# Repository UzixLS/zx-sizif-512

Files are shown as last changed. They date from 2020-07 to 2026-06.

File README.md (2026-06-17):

## Sizif-512
Another CPLD-based ZX Spectrum clone for 48K rubber case with some sweet features.

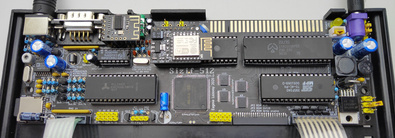
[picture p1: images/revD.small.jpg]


### Tech specs
* Half-sized PCB for 48K rubber case
* Pentagon, Spectrum 128, Spectrum 48 and Spectrum +3e modes
* Altera EPM1270 CPLD
* Real Z80 in 3.5MHz, 4.4MHz, 5.2MHz, 7MHz (no-wait turbo) and 14MHz (turbo with wait-states) modes
* 512K RAM
* Real AY-3-8910 with switchable stereo ABC/ACB/mono output
* Sega 6-button joystick input; Kempston/Sinclair modes
* Integrated DivMMC and Z-Controller, 1x microSD socket
* PAL and RGB video output (Sega Mini-DIN/9 connector)
* Digital video output header for EGA monitors, VGA scandoublers, etc.
* ULAplus
* Mono covox (Pentagon ans SpecDrum standards)
* SounDrive (4-channel stereo covox)
* WiFi addon ([link](https://github.com/UzixLS/zx-sizif-512-wifi))
* Tape input via 3.5" jack and Bluetooth
* 9-12V power supply with any polarity
* Reset and Magic buttons; header for power button

With extension board ([link](https://github.com/UzixLS/zx-sizif-512-ext)) more features may be added:
* Turbo Sound FM
* General Sound (12MHz / 512Kb RAM)
* SAA1099
* MIDI sound

### Demonstration
Running Pentagon and Spectrum 128 demos: [link](https://www.youtube.com/watch?v=_RoLKcfJSTY) \
Playing music from SD: [link](https://www.youtube.com/watch?v=TmikKD3yqOU) \
Some random photos: [link](https://cloud.err200.net/index.php/s/73TR85tYZkMm8Ax?path=%2Fsizif-512) \
Review by Martin's 8-bit blog (in czech): [link](https://www.8bity.cz/2020/zx-spectrum-clone-with-cpld-ulaplus-sizif-512/#) \
Review by The Retro Shack youtube channel: [link](https://www.youtube.com/watch?v=l5IgQTgq_bg) \
Building from scratch experience in Terence Ang's blog: [part1](https://www.terenceang.com/2021/08/28/building-a-zx-spectrum-clone-in-2021-begining/) [part2](https://www.terenceang.com/2021/08/29/building-a-zx-spectrum-clone-in-2021-sourcing-for-parts/) [part3](https://www.terenceang.com/2021/08/31/building-a-zx-spectrum-clone-in-2021-populating-the-board/)

### Magic button
Sizif has a number of configurable parameters that you can change on the fly. To do this just hold Magic button for a second.

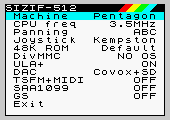
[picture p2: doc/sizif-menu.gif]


To navigate menu you can use up-down keys, to change value use enter or left-right keys. Kempston, Sinclair, Cursor and QAOP supported.

If you press Magic button for a short time, the standard NMI handler 'll be called.

### Sega gamepad buttons
Sega gamepad support will be available starting from PCB rev.D (or Rev.C with slight modifications).
| Button | Function in Kempston mode | Function in Sinclair mode |
| - | - | - |
| Right | Right (bit 0) | 7 |
| Left | Left (bit 1) | 6 |
| Down | Down (bit 2) | 8 |
| Up | Up (bit 3) | 9 |
| A | Button 3 (bit 6) | N |
| B | Button 1 (bit 4) | 0 |
| C | Button 2 (bit 5) | M |
| X | Turbo Button 3 (bit 6) | Turbo N |
| Y | Turbo Button 1 (bit 4) | Turbo 0 |
| Z | Turbo Button 2 (bit 5) | Turbo M |
| Start | Pause | Pause |
| Mode | Magic button | Magic button |

### PS/2 keyboard buttons
| Button | Function |
| - | - |
| F1 | Pause |
| F2 | Fast forward |
| F5 | Magic button |
| F10 | Reboot |
| F12 | Reboot |
| Ctrl+Alt+Del | Reboot |
| Ctrl+Alt+Backspace | Reboot |
| Numpad 8, 2/5, 4, 6 | Joystick's up-down-left-right |
| Numpad 0/Enter | Joystick's fire |
| Alt | Joystick's fire |

### RAM
Sizif contains 512K RAM. There are two cases how to access it:
1. DivMMC enabled (SD card insert) - 128K available via 7FFDh port, 128K via DFFDh (Profi standart, most compatible with old 128K software) and 128K reserved for DivMMC.
2. No SD card present - 128K available via 7FFDh and 384K via DFFDh. Please note: ULAplus and Magic button shares one page of memory with DFFD port. If you run 512K-software, it's good idea not to use ULAplus and Magic.

Note that DFFDh port available only in Pentagon mode.

### SD card
Sizif have preinstalled esxDOS firmware, which provides ability to load TAP, TRD, SCL, Z80 files and save snapshots. To use this you should format SD cart to FAT32 or FAT16 and unpack latest esxDOS release ([link](http://www.esxdos.org/index.html)) to card. Also it's recommended to install Long Filename Browser ([link](https://spectrumcomputing.co.uk/forums/viewtopic.php?t=2553)) to card.

### Tested addons
* [AYX-32](https://github.com/tslabs/arm/tree/master/AYX-32) - OK
* BDI-ZX ver 2.0 MVcomp FDD interface - OK
* [ZX Dandanator! Mini 2.1](http://www.dandare.es/Proyectos_Dandare/ZX_Dandanator%21_Mini_EN.html) - OK
* [ZX TSid](https://github.com/UzixLS/zx-tsid) - OK
* [Multiface 128 1.00 by Steve Smith](http://projectspeccy.com/projects/) - OK (if SD card isn't insert)
* Noname +3DOS floppy controller - OK (since rev.D)
* [PLUS 2A FDD Interface](https://github.com/konkotgit/PLUS-2A-FDD) - OK (since rev.D)
* DivIDE 5.7d - OK (if SD card isn't insert)
* DMA 2.02 by ShamaZX - OK
* [Kempston + TurboSound interface](https://github.com/konkotgit/KTS) - OK
* [ZX-HD](https://www.bytedelight.com/?page_id=1800) - OK
* [ZX-VGA-JOY](http://zx-vga-joy.com/) - OK
* [Spectranet by ByteDelight](https://www.bytedelight.com/?page_id=3515) - OK
* Spectranet by ShamaZX (aka ZX Net 512) - OK
* ZXKit1 VGA converter (with [alternative firmware](https://github.com/UzixLS/zxkit1-vga-scandoubler-firmware)) - OK

### Changelog & current status
* Rev.A - first release. Please note the [errata](pcb/rev.A/ERRATA.ru.txt) (in russian).
* Rev.B - abandoned. Files kept for historical reason.
* Rev.C - BDI has been removed; improved video circuit; more capable CPLD; better power circuit; add mono AY mode. [Errata](pcb/rev.C/ERRATA.txt).
* Rev.C1 - fixed incorrect JTAG pinout; fixed incorrect silkscreen for power connector J3, tuned some circuit values. Everything seems to work. [Errata](pcb/rev.C1/ERRATA.txt).
* Rev.D:
    * added zxbus connector for in-case addons
    * added support for +3DOS floppy controller
    * added support for Sega 3/6-button gamepad
    * added PS/2
    * added Bluetooth tape input (via M18 module)
    * added alternative microSD card socket footprint
    * fixed compatibility with some keyboards
    * modified tape input circuit
* Rev.D1: minor changes in pcb layout
* Rev.E:
    * added fuse on power input
    * added protection diode on 5V power rail
    * rotated left keyboard connector by 180 degrees
    * replaced TRS audio connectors by TRRS with video output
    * changed C37,C38,C39 footprint to able to install film capacitors
    * improved compatibility with wireless sega gamepads - 3.3V power replaced by 5V
    * added ability to simultaneously install the power/reset keys together with the connectors
    * added jumper for wiring minidin-9 pin 4 with composite or sync output for compatibility with dirty scart cables
    * added ability to install full-height 4.43MHz crystal
    * all 0.5/0.3 vias replaced by 0.6/0.3
    * experimental: 74HCU04-based speaker amplifier replaced by LM386-based
    * experimental: 74HCU04-based tape input circuit replaced by LM311-based
    * experimental: 74HCU04-based crystal clock generator replaced by ICS501-based
* Rev.E1:
    * reverted experimental rev.E changes

### Acknowledgments
This work is inspired and based on a lot of other projects and would hardly have been successful without them:
* Harlequin ([link](https://www.facebook.com/groups/349470902442395/))
* Karabas-128 ([link](https://github.com/andykarpov/karabas-128))
* ZX Evolution ([link](http://nedopc.com/zxevo/zxevo.php))
* zx_ula verilog implementation ([link](https://opencores.org/projects/zx_ula))

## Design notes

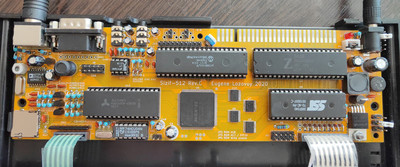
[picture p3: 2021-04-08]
images/revC.small.jpg

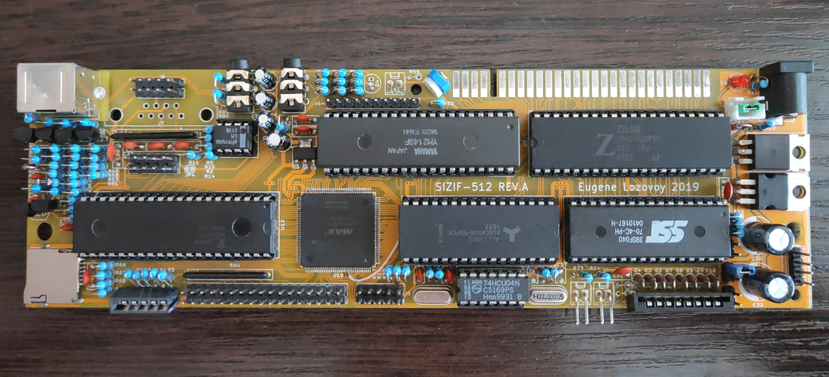
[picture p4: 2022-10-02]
images/revA.webp

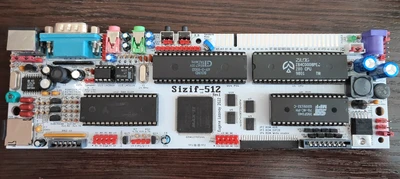
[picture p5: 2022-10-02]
images/revE.small.webp

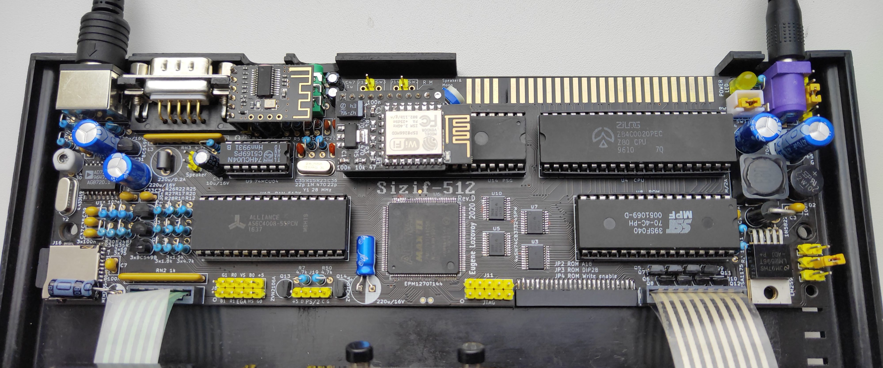
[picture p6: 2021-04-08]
images/revD.jpg

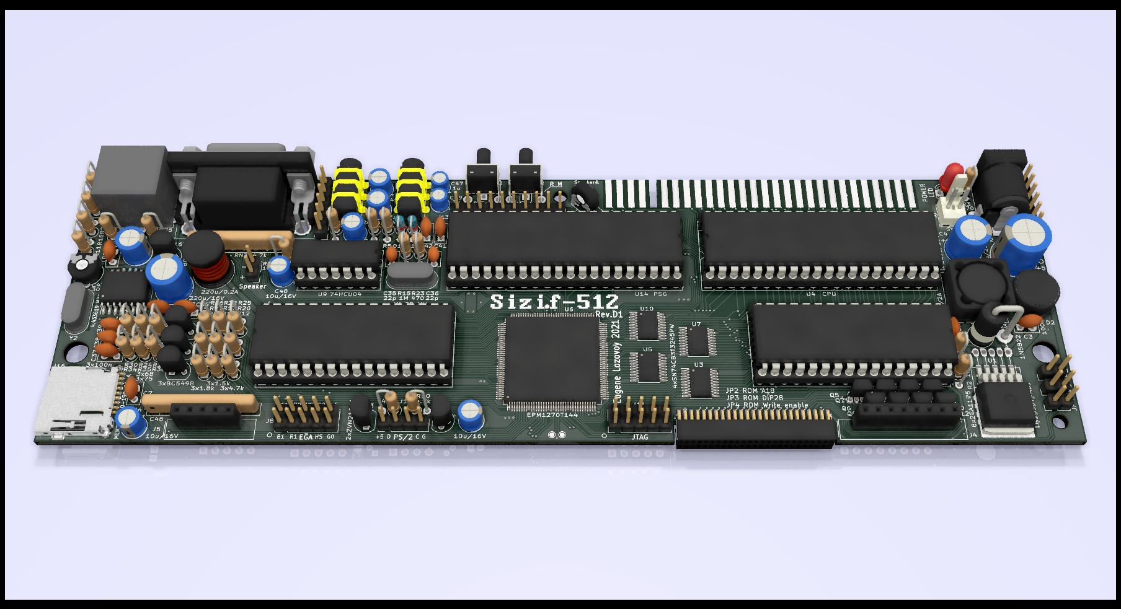
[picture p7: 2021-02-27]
out/pcb3d.rev.D1.png

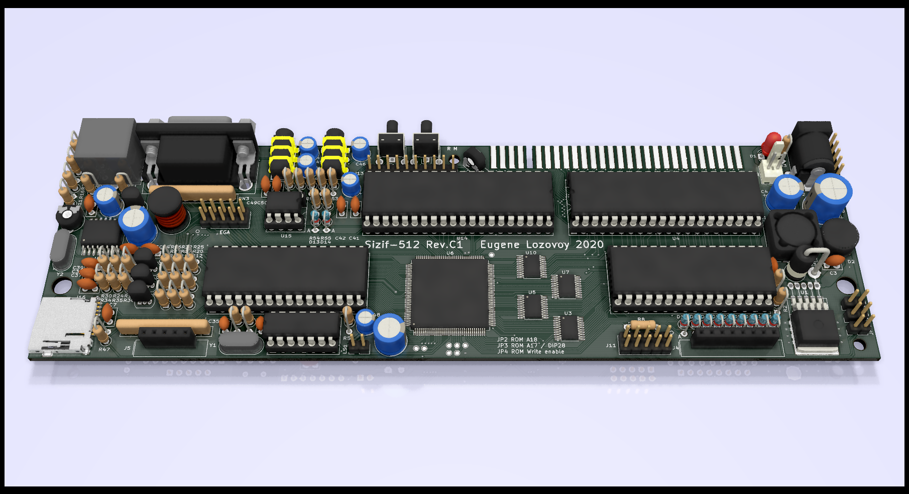
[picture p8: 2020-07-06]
out/pcb3d.rev.C1.png

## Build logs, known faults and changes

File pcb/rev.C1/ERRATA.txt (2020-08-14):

- R5 should not be installed (this improves compatibility with some addons like Dandanator mini)

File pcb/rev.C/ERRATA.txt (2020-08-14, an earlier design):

- JTAG pinout differs from Altera standard
- Incorrect silkscreen for J3 header
- R5 should not be installed (this improves compatibility with some addons like Dandanator mini)

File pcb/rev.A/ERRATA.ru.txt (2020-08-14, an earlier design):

- К ножке 22 микросхемы SRAM (U11) подключен VCC, должен быть GND
- К ножке 6 микросхемы ВГ93 (U12) подключен A8, должен быть A6
- CPUCLK нужно подтянуть к VCC через резистор 2.2k
- RSTCPU нужно подтянуть к VCC через резистор 10k
- Параллельно R71/C41, R72/C42 добавить резисторы 1k на землю, R80, R89 можно не впаивать
- Нерабочая схема подключения динамика, не впаивать Q4, R65, R55, RV1, LS1
- К ножке 132 CPLD (U11) нужно припаять сигнал A13, R41 не впаивать
- Вход магнитофона ловит шумы из космоса, ножку 3 LM311 (U5) нужно притянуть к GND через резистор 3M
- Неверная цоколёвка посадочного места у всех транзисторов - БЭК, должно быть КБЭ
- Разъём клавиатуры J1 не влезает если подключен шлейф флоппи
- Разъём джойстика J7 не влезает в корпус резинки без модификации корпуса
- Резистор R20 мешает установке разъёма клавиатуры J3, нужно припаивать резистор снизу
- Неверная распиновка разъёма J6 (Kempston)
- Неверная распиновка разъёма J8 (EGA)
- Схема сброса: R21 заменить на перемычку, R22 не впаивать
- Разъёмы SW2, SW3 не влезают по высоте, нужно впаивать угловые
- Перепутаны каналы A и B в цоколёвке AY (U13)
- В U4 нет необходимости, можно не запаивать. Ножки 7-6, 11-12, 5-4, 3-2, 9-10, 14-15 соединить перемычками
- C30, C32 не влезают по высоте, нужно устанавливать лёжа

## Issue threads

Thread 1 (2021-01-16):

футпринты транзисторов

andykarpov, 2021-01-16:
поменять бы, если можно, где ноги не так близко друг к другу :)

UzixLS, 2021-01-17:
На алиэкспрессе все BC547/BC549 с обычным, не широким футпринтом. Если поменять футпринт на плате, то придётся заниматься выгибанием ног. Зачем?)

UzixLS, 2021-01-17:
К тому же широкие 2SA1175 (которые в ревизии D на клавиатуре) в принципе не влезут на плату.

andykarpov, 2021-01-17:
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

Я про такой футпринт

andykarpov, 2021-01-17:
> К тому же широкие 2SA1175 (которые в ревизии D на клавиатуре) в принципе не влезут на плату.

А у 1175 ноги и так выгнуты с завода так, что совпадают с КТ361 практически :)

andykarpov, 2021-01-17:
> На алиэкспрессе все BC547/BC549 с обычным, не широким футпринтом. Если поменять футпринт на плате, то придётся заниматься выгибанием ног. Зачем?)

меньше шансов соплю повесить между ногами при монтаже :)

UzixLS, 2021-01-17:
> Я про такой футпринт
> меньше шансов соплю повесить между ногами при монтаже :)

Ок, принято. Будет в ревизии D1.

> А у 1175 ноги и так выгнуты с завода так, что совпадают с КТ361 практически :)

Не у всех. У меня такие https://aliexpress.ru/item/32510168613.html
КМК, вряд ли на их место просто так влезет какой-то больший футпринт:
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

UzixLS, 2021-03-01:
Закрыто коммитом 62a8de51fe858cffeb6807d12b4b5533df3119da

Closed 2021-03-01.

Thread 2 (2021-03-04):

Link for Harlequin

TheStruggleForAntiSpaghetti, 2021-03-04:
It would be nice to link to Don Superfo's Harlequin listing @ Sell My Retro here: (https://www.sellmyretro.com/offer/details/superfo-harlequin-128-zx-spectrum-128k-clone-new-version-4a-pcb-48417)

It also has a link to the schematics, etc.

 This way he will both be credited and possibly earn a buck for all of his work.

UzixLS, 2021-10-02:
Added link to facebook group.
a785ff44d2d07241bd08f201daa745f8490761d9

Closed 2021-10-02.

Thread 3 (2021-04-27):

Не работает клавиатура PS/2.

Alex-TV, 2021-04-27:
Собрал плату, подключил клавиатуру PS/2. При нажатии на клавиши нет реакции. Осциллографом проверил, сигналы от клавиатуры идут, после транзисторов тоже есть сигналы. Реакции на клавиатуру нет.

UzixLS, 2021-04-27:
В прошивке ПЛИС ещё не реализовано.

Alex-TV, 2021-04-27:
Понял, спасибо, буду ждать.

UzixLS, 2021-06-06:
Finally released in ee1f05f1f38bb661430069a9865b5a2dc1e8d80a

Closed 2021-06-06.

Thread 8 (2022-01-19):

RGBS Jitters every few seconds.

terenceang, 2022-01-19:
Hi,

Once again thanks for this great project/

RGBS video jitters every few secs, it happens on both Sizif that I built.
The is sent from the Sizif video out to a GBS=Control upscaler, image is nice, sharp and clean except for the jitters.
Video is in PAL mode and GBS-Control detects it correctly as PAL.
Jitter also doesn't happen with my other game consoles.
Here is a clip of the jitter - https://youtu.be/2h-cfVabX18

Thanks in advance.
Terence

UzixLS, 2022-01-20:
Hello
I've never dealt with GBS. I suppose there is some incompatibility with Pentagon video signal timings, which is going beyond PAL specifications. Can you check in 48K and 128K modes?

terenceang, 2022-01-20:
Actually, The Pentagon timing is the only 1 that works, the others won't even lock.

UzixLS, 2022-01-20:
Ouch, that's unexpected. 48K timings are best in terms of compatibility with TVs.
Are you using latest firmware? How GBS is connected to Sizif? Is your TV/Monitor supports 50Hz? Can you check frequency on 74HCU clock output? There is should be 28 MHz exactly.

terenceang, 2022-01-20:
sadly, the clock is not 28Mhz exactly. it jitters at 27.78, 28.04, 28.09.

terenceang, 2022-01-21:
It think I my 74HCU04 might be the problem, the China seller might have give me 74HC04. Let me double check. Thanks.

terenceang, 2022-01-21:
is the clock out from 74HCU04N supposed to be a Square wave? mine is a sine wave. Ordering some 74HCU04 to try.

UzixLS, 2022-01-21:
This may be caused by oscilloscope bandwidth limitation.

terenceang, 2022-01-21:
I have a RIGOL DS1052E. will it measure 28Mhz properly?

UzixLS, 2022-01-21:
No

Closed 2023-04-04.

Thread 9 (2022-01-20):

8bitdo Retro Receiver locks up the system.

terenceang, 2022-01-20:
https://www.8bitdo.com/retro-receiver-genesis-mega-drive/

Test the Sizif 512K with a Retro Reciever for SEGA MegaDrive crashes and locks up the system. I need to turn the machine on and off to get it back.

UzixLS, 2022-01-20:
Is 3.3V power line stable?

UzixLS, 2022-01-20:
I think this RF dongle maybe drawing too much power. I would buy one for tests probably.

terenceang, 2022-01-20:
where in the world are you located? I can order 1 and have it shipped to you.
It can literally work with any BT controller.
https://download.8bitdo.com/Manual/Receiver/md/MD_RR_ENG_Manual.pdf

UzixLS, 2022-01-20:
This isn't required.

After googling a bit, I found complaints about the compatibility of 8bitdo controllers with zx-uno:
https://www.zxuno.com/forum/viewtopic.php?t=3972

This may be caused by the same reason - zx uno like sizif provides only 3.3V power for gamepad.

terenceang, 2022-01-21:
I tried powering it through USB, it didn’t crash the system when you plug it in and crashes intermittently.
It will be nice if it works, i will order the 2.4Ghz ver to try out. Thanks

terenceang, 2022-01-21:
Anyway, I would love to send 1 to you if you want to work on it, at least to thank you for the hard work and wonderful design.

UzixLS, 2022-03-20:
I bought 8BitDo M30 gamepad with Megadrive Bluetooth receiver and it's works just flawlessly with Sizif-512 (rev.D). So I assume there is some issue with your hardware.

UzixLS, 2022-10-05:
PCB rev.E released with +5 power for gamepad. This should eliminate any theoretical incompatibilities.

Closed 2022-10-05.

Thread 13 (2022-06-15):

Looks like one connection is missing in the PCB Editor?

AmiManga, 2022-06-15:
Looks like there is one connection missing +3V3. PCB Editor is showing white line.
Maybe I am missing something?

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

R.

UzixLS, 2022-06-16:
These 2 pins are connected internally in 1117 ldo. Unfortunately there is no way to tell Kicad "dont worry, its okay".

AmiManga, 2022-06-17:
Got it. I was just checking. :)
Awesome project btw. Great schematics!

Closed 2022-06-17.

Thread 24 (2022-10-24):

Potential Component damage if using long TRRS plugs.

Mr-JimmyDeath, 2022-10-24:
Hello.

Awesome project, I keep getting asked to build these for people so have made a few now.

Whilst building/testing the E1 version I have spotted a potential issue regarding the TRRS connectors. I have found some TRRS plugs that are long enough that when fully inserted will project beyond the end of the PJ-322 socket (J12) and break diodes D11, D15. I have mitigated this issue by fitting SMD diodes under the PCB.

Suggest moving D11, D15 away from back of socket (or using SMD parts).

To a lesser extent this could affect J15 if accidentally plugged in there, so you could also consider moving  R47 & C51.

Thanks, Regards

James

UzixLS, 2022-10-25:
Hello.
Thanks for report.
Could you take a photo with inserted long TRRS plug?

Mr-JimmyDeath, 2022-10-25:
Hello.

Pictures attached are:

1. Comparison with standard 3.5mm Stereo plug
2. Plug fully inserted into socket and projecting beyond. Clearly it won't work like this.
3. My temp solution of SMD Diodes underneath

Regards
James
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

UzixLS, 2022-10-27:
Thanks for detailed photos. I've never seen so long plugs in wild.
Isn't mounted THT diodes would be strong enough to prevent long plug insertion?

Mr-JimmyDeath, 2022-10-29:
Hi.

I was using glass 1N4148 diodes, one broke as soon as I inserted the plug. I did consider mounting them with the lead closest to the socket but then then you would need to insulate the leads to prevent them shorting to the plug which seemed a lot more effort than mounting some underneath.

Regards

James

UzixLS, 2022-11-01:
Accepted, will be fixed in next revision.

andykarpov, 2022-11-03:
BTW, what's the profit to insert a TRRS plug into the normal TRS socket?

Mr-JimmyDeath, 2022-11-03:
There isn't if you are using D1 and earlier boards however, the E1 boards uses TRRS sockets, socket J12 will give you audio L & R plus composite video.

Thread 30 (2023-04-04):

cpld.rev.D.pof PCB ref D

Tomek474, 2023-04-04:
Hello,
I have a problem with cpld.rev.D.pof batch dated 03.04.2023, AY is not working. AY in tests is not detected and the thanks is a terrible noise.

Batch cpld.rev.D.pof dated 30.08.2022 works correctly AY

What is the problem ? has something changed in the wiring diagram ?

Greetings very much

UzixLS, 2023-04-04:
Where did you get all these files from?
Official pof files located at https://github.com/UzixLS/zx-sizif-512/releases , and there is no 03.04.2023 and 30.08.2022 releases.

Tomek474, 2023-04-04:
[AY_cpld.rev.D.zip](https://github.com/UzixLS/zx-sizif-512/files/11152849/AY_cpld.rev.D.zip)

I downloaded the file from GITHUB once when there was no E version yet
and now I noticed that there is a newer pof when there is an E version

I have attached both files, maybe you will be able to recognize what version they are.

Tomek474, 2023-04-04:
it seems to me that v20211204 is AY O.K
and v20221002 is AY BAD
something has changed in Altera software for D version

Tomek474, 2023-04-04:
> Where did you get all these files from? Official pof and rom files located at https://github.com/UzixLS/zx-sizif-512/releases , and there is no 03.04.2023 and 30.08.2022 releases.

it's probably the dates of downloading files by me

UzixLS, 2023-04-05:
I'm not sure why this is happening with your PCB as I haven't had any problems.
There is only one change around AY between v20211204 and v20221002. I reverted it, try this version: [rev_D.zip](https://github.com/UzixLS/zx-sizif-512/files/11155642/rev_D.zip)

Tomek474, 2023-04-05:
I checked, AY works correctly behind the proposed insertion.
Thank you, is this file compatible with Firmware v20221002 ?

UzixLS, 2023-04-06:
Yes, it's based on v20221002, but with reverted commit c26baf8e2c0e4bc6483cb4d750b199ec976fb1f5.
It fixes AY operations when turbo mode enabled, so I don't want to revert this commit in master branch.
I have no idea why it's breaking in your case, probably I should find more various AY chips to reproduce this problem.
Can I ask you to take photo of your AY and Z80?

Closed 2024-10-02.

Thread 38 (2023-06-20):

SVF files

acid-maker, 2023-06-20:
Can you provide SVF files in release page. I have Mac and can program CPLD using OpenOCD, but I need SVF file, not POF file.

acid-maker, 2023-06-20:
Can you provide SVF files in release page. I have Mac and can program CPLD using OpenOCD, but I need SVF file, not POF file.

UzixLS, 2023-06-21:
For which pcb revision you need svf file?

acid-maker, 2023-06-27:
I need SVF file for rev C1. I was able to create one myself using Quartus on Linux machine (it was very old version - 13.0). I've used OpenOCD on Mac and connected Sizif using USBBlaster (cheap version from Ali). Chip has been programmed correctly or at least it seemed so. I've also reprogrammed ROM chip. Everything seemed to be ok at the beginning, but my Sizif became very unstable. Previously it worked fine (I had very old firmware/ROM - the one without OSD), but now I'm unable to set 14Mhz - it freezes totally. 7MHz is max - then when I press right arrow it freezes. Also on standard 3.5MHz it works fine but only for couple of minutes and then it starts to work very unstable. I don't think that my SVF file causes that. I think that a wrong SVF file would rather brick the device. Any ideas? What to check?

Also it would be nice to have SVF files together with POF on your release page for all versions, also in the future. SVF file is "stupid" file with all JTAG "instructions" and therefore can be used with any JTAG programmer and any computer.

UzixLS, 2023-06-29:
May be something wrong with your quartus setup? Try this files:
[cpld firmware](https://github.com/UzixLS/zx-sizif-512/files/11902487/cpld.rev.C.fw-20221002.svf.zip)
[rom image](https://github.com/UzixLS/zx-sizif-512/releases/download/fw-20221002/rom.rev.C.rom)

I think it's good idea to officially provide svf file. I will do this for upcoming releases if I would confirm that SVF file works at least for you.

UzixLS, 2023-09-22:
Closed due to inactivity

Closed 2023-09-22.

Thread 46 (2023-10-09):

BOM in xlsx format (Sizif-512 E1)

Magnetrix, 2023-10-09:
Hello,
PCBWay requires the bom file in xlsx format...
Do you have such file ????

Thank you

UzixLS, 2023-10-09:
There currently is no BOM file suitable for PCBWay assembly service. As far as I know, they need not just an xlsx file, but a specification with part numbers from their own catalog. It would take a lot of time to create it, and I have not interest to do this job.
But you are free to make it yourself using existing pdf or html BOM.

Magnetrix, 2023-11-17:
Thanks anyway

Closed 2023-11-17.

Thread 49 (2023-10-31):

Possible wrong connection in MIC jack (rev E1)

ZbeeGin, 2023-10-31:
I think the MIC jack has wrong _VID_MIC_ connection. The signal goes to the sleeve.
I didn't see any TRRS Jack to 3xRCA AV cable, which have connection like this.

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

IMHO the _VID_MIC_ signal should be connected to the second ring, and GND to the sleeve. Like this:

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

UzixLS, 2023-10-31:
Sizif (like all other my pcbs) uses same pinout as Raspberry Pi for AV cable.
I bought two cables in local store and had no any issues.

ZbeeGin, 2023-11-08:
It seems there are two leading standards for AV Jack connection.
First: **OMTP** where tip is left audio, first ring is right audio, second ring is video(mic) and finally sleeve is the ground.
Second: **CTIA** where audio is the same as above, then second ring is ground and sleeve is the video(mic).

Unofrtunatelly I have only OMTP cable, because there are more of them on the market. At least in my country and nearest stores...

Closed 2024-01-09.

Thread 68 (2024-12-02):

8bit-Do M30 Controller Not Fully Functional

Big-the-Fat, 2024-12-02:
I bought a Sizif-512 (revision E1) with the latest FW on it from eBay.  I tried to use an M30 2.4GHz controller but the MODE button isn't recognised.  Is there a way to remedy this?

UzixLS, 2024-12-02:
I have M30 Bluetooth version and it's forking fine. Not sure what may go wrong with M30 2.4GHz. I would suggest to switch gamepad into different modes (Xinput, Dinput, etc) and, if this does not help, update dongle firmware.

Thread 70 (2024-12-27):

28mhz oscillator

repetto74, 2024-12-27:
Hello,

Is it fine to use a 28.636Mhz oscillator instead of the 28Mhz liste in the BOM for the Sizif512 revision E1?

Thanks
Rick

UzixLS, 2024-12-30:
It's may or may not work depending of your TV-set tolerance.

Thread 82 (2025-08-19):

CPLD-CPU  / data lines

lotharek1977, 2025-08-19:
confirm please : external #FE devices / ps2 keyboard, sinclair joys, Protek/  will not work... as cpld gives  hard 1 on zx bus..  470ohm resistors between cpu/edge and ULA suggested :-) .  or Z output when kd[4:0] no change at FE read

lotharek1977, 2025-08-19:
Please, test external ps2 keyborad adapter... or any device with keybord joy mapped (report from my customer of woodpecker..) works fine in 128/48.  i try to help :-)

https://lotharek.pl/productdetail.php?id=384

andykarpov, 2025-08-21:
Why not to emulate an open collector output by driving **0** by **0** and **1** by **Z** state for the #FE port?
So all external devices will work even without the IORQGE signal handling.
@lotharek1977 , the firmware sources are open, so you can try to implement this and send a pull request here after success :)

UzixLS, 2025-08-21:
> Why not to emulate an open collector output by driving 0 by 0 and 1 by Z state for the #FE port?

Internal CPLD's pullups isn't enough for proper operation in 14MHz mode.

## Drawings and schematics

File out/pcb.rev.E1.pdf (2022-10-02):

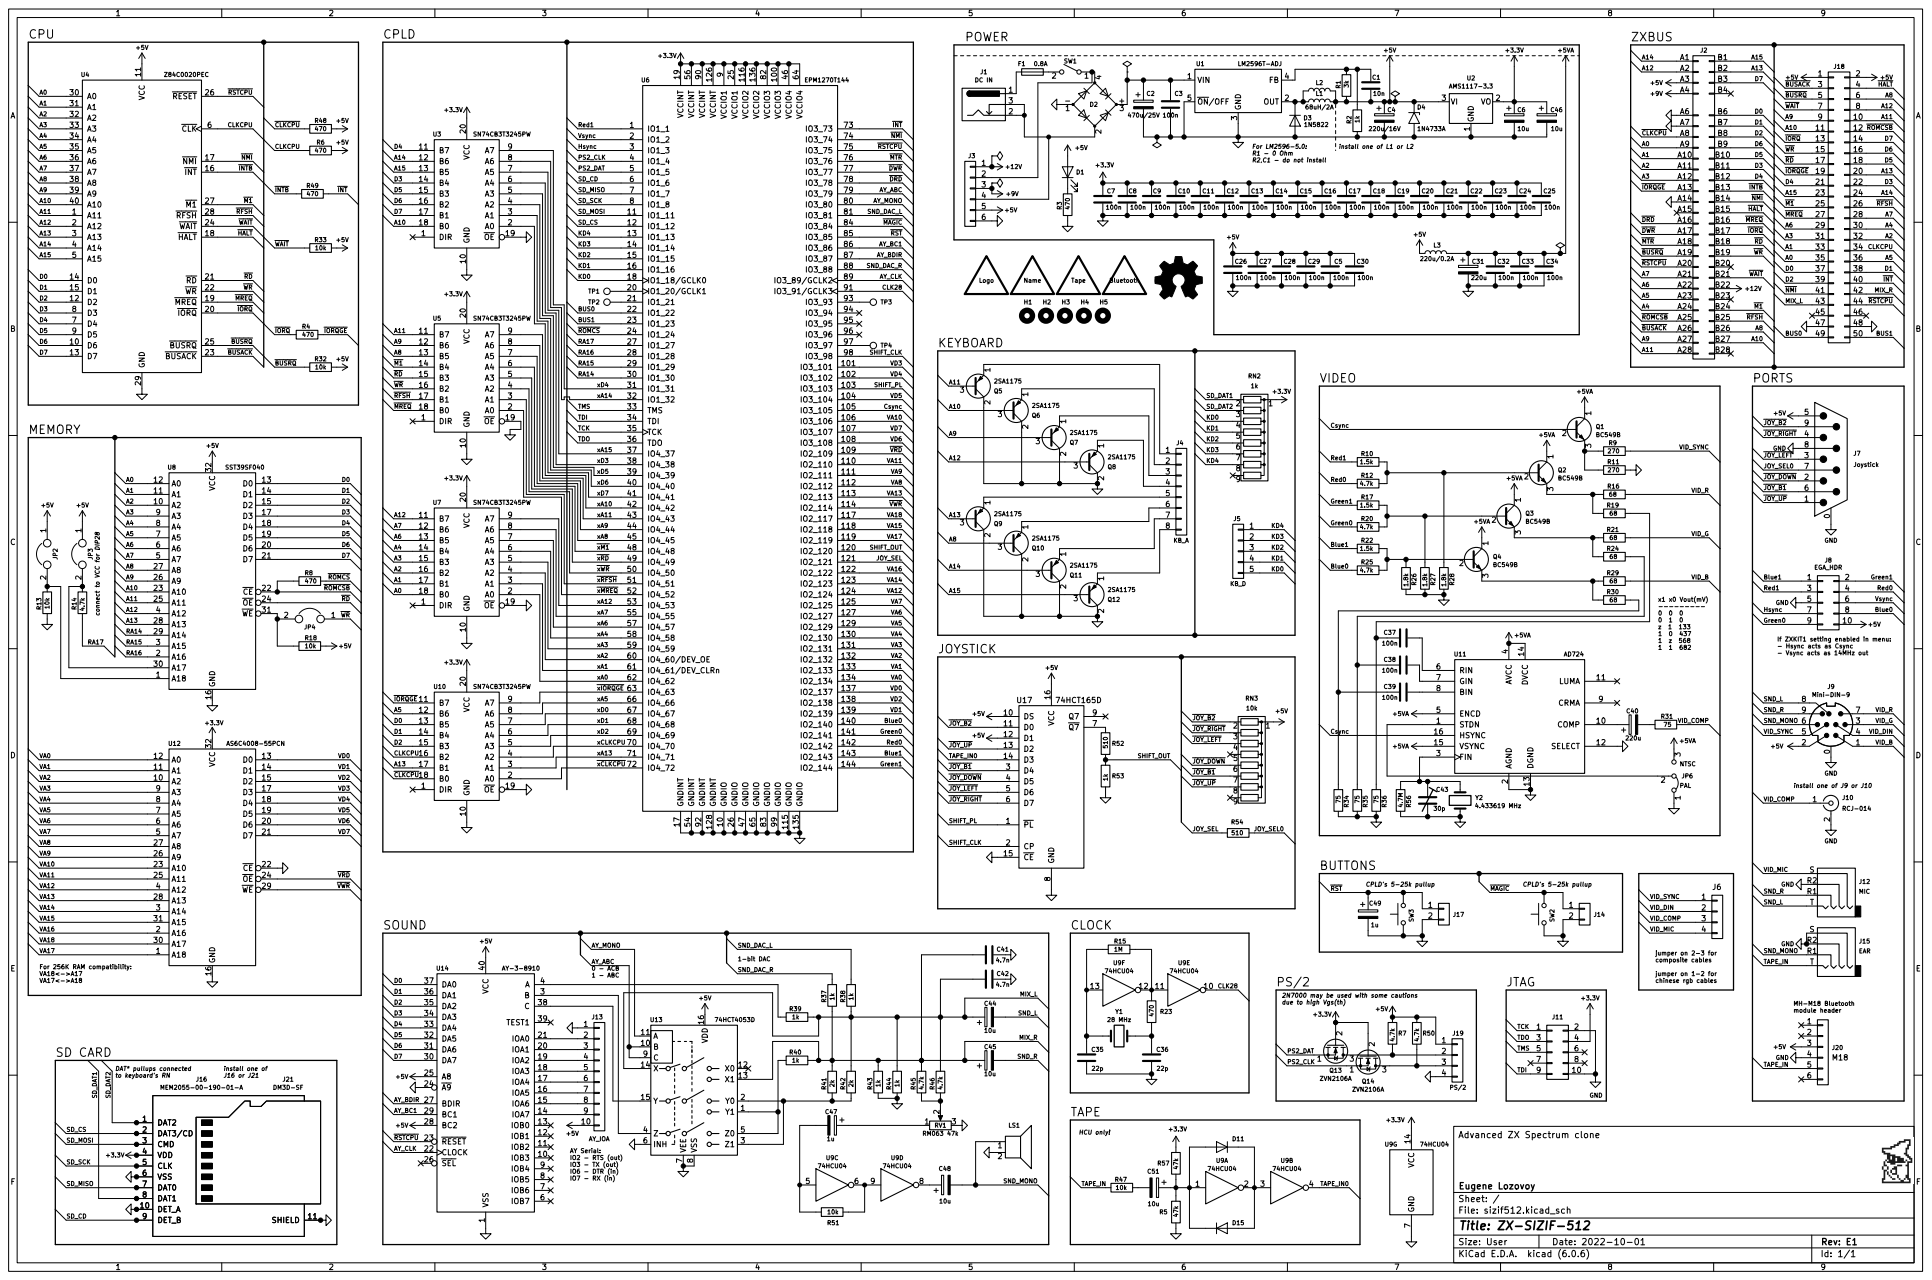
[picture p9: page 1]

install one of L1 or L2

If ZXKIT1 setting enabled in menu:
- Hsync acts as Csync
- Vsync acts as 14MHz out

install one of J9 or J10

2N7000 may be used with some cautions
due to high Vgs(th)

Advanced ZX Spectrum clone

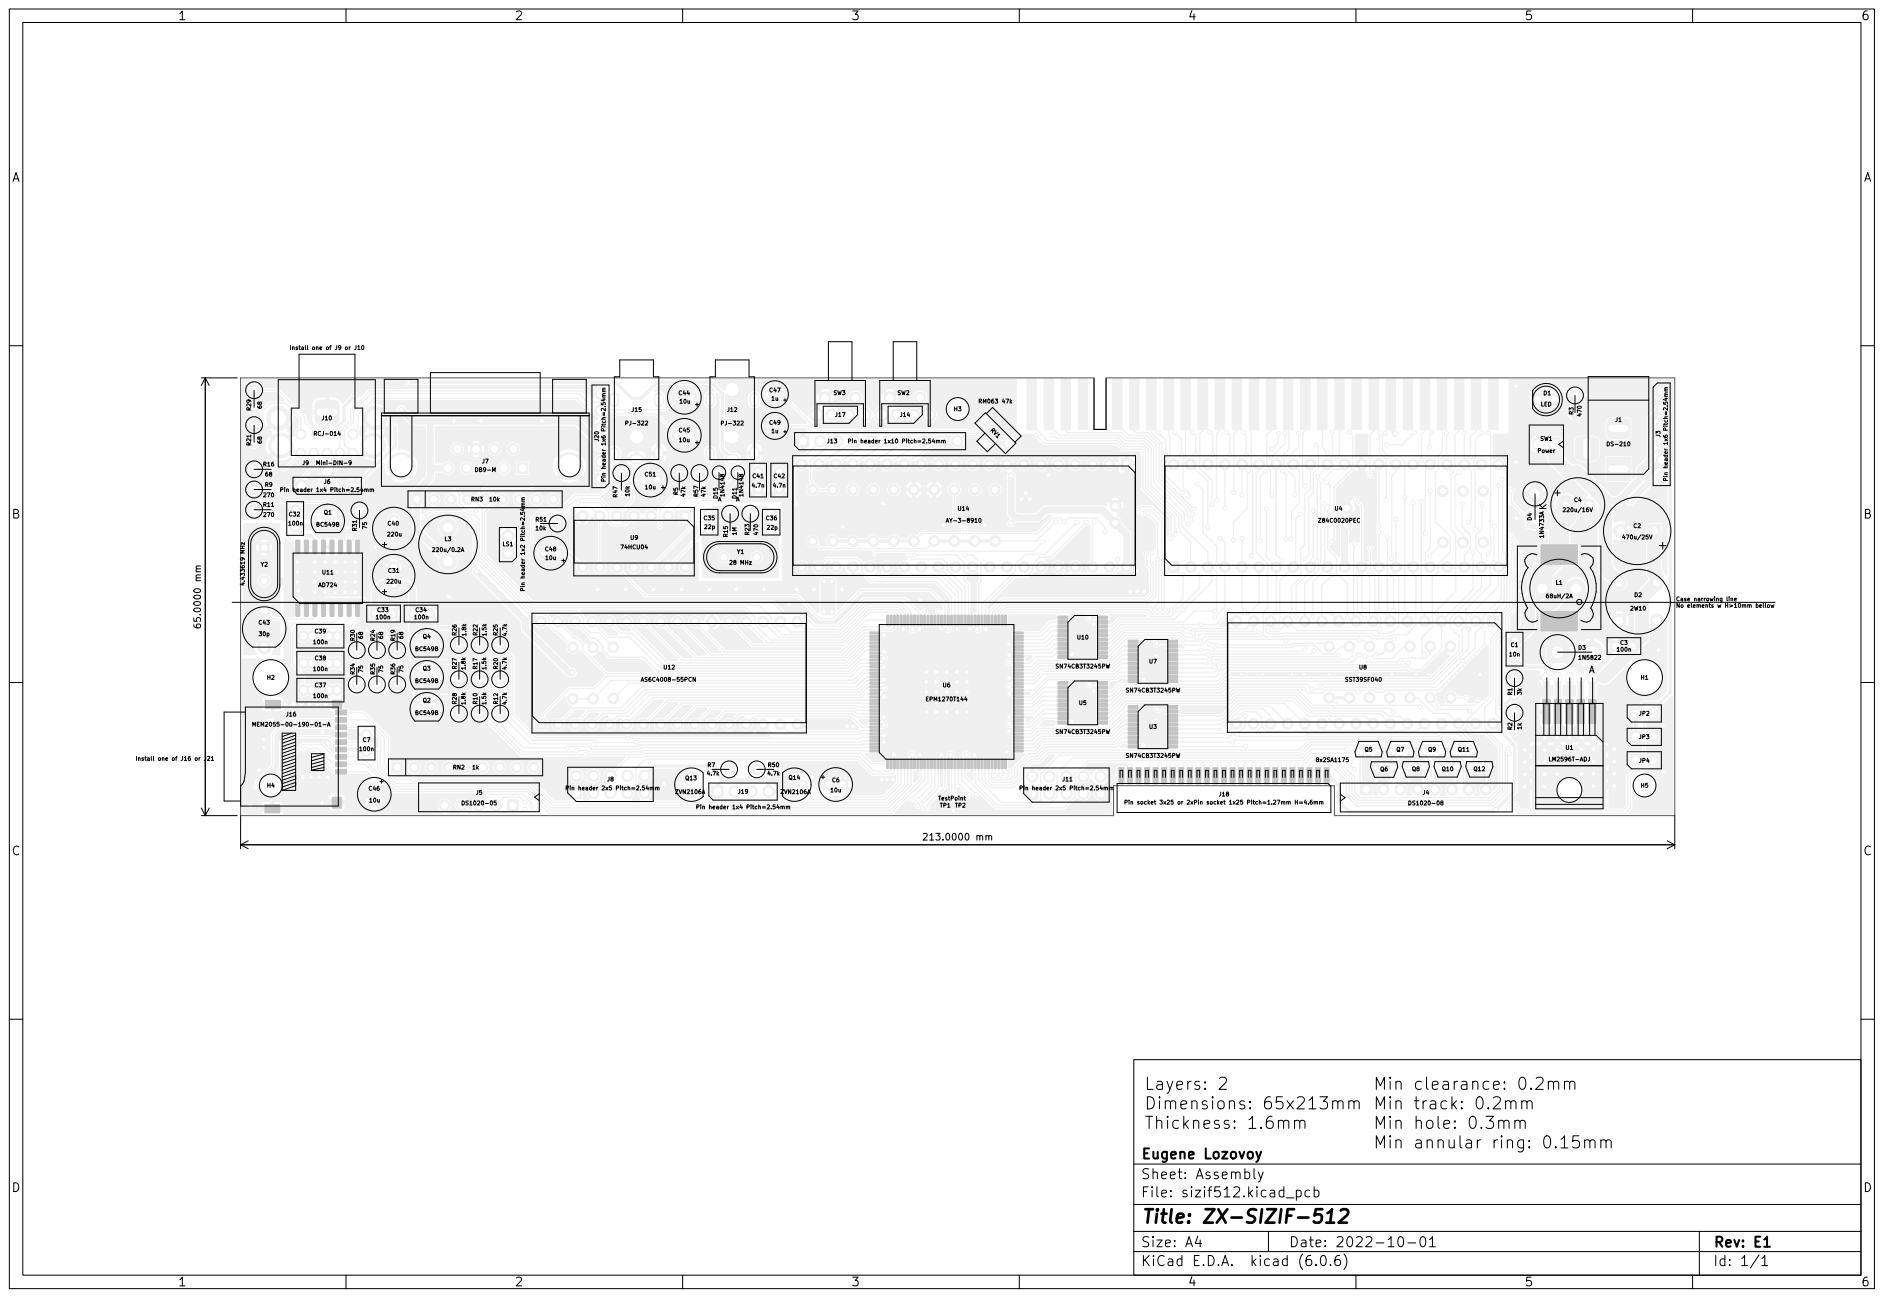
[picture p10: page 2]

Install one of J9 or J10

Install one of J16 or J21

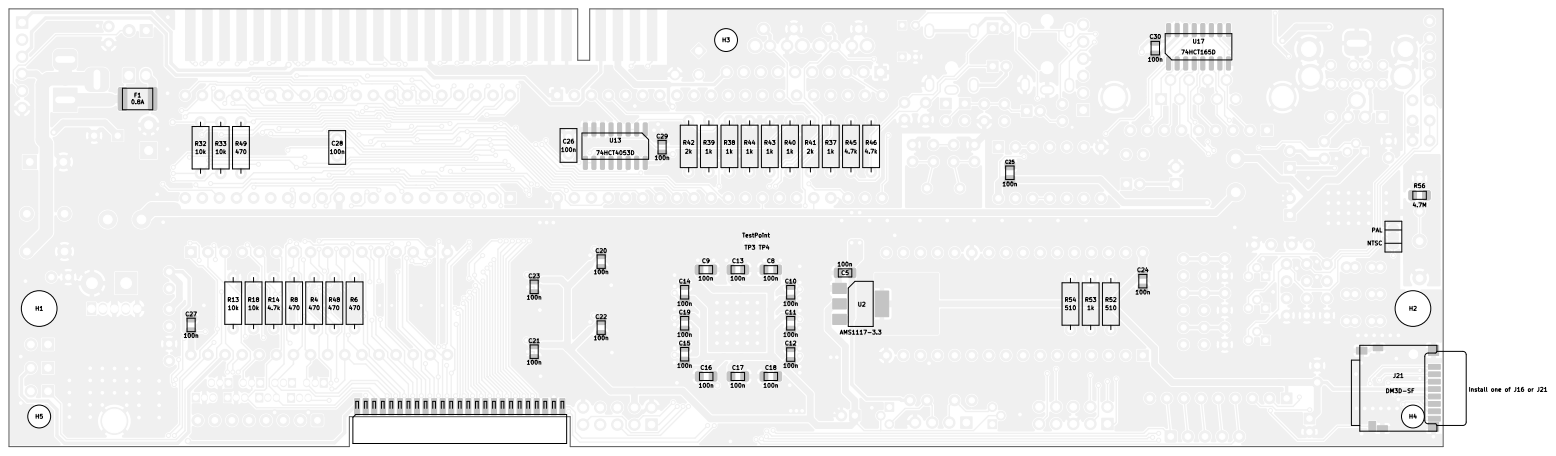
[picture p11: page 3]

R32 10k | R33 10k | R49 470 | C28 100n | U13 74HCT4053D | R42 2k | R39 1k | R38 1k | 1k

Install one of J16 or J21

Designator | Package | Value | Quantity
C1 | C_Disc_D5.0mm_W2.5mm_P2.50mm | 10n | 1
C2 | CP_Radial_D10.0mm_P5.00mm | 470u/25V | 1
C3, C7, C26, C28, C32, C33, C34 | C_Disc_D5.0mm_W2.5mm_P2.50mm | 100n | 7
C4 | CP_Radial_D8.0mm_P3.50mm | 220u/16V | 1
C5, C8, C9, C10, C11, C12, C13, C14, C15, C16, C17, C18, C19, C20, C21, C22, C23, C24, C27, C29 | C_0805_2012Metric_Pad1.15x1.40mm_HandSolder | 100n | 20
C6, C44, C45, C46, C48, C51 | CP_Radial_D5.0mm_P2.00mm | 10u | 6
C25, C30 | C_0805_2012Metric_Pad1.18x1.45mm_HandSolder | 100n | 2
C31, C40 | CP_Radial_D6.3mm_P2.50mm | 220u | 2
C35, C36 | C_Disc_D3.8mm_W2.6mm_P2.50mm | 22p | 2
C37, C38, C39 | C_Rect_L7.0mm_W3.5mm_P2.50mm_P5.00mm | 100n | 3
C41, C42 | C_Disc_D5.0mm_W2.5mm_P2.50mm | 4.7n | 2
C43 | C_Trim_D6.3mm_P5.50mm | 30p | 1
C47, C49 | CP_Radial_D4.0mm_P2.00mm | 1u | 2
D1 | LED_D4.0mm | LED | 1
D2 | Diode_Bridge_Round_D10.0mm | 2W10 | 1
D3 | D_DO-201AD_P5.08mm_Vertical_AnodeUp | 1N5822 | 1
D4 | D_DO-15_P3.81mm_Vertical_KathodeUp | 1N4733A | 1
D11, D15 | D_DO-35_SOD27_P2.54mm_Vertical_AnodeUp | 1N4148 | 2
F1 | Fuse_1812_4532Metric_Pad1.30x3.40mm_HandSolder | 0.8A | 1
J1 | BarrelJack_Horizontal | DS-210 | 1
J3, J20 | PinHeader_1x06_P2.54mm_Vertical | Pin header 1x6 Pitch=2.54mm | 2
J4 | FFC_FPC_1x08 | DS1020-08 | 1
J5 | FFC_FPC_1x05 | DS1020-05 | 1
J6, J19 | PinHeader_1x04_P2.54mm_Vertical | Pin header 1x4 Pitch=2.54mm | 2
J7 | DSUB-9_Male_Horizontal_P2.77x2.84mm_EdgePinOffset4.94mm_H oused_MountingHolesOffset7.48mm | DB9-M | 1
J8, J11 | PinHeader_2x05_P2.54mm_Vertical | Pin header 2x5 Pitch=2.54mm | 2
J9 | minidin-9 | Mini-DIN-9 | 1
J10 | CUI_RCJ-01X-WIDE | RCJ-014 | 1
J12, J15 | PJ-322 | PJ-322 | 2
J13 | PinHeader_1x10_P2.54mm_Vertical | Pin header 1x10 Pitch=2.54mm | 1
J14, J17 | PinHeader_2x01_P2.54mm_Vertical | Pin header 1x2 Pitch=2.54mm | 2
J16 | GCT-MEM2055-00-190-01-A | MEM2055-00-190-01-A | 1
J18 | PinHeader_2x25_P1.27mm_Edge_SMD | Pin socket 3x25 or 2xPin socket 1x25 Pitch=1.27mm H=4.6mm | 1
J21 | microSD_HC_Hirose_DM3D-SF | DM3D-SF | 1
JP2, JP3, JP4 | PinHeader_1x02_P2.54mm_Vertical | Jumper / Pin header 1x2 Pitch=2.54mm | 3
L1 | L_Radial_D8.7mm_P5.00mm_Fastron_07HCP | 68uH/2A | 1
L2 | L_12x12mm_H8mm | 68uH/2A | 1
L3 | L_Radial_D8.7mm_P5.00mm_Fastron_07HCP | 220u/0.2A | 1
LS1 | PinHeader_1x02_P2.54mm_Vertical | Pin header 1x2 Pitch=2.54mm | 1
Q1, Q2, Q3, Q4 | TO-92 | BC549B | 4
Q5, Q6, Q7, Q8, Q9, Q10, Q11, Q12 | TO-92S | 2SA1175 | 8
Q13, Q14 | TO-92 | ZVN2106A | 2
R1 | R_Axial_DIN0207_L6.3mm_D2.5mm_P2.54mm_Vertical | 3k | 1
R2 | R_Axial_DIN0207_L6.3mm_D2.5mm_P2.54mm_Vertical | 1k | 1
R3, R23 | R_Axial_DIN0207_L6.3mm_D2.5mm_P2.54mm_Vertical | 470 | 2
R4, R6, R8, R48, R49 | R_Axial_DIN0207_L6.3mm_D2.5mm_P7.62mm_Horizontal | 470 | 5
R5, R57 | R_Axial_DIN0207_L6.3mm_D2.5mm_P2.54mm_Vertical | 47k | 2
R7, R12, R20, R25, R50 | R_Axial_DIN0207_L6.3mm_D2.5mm_P2.54mm_Vertical | 4.7k | 5
R9, R11 | R_Axial_DIN0207_L6.3mm_D2.5mm_P2.54mm_Vertical | 270 | 2
R10, R17, R22 | R_Axial_DIN0207_L6.3mm_D2.5mm_P2.54mm_Vertical | 1.5k | 3
R13, R18, R32, R33 | R_Axial_DIN0207_L6.3mm_D2.5mm_P7.62mm_Horizontal | 10k | 4
R14, R45, R46 | R_Axial_DIN0207_L6.3mm_D2.5mm_P7.62mm_Horizontal | 4.7k | 3
R15 | R_Axial_DIN0207_L6.3mm_D2.5mm_P2.54mm_Vertical | 1M | 1
R16, R19, R21, R24, R29, R30 | R_Axial_DIN0207_L6.3mm_D2.5mm_P2.54mm_Vertical | 68 | 6
R26, R27, R28 | R_Axial_DIN0207_L6.3mm_D2.5mm_P2.54mm_Vertical | 1.8k | 3
R31, R34, R35, R36 | R_Axial_DIN0207_L6.3mm_D2.5mm_P2.54mm_Vertical | 75 | 4
R37, R38, R39, R40, R43, R44, R53 | R_Axial_DIN0207_L6.3mm_D2.5mm_P7.62mm_Horizontal | 1k | 7
R41, R42 | R_Axial_DIN0207_L6.3mm_D2.5mm_P7.62mm_Horizontal | 2k | 2
R47, R51 | R_Axial_DIN0207_L6.3mm_D2.5mm_P2.54mm_Vertical | 10k | 2
R52, R54 | R_Axial_DIN0207_L6.3mm_D2.5mm_P7.62mm_Horizontal | 510 | 2
R56 | R_0805_2012Metric_Pad1.15x1.40mm_HandSolder | 4.7M | 1
RN2 | R_Array_SIP9 | 1k | 1
RN3 | R_Array_SIP9 | 10k | 1
RV1 | Potentiometer_Runtron_RM-063_Horizontal | RM063 47k | 1
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

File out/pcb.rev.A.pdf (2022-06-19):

CLOCK | KEYBOARD & JOYSTICK
CPU | TAPE INTERFACE

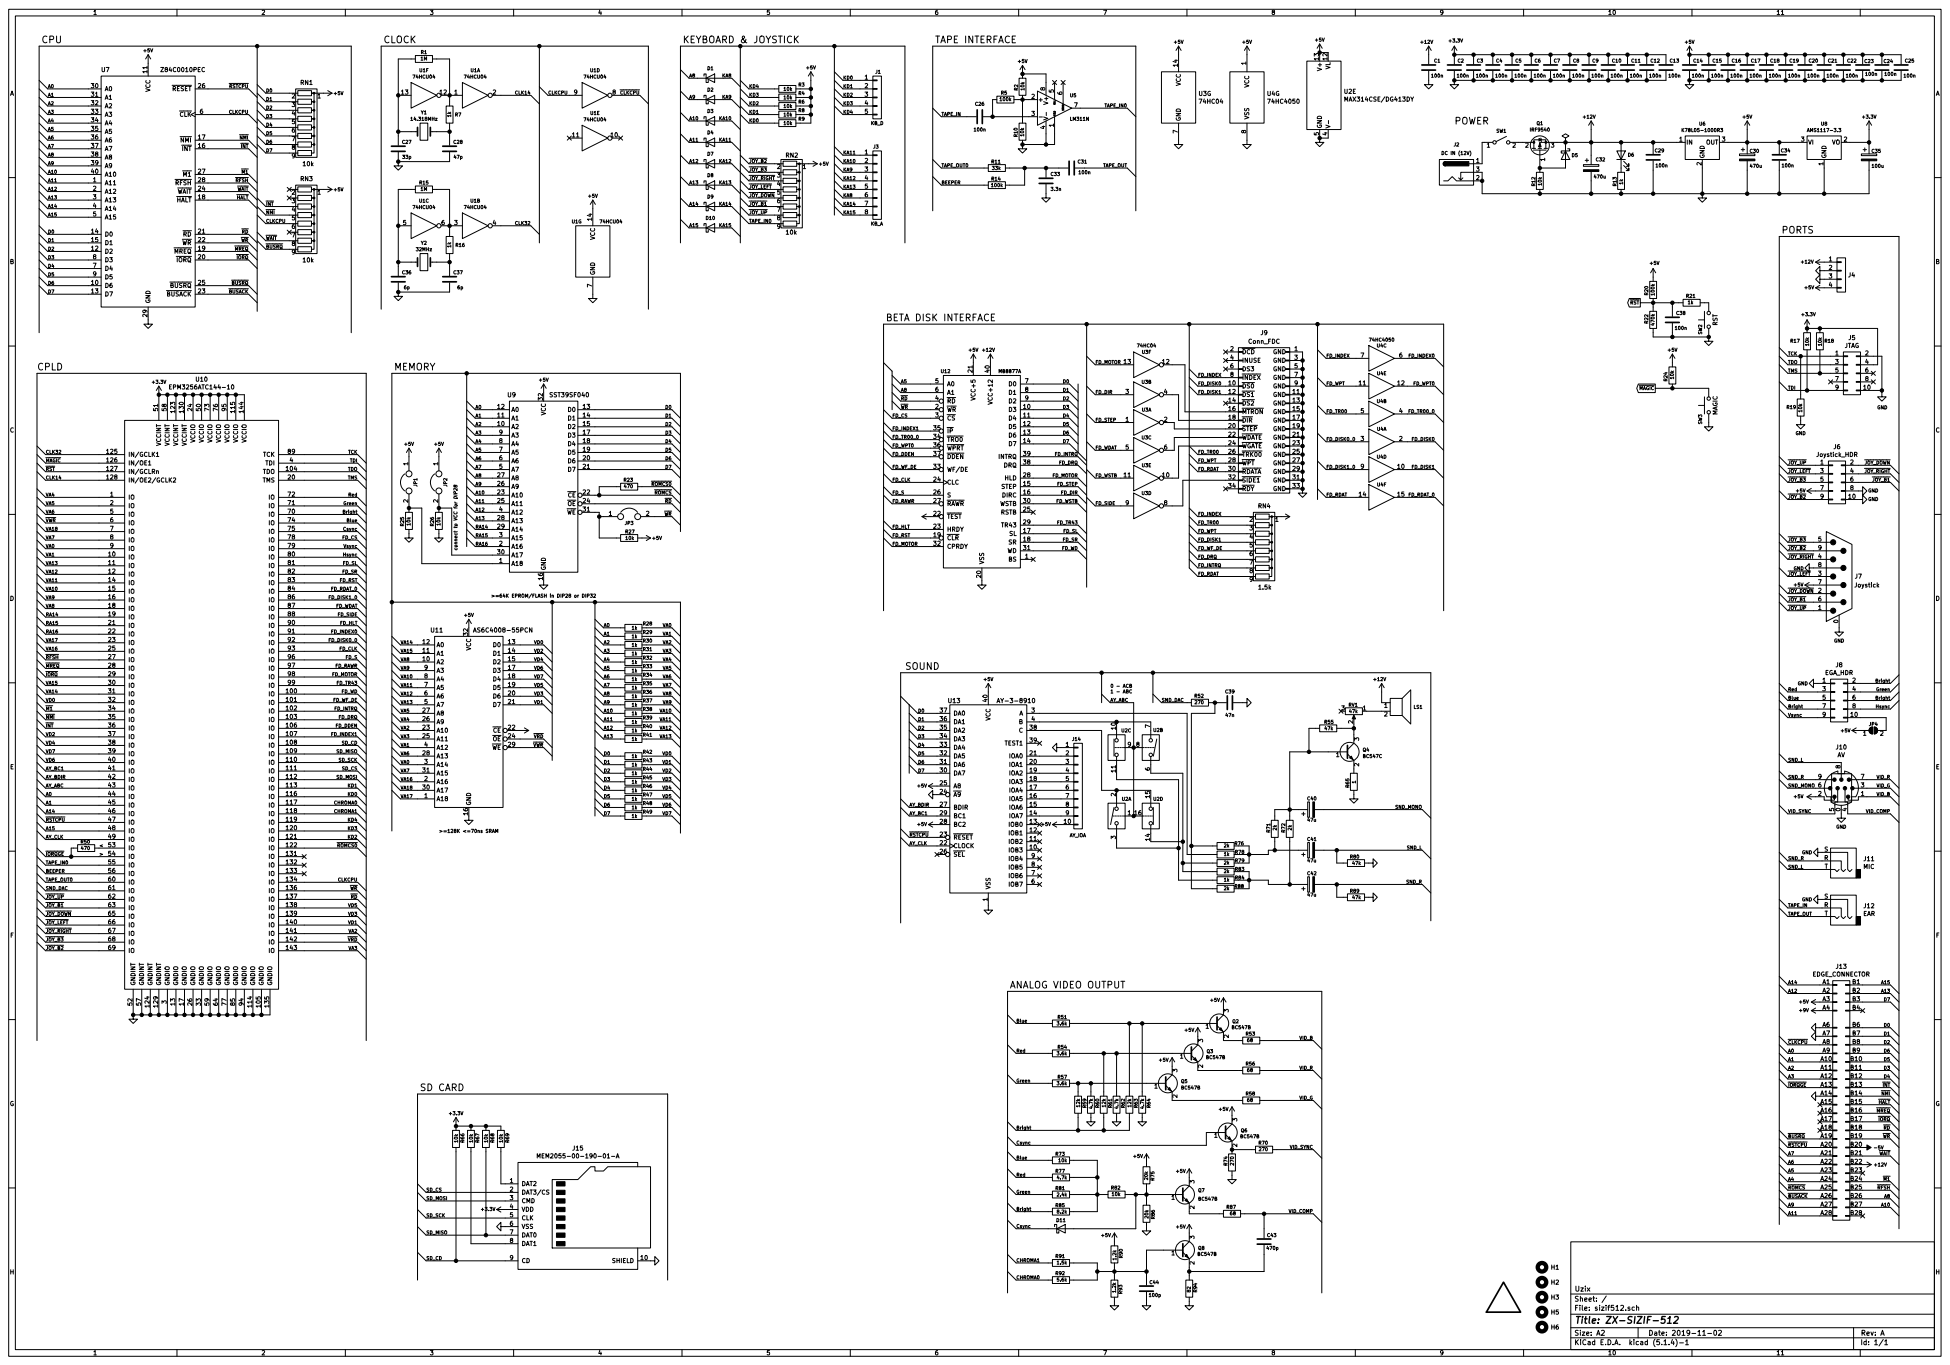
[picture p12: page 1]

connect to VCC for DIP28

>=64K EPROM/FLASH in DIP28 or DIP32

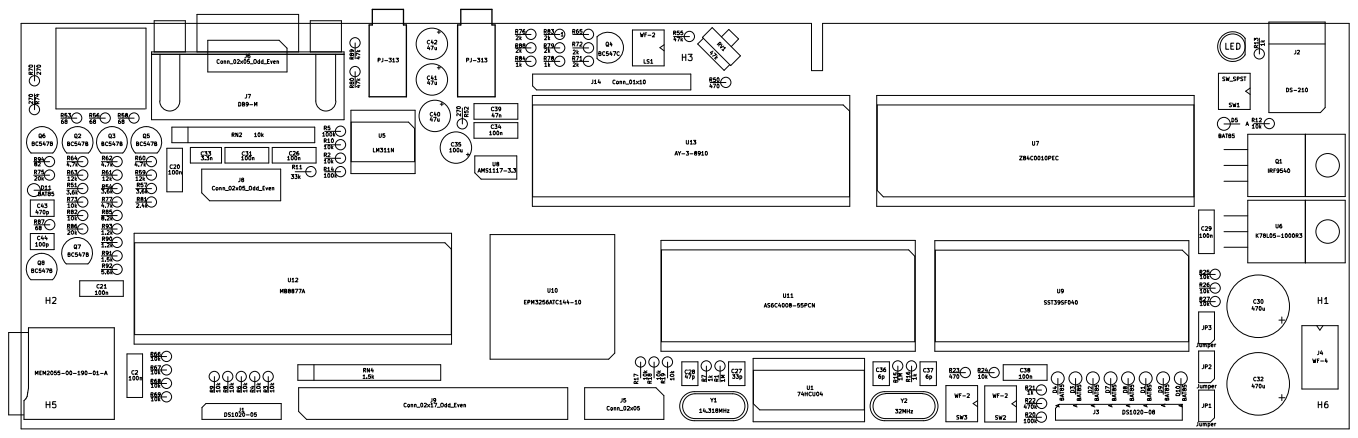
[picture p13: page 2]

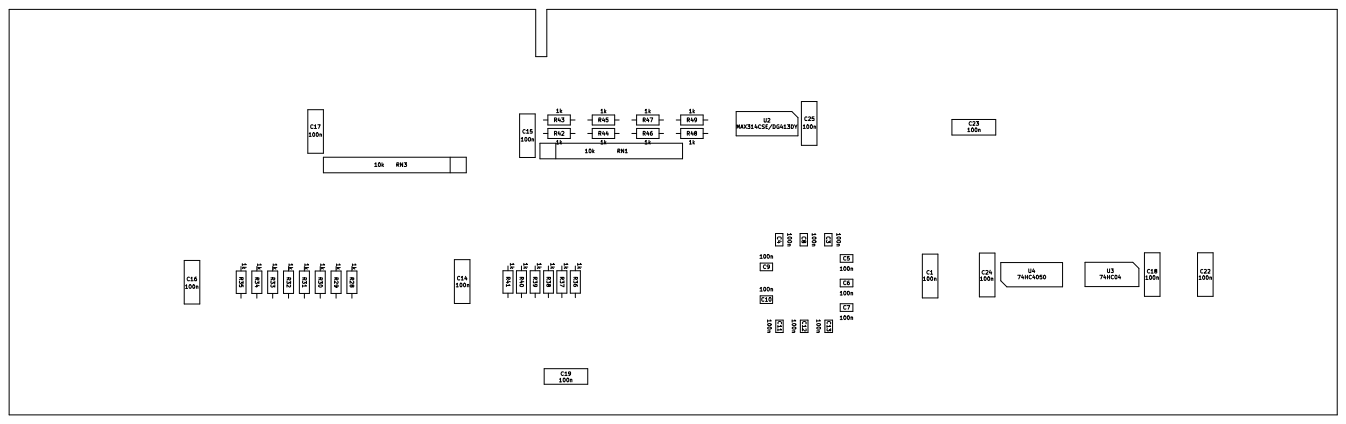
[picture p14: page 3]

Designator | Package | Designation | Quantity
C13,C12,C11,C10,C9,C8,C7,C6,C5,C4,C3 | C_0805_2012Metric_Pad1.15x1.40mm_HandSolder | 100n | 11
C2,C20,C25,C31,C24,C14,C38,C1,C34,C21,C18,C17,C16,C 23,C22,C19,C29,C26,C15 | C_Disc_D7.0mm_W2.5mm_P5.00mm | 100n | 19
C27 | C_Disc_D3.8mm_W2.6mm_P2.50mm | 33p | 1
C28 | C_Disc_D3.8mm_W2.6mm_P2.50mm | 47p | 1
C30,C32 | CP_Radial_D10.0mm_P3.80mm | 470u | 2
C33 | C_Disc_D5.0mm_W2.5mm_P2.50mm | 3.3n | 1
C35 | CP_Radial_D5.0mm_P2.50mm | 100u | 1
C37,C36 | C_Disc_D3.8mm_W2.6mm_P2.50mm | 6p | 2
C39 | C_Disc_D7.0mm_W2.5mm_P5.00mm | 47n | 1
C40,C42,C41 | CP_Radial_D5.0mm_P2.50mm | 47u | 3
C43 | C_Disc_D3.8mm_W2.6mm_P2.50mm | 470p | 1
C44 | C_Disc_D3.8mm_W2.6mm_P2.50mm | 100p | 1
D10,D9,D8,D7,D4,D3,D2,D1,D5,D11 | D_DO-35_SOD27_P2.54mm_Vertical_AnodeUp | BAT85 | 10
D6 | LED_D4.0mm | LED | 1
J1 | PinSocket_1x05_P2.54mm_Vertical | DS1020-05 | 1
J10 | minidin-9 | Mini-DIN-9 | 1
J11,J12 | PJ-313 | PJ-313 | 2
J14 | PinHeader_1x10_P2.54mm_Vertical | Conn_01x10 | 1
J15 | GCT-MEM2055-00-190-01-A | MEM2055-00-190-01-A | 1
J2 | BarrelJack_Horizontal | DS-210 | 1
J3 | PinSocket_1x08_P2.54mm_Vertical | DS1020-08 | 1
J4 | Molex_KK-254_AE-6410-04A_1x04_P2.54mm_Vertical | WF-4 | 1
J5 | PinHeader_2x05_P2.54mm_Vertical | Conn_02x05 | 1
J6,J8 | PinHeader_2x05_P2.54mm_Vertical | Conn_02x05_Odd_Even | 2
J7 | DSUB-9_Male_Horizontal_P2.77x2.84mm_EdgePinOffset4.94mm_Ho used_MountingHolesOffset7.48mm | DB9-M | 1
J9 | PinHeader_2x17_P2.54mm_Vertical | Conn_02x17_Odd_Even | 1
JP2,JP1,JP3 | PinHeader_1x02_P2.54mm_Vertical | Jumper | 3
LS1,SW3,SW2 | Molex_KK-254_AE-6410-02A_1x02_P2.54mm_Vertical | WF-2 | 3
Q1 | TO-220-3_Horizontal_TabDown | IRF9540 | 1
Q4 | TO-92_Inline | BC547C | 1
Q6,Q8,Q7,Q5,Q3,Q2 | TO-92_Inline | BC547B | 6
R11 | R_Axial_DIN0204_L3.6mm_D1.6mm_P2.54mm_Vertical | 33k | 1
R14,R20,R5 | R_Axial_DIN0204_L3.6mm_D1.6mm_P2.54mm_Vertical | 100k | 3
R15,R1 | R_Axial_DIN0204_L3.6mm_D1.6mm_P2.54mm_Vertical | 1M | 2
R22 | R_Axial_DIN0204_L3.6mm_D1.6mm_P2.54mm_Vertical | 470k | 1
R46,R49,R48,R29,R28,R47,R45,R44,R43,R42,R41,R40,R3 9,R38,R37,R36,R35,R34,R33,R32,R31,R30 | R_Axial_DIN0204_L3.6mm_D1.6mm_P5.08mm_Horizontal | 1k | 22
R50,R23 | R_Axial_DIN0204_L3.6mm_D1.6mm_P2.54mm_Vertical | 470 | 2
R52,R70,R74 | R_Axial_DIN0204_L3.6mm_D1.6mm_P2.54mm_Vertical | 270 | 3
R57,R54,R51 | R_Axial_DIN0204_L3.6mm_D1.6mm_P2.54mm_Vertical | 3.6k | 3
R60,R64,R62,R77 | R_Axial_DIN0204_L3.6mm_D1.6mm_P2.54mm_Vertical | 4.7k | 4
R63,R61,R59 | R_Axial_DIN0204_L3.6mm_D1.6mm_P2.54mm_Vertical | 12k | 3
R65 | R_Axial_DIN0204_L3.6mm_D1.6mm_P2.54mm_Vertical | 1 | 1
R66,R69,R68,R67,R24,R9,R8,R6,R4,R3,R27,R26,R25,R12, R10,R2,R18,R17,R19,R82,R73 | R_Axial_DIN0204_L3.6mm_D1.6mm_P2.54mm_Vertical | 10k | 21
R75,R86 | R_Axial_DIN0204_L3.6mm_D1.6mm_P2.54mm_Vertical | 20k | 2
R81 | R_Axial_DIN0204_L3.6mm_D1.6mm_P2.54mm_Vertical | 2.4k | 1
R84,R78,R21,R13,R16,R7 | R_Axial_DIN0204_L3.6mm_D1.6mm_P2.54mm_Vertical | 1k | 6
R85 | R_Axial_DIN0204_L3.6mm_D1.6mm_P2.54mm_Vertical | 8.2k | 1
R87,R53,R56,R58 | R_Axial_DIN0204_L3.6mm_D1.6mm_P2.54mm_Vertical | 68 | 4
R88,R83,R79,R76,R72,R71 | R_Axial_DIN0204_L3.6mm_D1.6mm_P2.54mm_Vertical | 2k | 6
R89,R80,R55 | R_Axial_DIN0204_L3.6mm_D1.6mm_P2.54mm_Vertical | 47k | 3
R91 | R_Axial_DIN0204_L3.6mm_D1.6mm_P2.54mm_Vertical | 1.5k | 1
R92 | R_Axial_DIN0204_L3.6mm_D1.6mm_P2.54mm_Vertical | 5.6k | 1
R93,R90 | R_Axial_DIN0204_L3.6mm_D1.6mm_P2.54mm_Vertical | 1.2k | 2
R94 | R_Axial_DIN0204_L3.6mm_D1.6mm_P2.54mm_Vertical | 82 | 1
RN1,RN2,RN3 | R_Array_SIP9 | 10k | 3
RN4 | R_Array_SIP9 | 1.5k | 1
RV1 | Potentiometer_Runtron_RM-063_Horizontal | 47k | 1
SW1 | Molex_KK-254_AE-6410-02A_1x02_P2.54mm_Vertical | SW_SPST | 1
U1 | DIP-14_W7.62mm_Socket | 74HCU04 | 1
U10 | TQFP-144_20x20mm_P0.5mm | EPM3256ATC144-10 | 1
U11 | DIP-32_W15.24mm_Socket | AS6C4008-55PCN | 1
U12 | DIP-40_W15.24mm_Socket | MB8877A | 1
U13 | DIP-40_W15.24mm_Socket | AY-3-8910 | 1
U2 | SOIC-16_3.9x9.9mm_P1.27mm | MAX314CSE/DG413DY | 1
U3 | SOIC-14_3.9x8.7mm_P1.27mm | 74HC04 | 1
U4 | SOIC-16_3.9x9.9mm_P1.27mm | 74HC4050 | 1
U5 | DIP-8_W7.62mm_Socket | LM311N | 1
U6 | TO-220-3_Horizontal_TabDown | K78L05-1000R3 | 1
U7 | DIP-40_W15.24mm_Socket | Z84C0010PEC | 1
U8 | SOT-223-3_TabPin2 | AMS1117-3.3 | 1
U9 | DIP-32_W15.24mm_Socket | SST39SF040 | 1
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

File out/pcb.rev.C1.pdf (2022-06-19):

# IO1_18/GCLK0 18 VCCINT 19

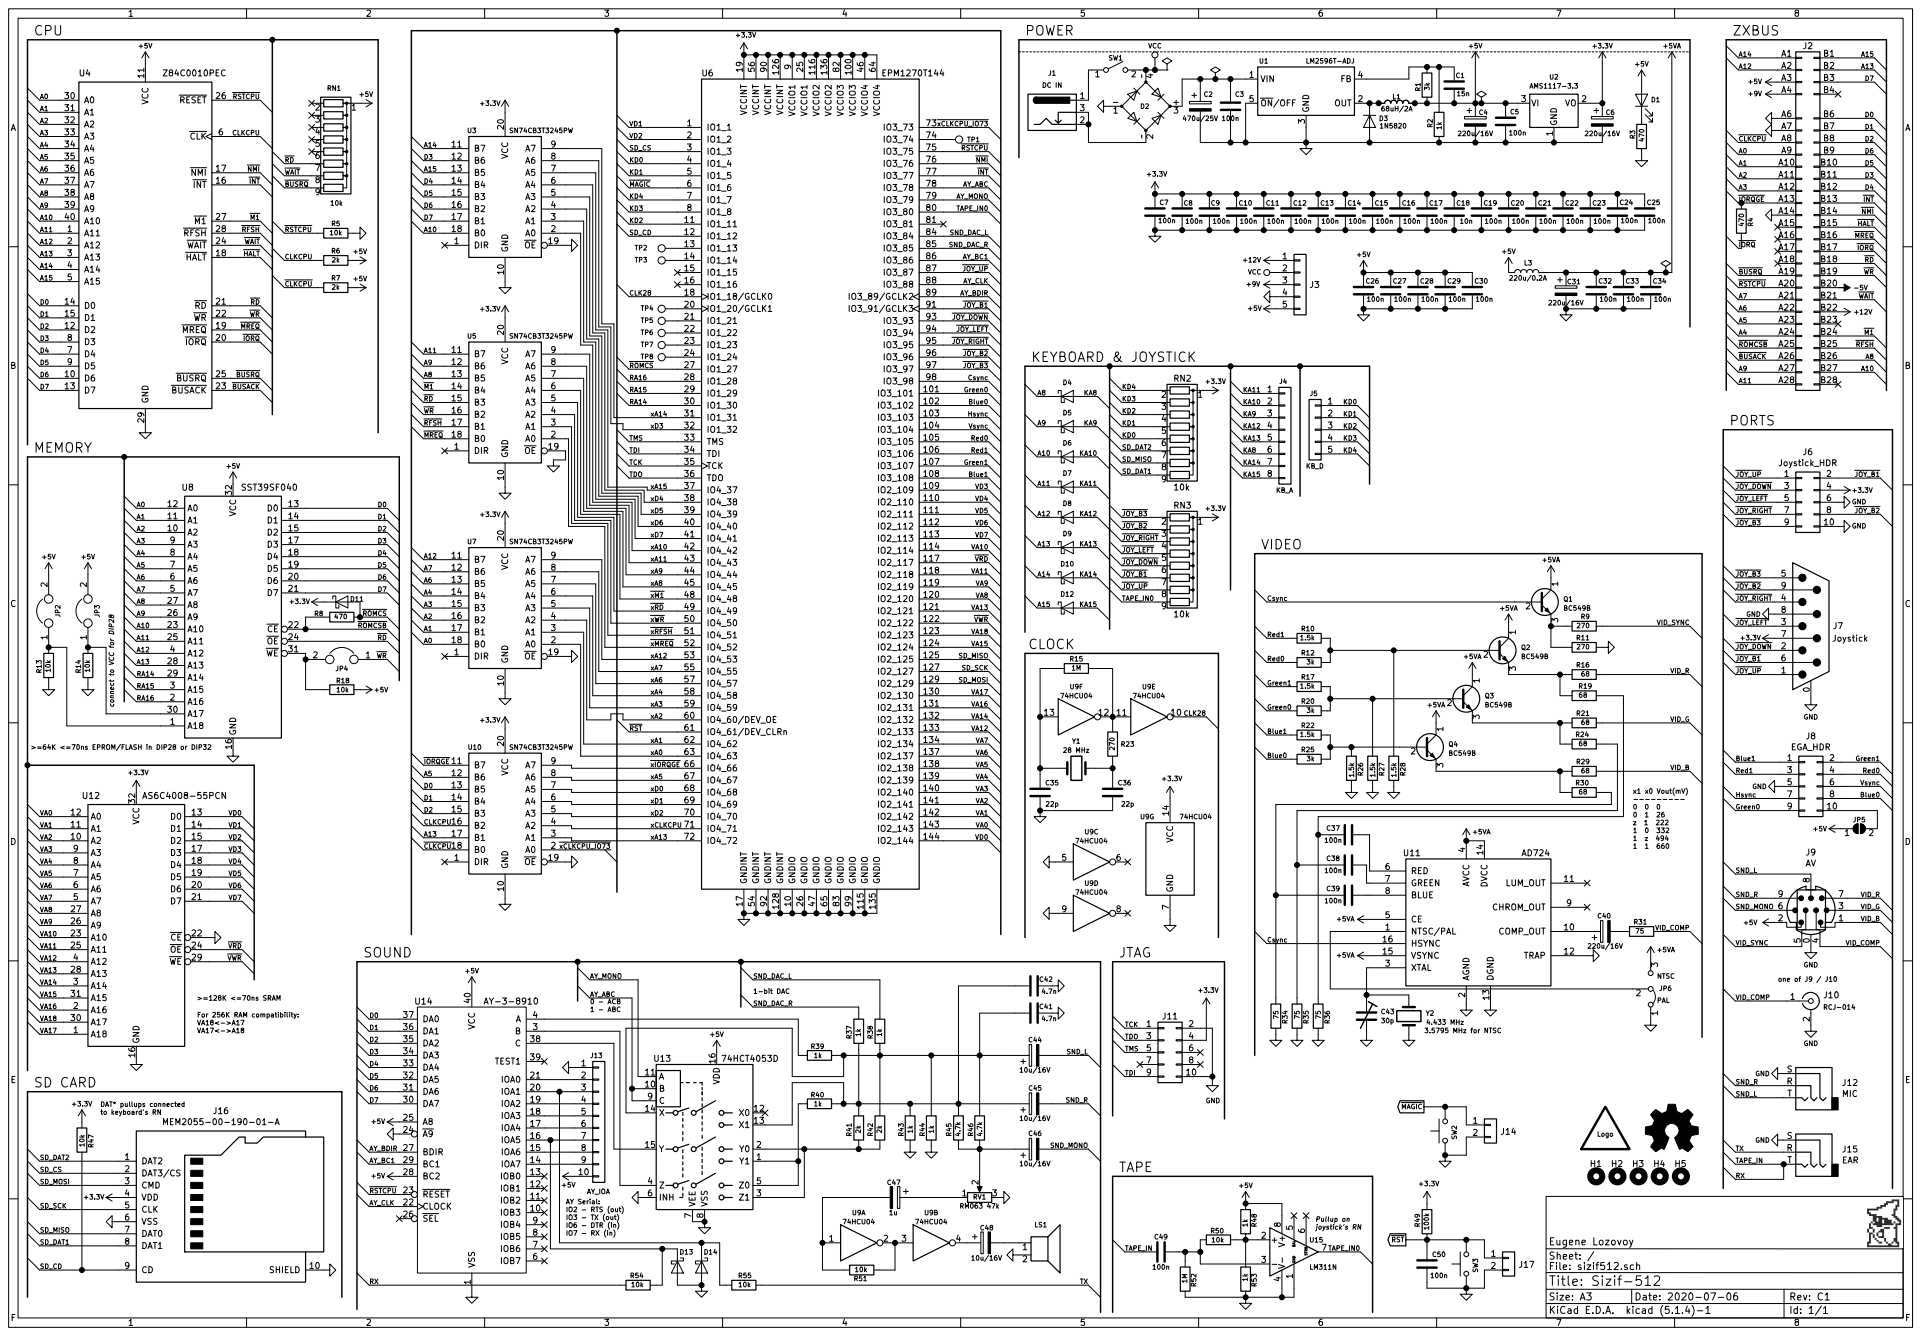
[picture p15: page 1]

connect to VCC for DIP28

>=64K <=70ns EPROM/FLASH in DIP28 or DIP32

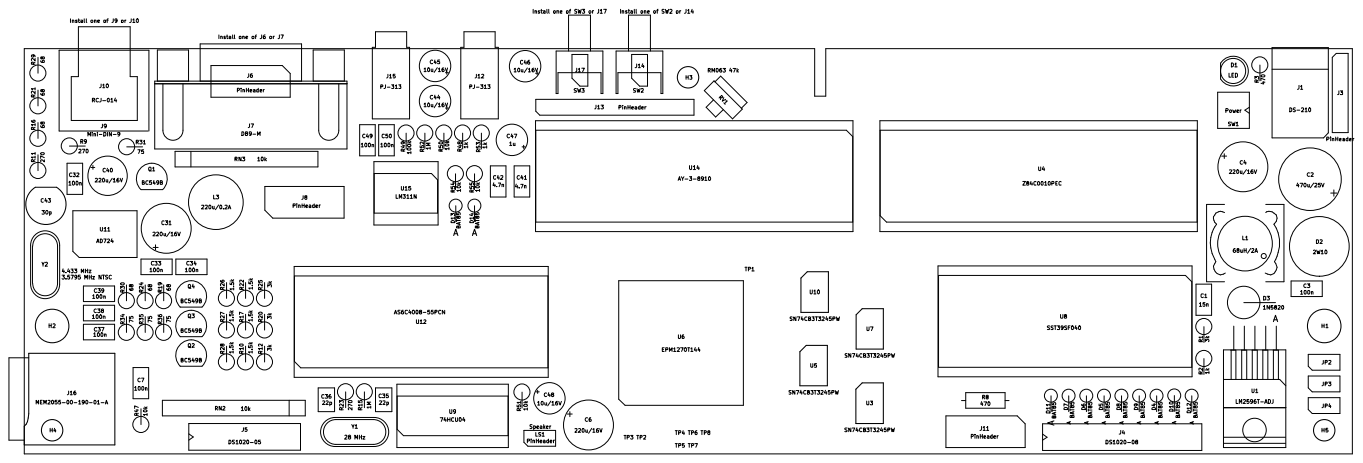
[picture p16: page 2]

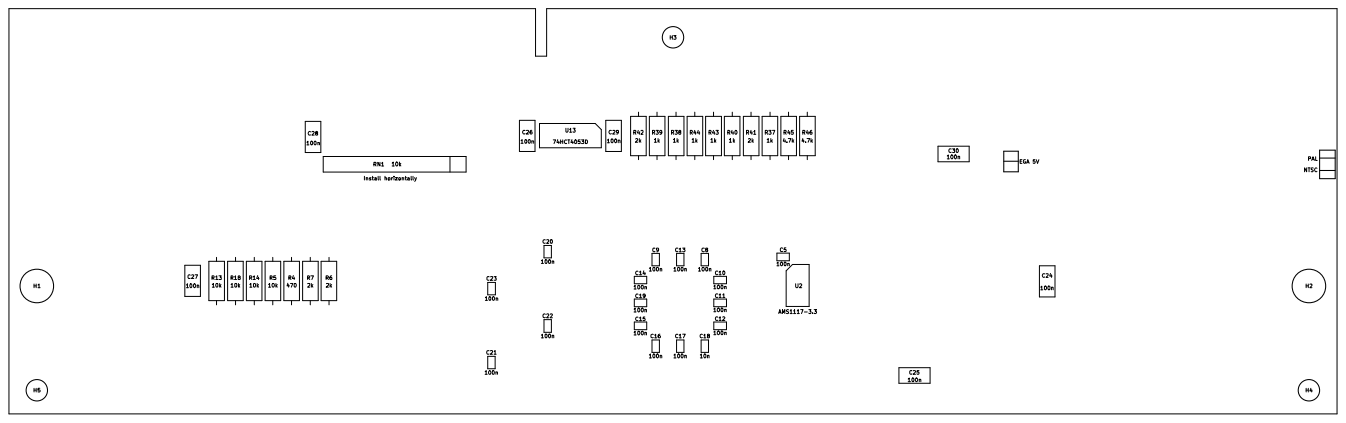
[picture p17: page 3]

Designator | Package | Designation | Quantity
C1 | C_Disc_D5.0mm_W2.5mm_P2.50mm | 15n | 1
C18 | C_0805_2012Metric_Pad1.15x1.40mm_HandSolder | 10n | 1
C2 | CP_Radial_D10.0mm_P5.00mm | 470u/25V | 1
C23,C22,C21,C20,C19,C5,C17,C16,C15,C14,C13,C 12,C11,C10,C9,C8 | C_0805_2012Metric_Pad1.15x1.40mm_HandSolder | 100n | 16
C36,C35 | C_Disc_D3.8mm_W2.6mm_P2.50mm | 22p | 2
C4,C31,C6 | CP_Radial_D8.0mm_P3.50mm | 220u/16V | 3
C40 | CP_Radial_D6.3mm_P2.50mm | 220u/16V | 1
C41,C42 | C_Disc_D5.0mm_W2.5mm_P2.50mm | 4.7n | 2
C43 | C_Trim_D6.3mm_P5.50mm | 30p | 1
C47 | CP_Radial_D5.0mm_P2.00mm | 1u | 1
C48,C46,C45,C44 | CP_Radial_D5.0mm_P2.00mm | 10u/16V | 4
C50,C49,C25,C7,C30,C26,C32,C3,C29,C34,C33,C2 8,C27,C24,C37,C38,C39 | C_Disc_D5.0mm_W2.5mm_P2.50mm | 100n | 17
D1 | LED_D4.0mm | LED | 1
D11,D14,D13,D12,D10,D9,D8,D7,D6,D5,D4 | D_DO-35_SOD27_P2.54mm_Vertical_AnodeUp | BAT85 | 11
D2 | Diode_Bridge_Round_D10.0mm | 2W10 | 1
D3 | D_DO-201AD_P5.08mm_Vertical_AnodeUp | 1N5820 | 1
J1 | BarrelJack_Horizontal | DS-210 | 1
J10 | CUI_RCJ-01X-WIDE | RCJ-014 | 1
J12,J15 | PJ-313 | PJ-313 | 2
J13 | PinHeader_1x10_P2.54mm_Vertical | PinHeader | 1
J14,J17 | PinHeader_2x01_P2.54mm_Vertical | PinHeader | 2
J16 | GCT-MEM2055-00-190-01-A | MEM2055-00-190-01-A | 1
J3 | PinHeader_1x05_P2.54mm_Vertical | PinHeader | 1
J4 | FFC_FPC_1x08 | DS1020-08 | 1
J5 | FFC_FPC_1x05 | DS1020-05 | 1
J6,J8,J11 | PinHeader_2x05_P2.54mm_Vertical | PinHeader | 3
J7 | DSUB-9_Male_Horizontal_P2.77x2.84mm_EdgePinOffset4.94mm_House d_MountingHolesOffset7.48mm | DB9-M | 1
J9 | minidin-9 | Mini-DIN-9 | 1
JP3,JP4,JP2 | PinHeader_1x02_P2.54mm_Vertical | Jumper | 3
L1 | L_Radial_D8.7mm_P5.00mm_Fastron_07HCP | 68uH/2A | 1
L3 | L_Radial_D8.7mm_P5.00mm_Fastron_07HCP | 220u/0.2A | 1
LS1 | PinHeader_1x02_P2.54mm_Vertical | PinHeader | 1
Q4,Q3,Q2,Q1 | TO-92_Inline | BC549B | 4
R1,R25,R20,R12 | R_Axial_DIN0207_L6.3mm_D2.5mm_P2.54mm_Vertical | 3k | 4
R11,R9,R23 | R_Axial_DIN0207_L6.3mm_D2.5mm_P2.54mm_Vertical | 270 | 3
R18,R5,R14,R13 | R_Axial_DIN0207_L6.3mm_D2.5mm_P7.62mm_Horizontal | 10k | 4
R2,R53,R48 | R_Axial_DIN0207_L6.3mm_D2.5mm_P2.54mm_Vertical | 1k | 3
R28,R27,R26,R22,R17,R10 | R_Axial_DIN0207_L6.3mm_D2.5mm_P2.54mm_Vertical | 1.5k | 6
R29,R16,R21,R30,R24,R19 | R_Axial_DIN0207_L6.3mm_D2.5mm_P2.54mm_Vertical | 68 | 6
R3 | R_Axial_DIN0207_L6.3mm_D2.5mm_P2.54mm_Vertical | 470 | 1
R34,R35,R36,R31 | R_Axial_DIN0207_L6.3mm_D2.5mm_P2.54mm_Vertical | 75 | 4
R44,R43,R40,R39,R38,R37 | R_Axial_DIN0207_L6.3mm_D2.5mm_P7.62mm_Horizontal | 1k | 6
R46,R45 | R_Axial_DIN0207_L6.3mm_D2.5mm_P7.62mm_Horizontal | 4.7k | 2
R49 | R_Axial_DIN0207_L6.3mm_D2.5mm_P2.54mm_Vertical | 100k | 1
R50,R54,R55,R47,R51 | R_Axial_DIN0207_L6.3mm_D2.5mm_P2.54mm_Vertical | 10k | 5
R52,R15 | R_Axial_DIN0207_L6.3mm_D2.5mm_P2.54mm_Vertical | 1M | 2
R7,R6,R42,R41 | R_Axial_DIN0207_L6.3mm_D2.5mm_P7.62mm_Horizontal | 2k | 4
R8,R4 | R_Axial_DIN0207_L6.3mm_D2.5mm_P7.62mm_Horizontal | 470 | 2
RN2,RN3,RN1 | R_Array_SIP9 | 10k | 3
RV1 | Potentiometer_Runtron_RM-063_Horizontal | RM063 47k | 1
SW1 | Molex_KK-254_AE-6410-02A_1x02_P2.54mm_Vertical | Jumper | 1
SW2,SW3 | SW_Tactile_SPST_Angled_PTS645Vx83-2LFS | Button THT | 2
TP2,TP3,TP1,TP8,TP7,TP6,TP5,TP4 | TestPoint_Pad_D1.0mm | TestPoint | 8
U1 | TO-220-263-5_Horizontal_TabDown | LM2596T-ADJ | 1
U11 | SOIC-16W_7.5x10.3mm_P1.27mm | AD724 | 1
U12 | DIP-32_W15.24mm_Socket | AS6C4008-55PCN | 1
U13 | SOIC-16_3.9x9.9mm_P1.27mm | 74HCT4053D | 1
U14 | DIP-40_W15.24mm_Socket | AY-3-8910 | 1
U15 | DIP-8_W7.62mm_Socket | LM311N | 1
U2 | SOT-223-3_TabPin2 | AMS1117-3.3 | 1
U3,U10,U5,U7 | TSSOP-20_4.4x6.5mm_P0.65mm | SN74CB3T3245PW | 4
U4 | DIP-40_W15.24mm_Socket | Z84C0010PEC | 1
U6 | LQFP-144_20x20mm_P0.5mm | EPM1270T144 | 1
U8 | DIP-32_W15.24mm_Socket | SST39SF040 | 1
U9 | DIP-14_W7.62mm_Socket | 74HCU04 | 1
Y1 | Crystal_HC49-U_Vertical | 28 MHz | 1
Y2 | Crystal_HC49-U_Vertical | 4.433 MHz | 1

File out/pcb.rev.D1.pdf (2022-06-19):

# IO1_18/GCLK0 18 VCCINT 19

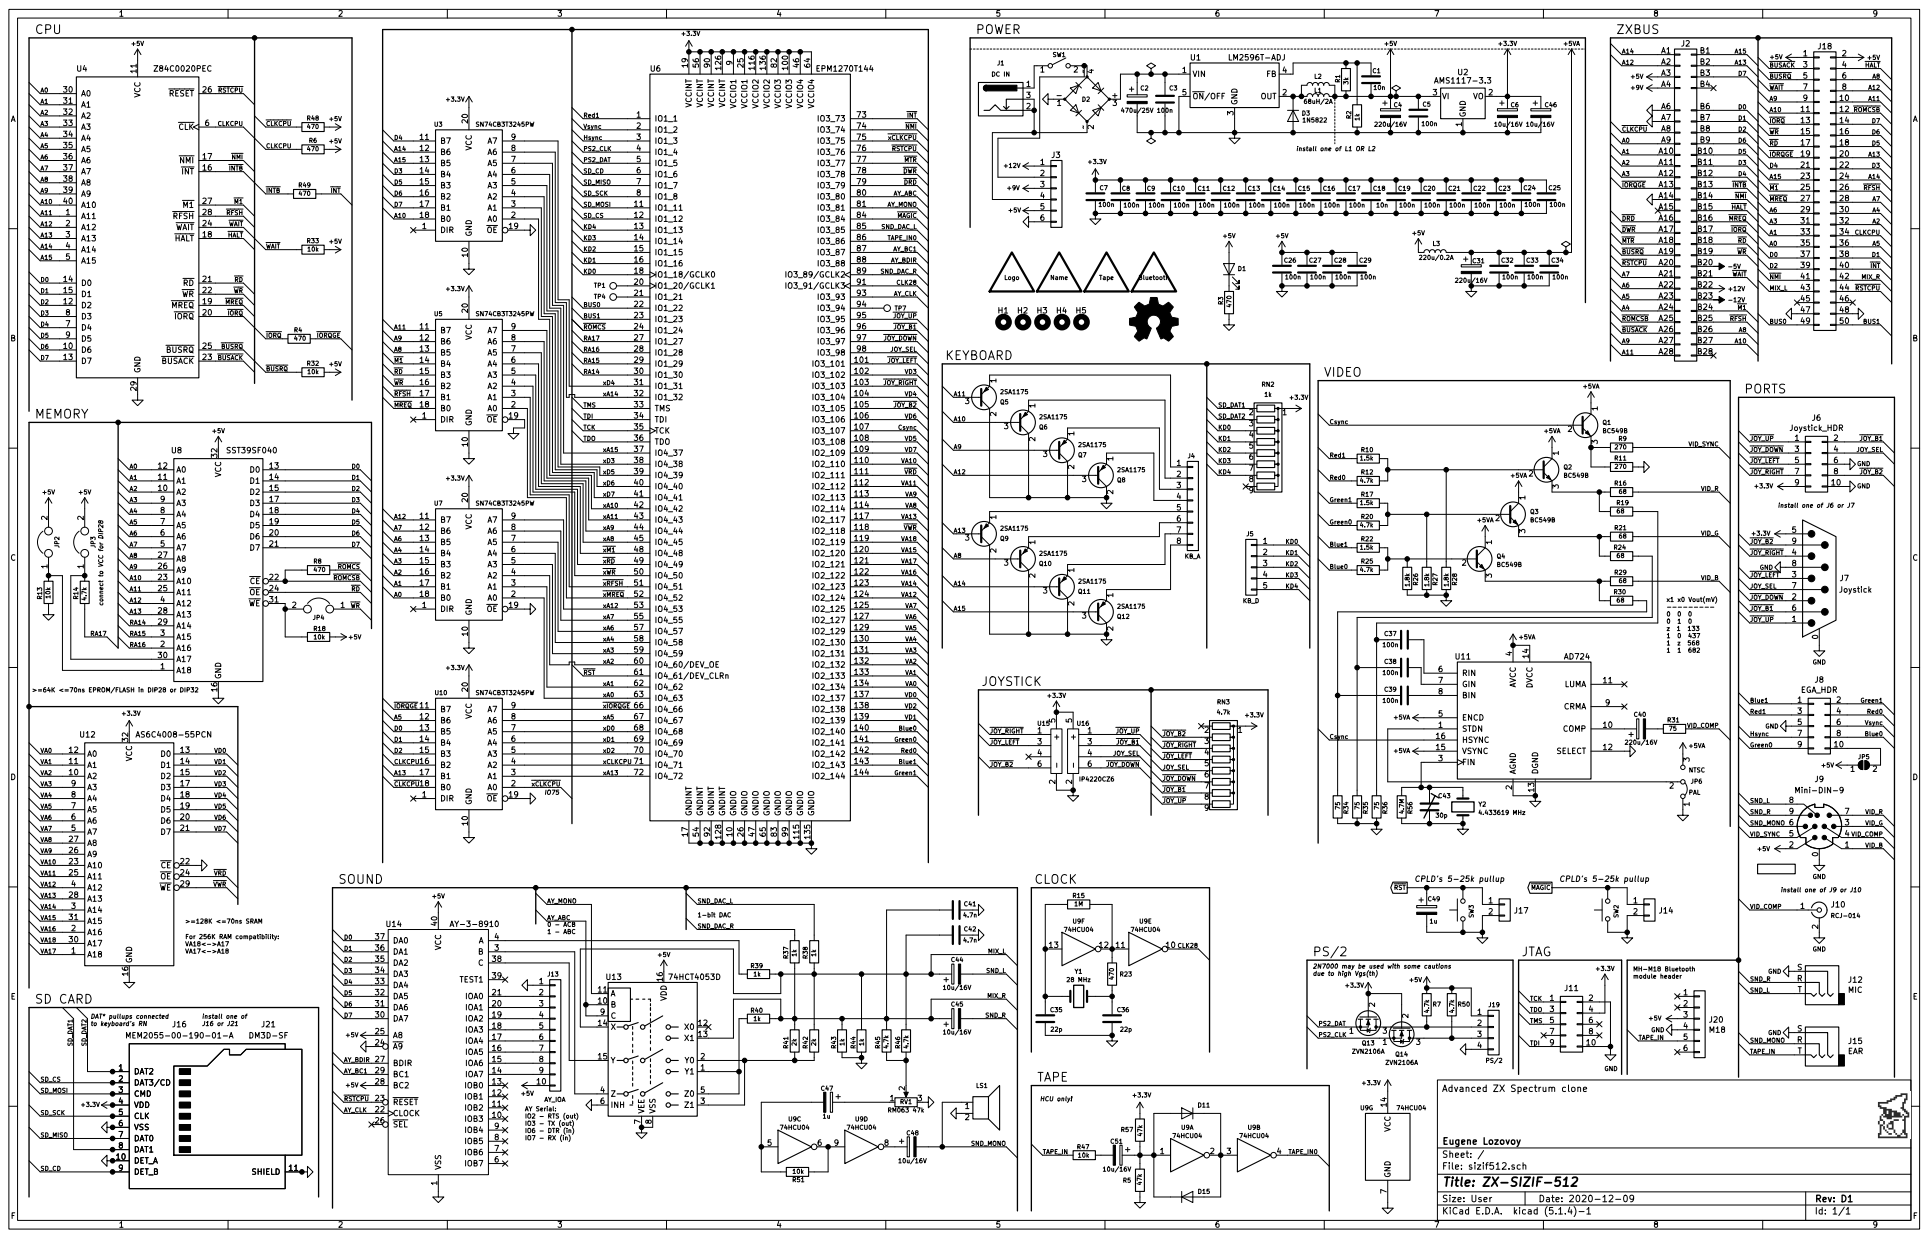
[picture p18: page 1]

install one of L1 OR L2

install one of J6 or J7

connect to VCC for DIP28

>=64K <=70ns EPROM/FLASH in DIP28 or DIP32

install one of J9 or J10

2N7000 may be used with some cautions
due to high Vgs(th)

Advanced ZX Spectrum clone

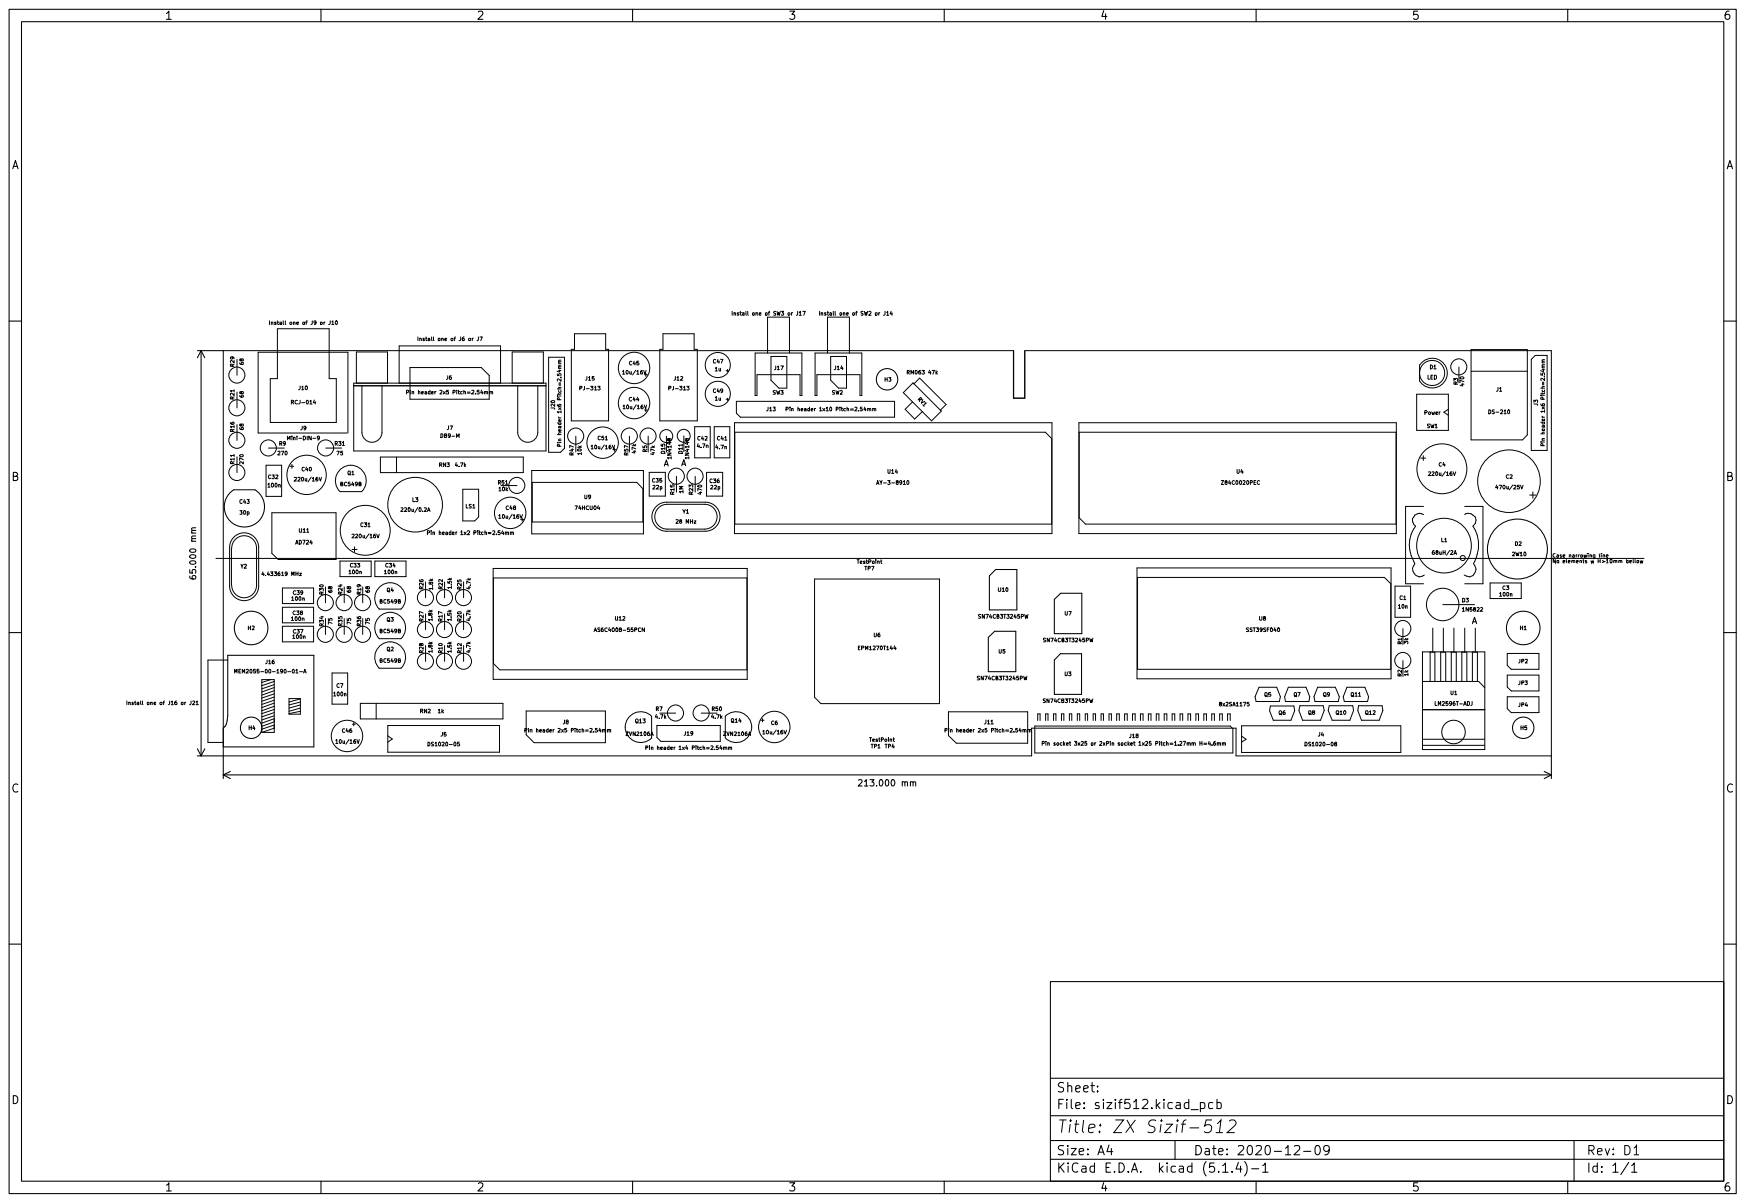
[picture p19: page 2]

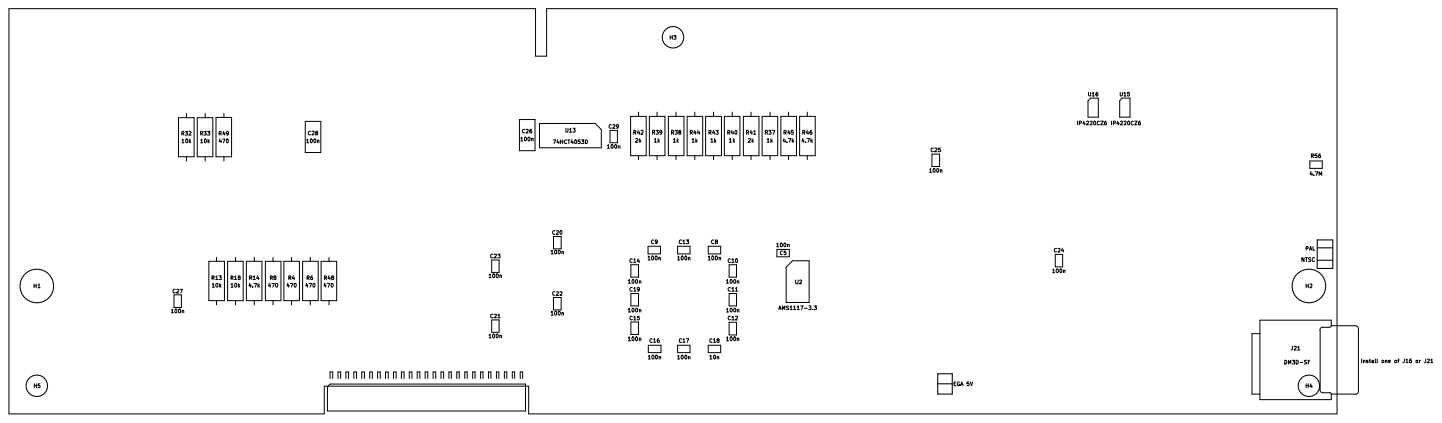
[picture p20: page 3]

Designator | Package | Designation | Quantity
C1 | C_Disc_D5.0mm_W2.5mm_P2.50mm | 10n | 1
C18 | C_0805_2012Metric_Pad1.15x1.40mm_HandSolder | 10n | 1
C2 | CP_Radial_D10.0mm_P5.00mm | 470u/25V | 1
C23,C27,C29,C25,C24,C22,C21,C20,C19,C17,C 16,C15,C14,C13,C12,C11,C10,C9,C8,C5 | C_0805_2012Metric_Pad1.15x1.40mm_HandSolder | 100n | 20
C26,C28,C7,C32,C3,C34,C33,C37,C38,C39 | C_Disc_D5.0mm_W2.5mm_P2.50mm | 100n | 10
C36,C35 | C_Disc_D3.8mm_W2.6mm_P2.50mm | 22p | 2
C4,C31 | CP_Radial_D8.0mm_P3.50mm | 220u/16V | 2
C40 | CP_Radial_D6.3mm_P2.50mm | 220u/16V | 1
C41,C42 | C_Disc_D5.0mm_W2.5mm_P2.50mm | 4.7n | 2
C43 | C_Trim_D6.3mm_P5.50mm | 30p | 1
C49,C47 | CP_Radial_D4.0mm_P2.00mm | 1u | 2
C6,C46,C44,C45,C51,C48 | CP_Radial_D5.0mm_P2.00mm | 10u/16V | 6
D1 | LED_D4.0mm | LED | 1
D15,D11 | D_DO-35_SOD27_P2.54mm_Vertical_AnodeUp | 1N4148 | 2
D2 | Diode_Bridge_Round_D10.0mm | 2W10 | 1
D3 | D_DO-201AD_P5.08mm_Vertical_AnodeUp | 1N5822 | 1
J1 | BarrelJack_Horizontal | DS-210 | 1
J10 | CUI_RCJ-01X-WIDE | RCJ-014 | 1
J12,J15 | PJ-313 | PJ-313 | 2
J13 | PinHeader_1x10_P2.54mm_Vertical | Pin header 1x10 Pitch=2.54mm | 1
J14,J17 | PinHeader_2x01_P2.54mm_Vertical | Pin header 1x2 Pitch=2.54mm | 2
J16 | GCT-MEM2055-00-190-01-A | MEM2055-00-190-01-A | 1
J18 | PinHeader_2x25_P1.27mm_Edge_SMD | Pin socket 3x25 or 2xPin socket 1x25 Pitch=1.27mm H=4.6mm | 1
J19 | PinHeader_1x04_P2.54mm_Vertical | Pin header 1x4 Pitch=2.54mm | 1
J20,J3 | PinHeader_1x06_P2.54mm_Vertical | Pin header 1x6 Pitch=2.54mm | 2
J21 | microSD_HC_Hirose_DM3D-SF | DM3D-SF | 1
J4 | FFC_FPC_1x08 | DS1020-08 | 1
J5 | FFC_FPC_1x05 | DS1020-05 | 1
J6,J8,J11 | PinHeader_2x05_P2.54mm_Vertical | Pin header 2x5 Pitch=2.54mm | 2
J7 | DSUB-9_Male_Horizontal_P2.77x2.84mm_EdgePinOffset4.94mm_Ho used_MountingHolesOffset7.48mm | DB9-M | 1
J9 | minidin-9 | Mini-DIN-9 | 1
JP3,JP4,JP2 | PinHeader_1x02_P2.54mm_Vertical | Jumper / Pin header 1x2 Pitch=2.54mm | 3
L1 | L_Radial_D8.7mm_P5.00mm_Fastron_07HCP | 68uH/2A | 1
L2 | L_12x12mm_H8mm | 68uH/2A | 1
L3 | L_Radial_D8.7mm_P5.00mm_Fastron_07HCP | 220u/0.2A | 1
LS1 | PinHeader_1x02_P2.54mm_Vertical | Pin header 1x2 Pitch=2.54mm | 1
Q10,Q8,Q12,Q11,Q9,Q7,Q6,Q5 | TO-92S | 2SA1175 | 8
Q13,Q14 | TO-92 | ZVN2106A | 2
Q4,Q3,Q2,Q1 | TO-92 | BC549B | 4
R1 | R_Axial_DIN0207_L6.3mm_D2.5mm_P2.54mm_Vertical | 3k | 1
R11,R9 | R_Axial_DIN0207_L6.3mm_D2.5mm_P2.54mm_Vertical | 270 | 2
R14,R46,R45 | R_Axial_DIN0207_L6.3mm_D2.5mm_P7.62mm_Horizontal | 4.7k | 3
R15 | R_Axial_DIN0207_L6.3mm_D2.5mm_P2.54mm_Vertical | 1M | 1
R2 | R_Axial_DIN0207_L6.3mm_D2.5mm_P2.54mm_Vertical | 1k | 1
R22,R17,R10 | R_Axial_DIN0207_L6.3mm_D2.5mm_P2.54mm_Vertical | 1.5k | 3
R23,R3 | R_Axial_DIN0207_L6.3mm_D2.5mm_P2.54mm_Vertical | 470 | 2
R28,R27,R26 | R_Axial_DIN0207_L6.3mm_D2.5mm_P2.54mm_Vertical | 1.8k | 3
R29,R16,R21,R30,R24,R19 | R_Axial_DIN0207_L6.3mm_D2.5mm_P2.54mm_Vertical | 68 | 6
R33,R32,R18,R13 | R_Axial_DIN0207_L6.3mm_D2.5mm_P7.62mm_Horizontal | 10k | 4
R34,R35,R36,R31 | R_Axial_DIN0207_L6.3mm_D2.5mm_P2.54mm_Vertical | 75 | 4
R42,R41 | R_Axial_DIN0207_L6.3mm_D2.5mm_P7.62mm_Horizontal | 2k | 2
R44,R43,R40,R39,R38,R37 | R_Axial_DIN0207_L6.3mm_D2.5mm_P7.62mm_Horizontal | 1k | 6
R47,R51 | R_Axial_DIN0207_L6.3mm_D2.5mm_P2.54mm_Vertical | 10k | 2
R5,R57 | R_Axial_DIN0207_L6.3mm_D2.5mm_P2.54mm_Vertical | 47k | 2
R50,R7,R25,R20,R12 | R_Axial_DIN0207_L6.3mm_D2.5mm_P2.54mm_Vertical | 4.7k | 5
R56 | R_0805_2012Metric_Pad1.15x1.40mm_HandSolder | 4.7M | 1
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

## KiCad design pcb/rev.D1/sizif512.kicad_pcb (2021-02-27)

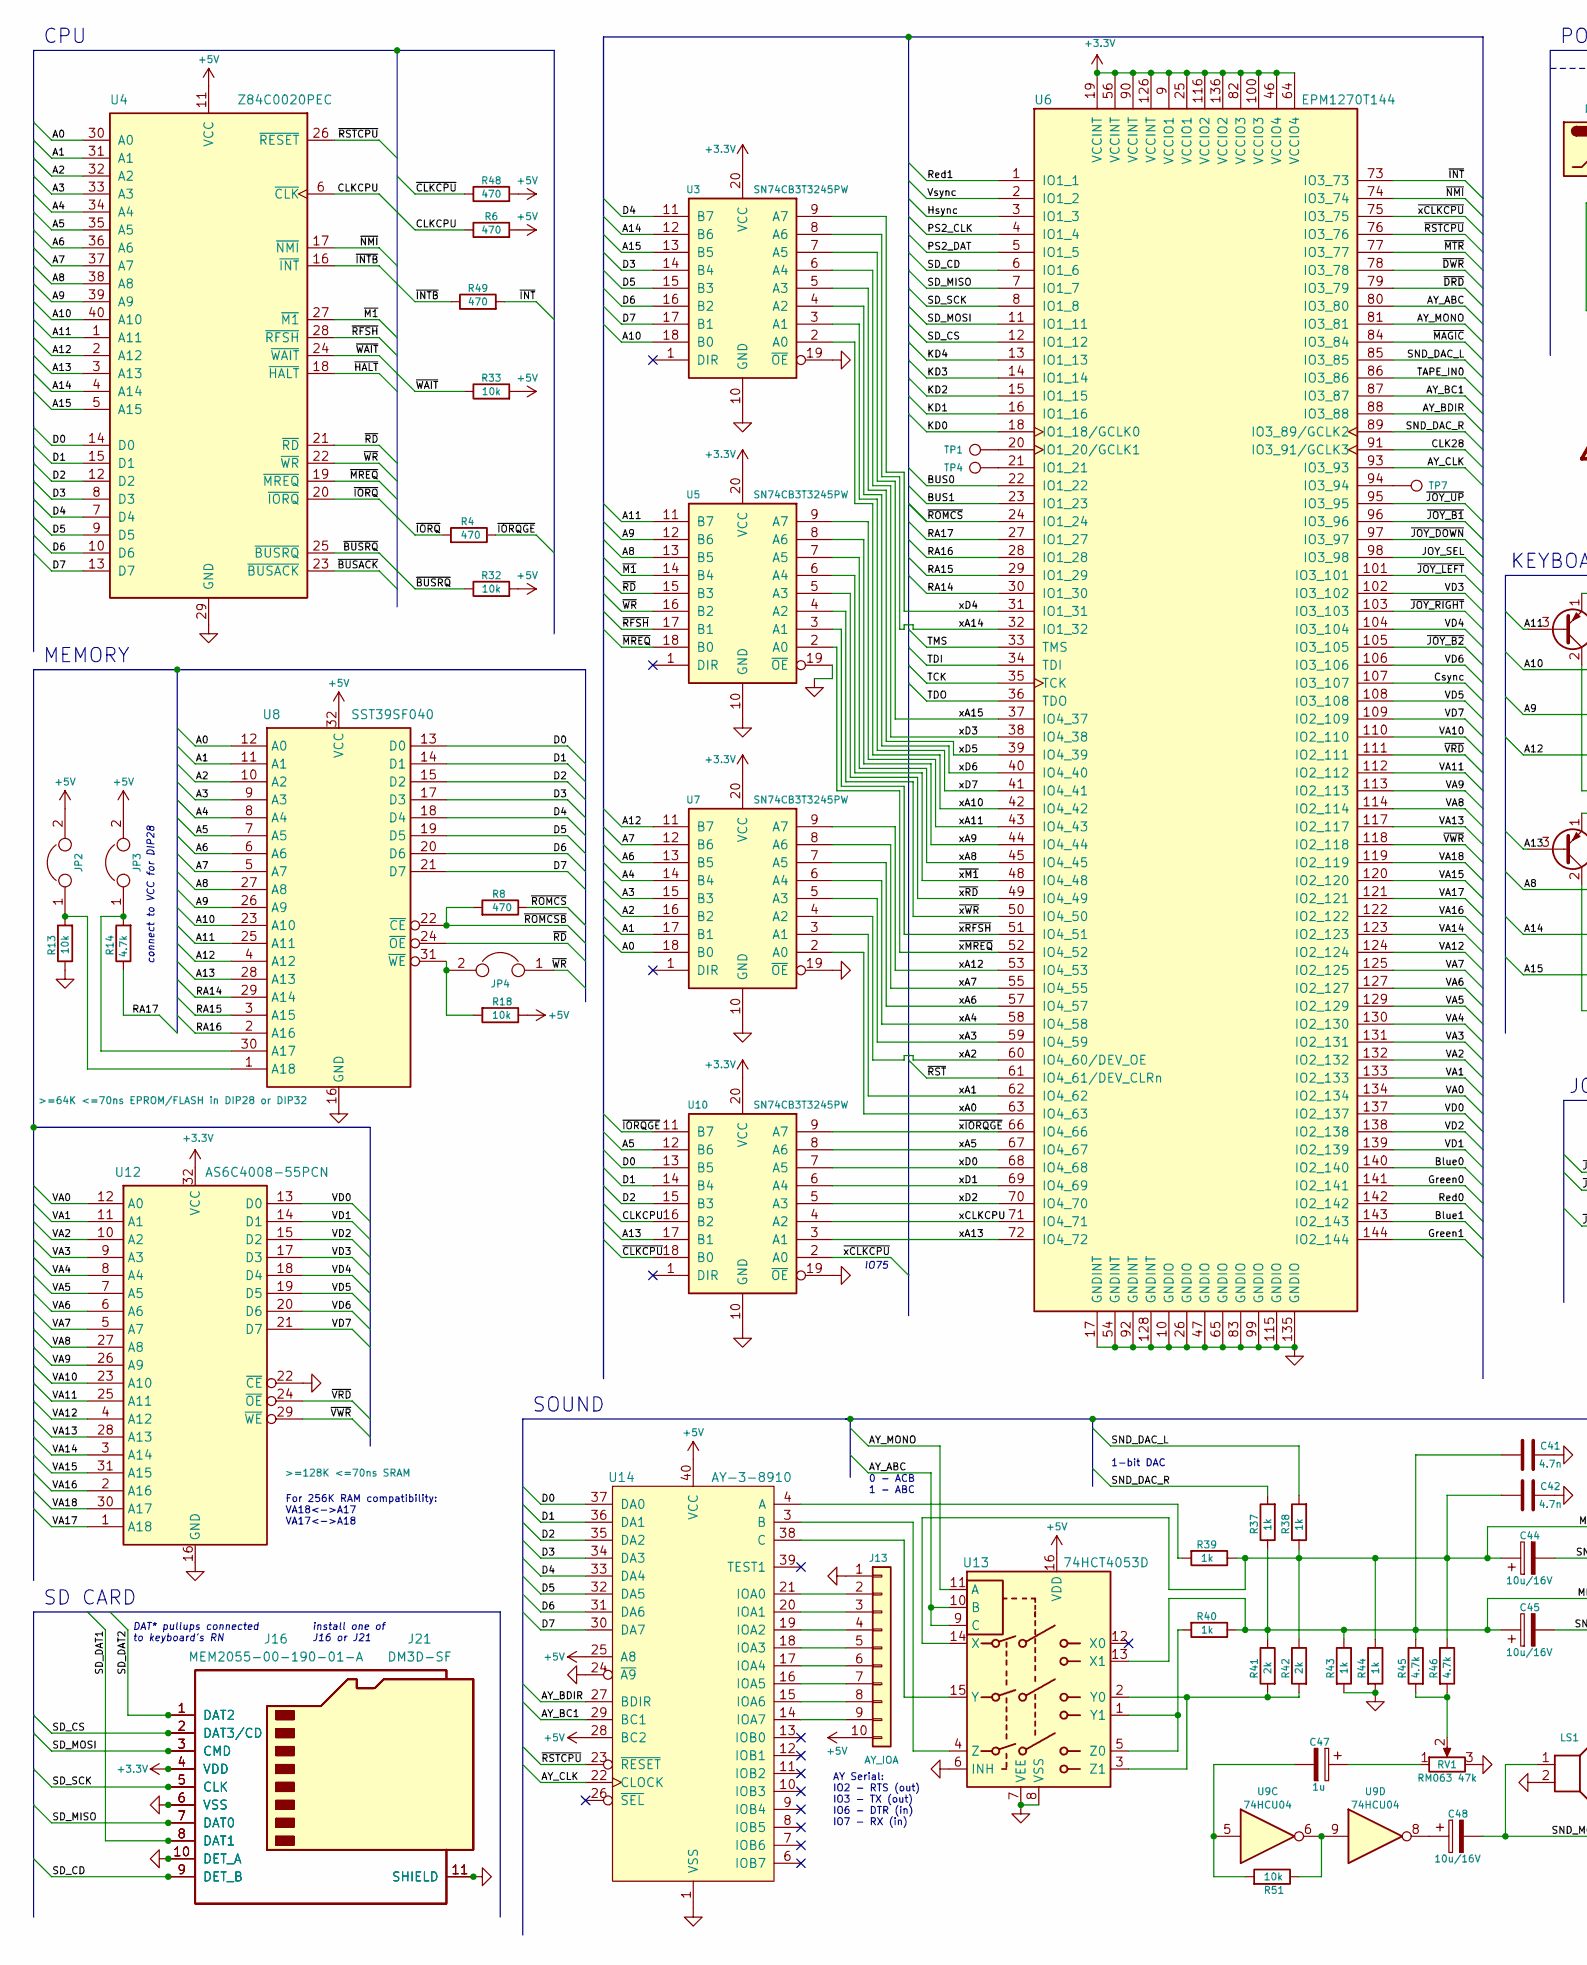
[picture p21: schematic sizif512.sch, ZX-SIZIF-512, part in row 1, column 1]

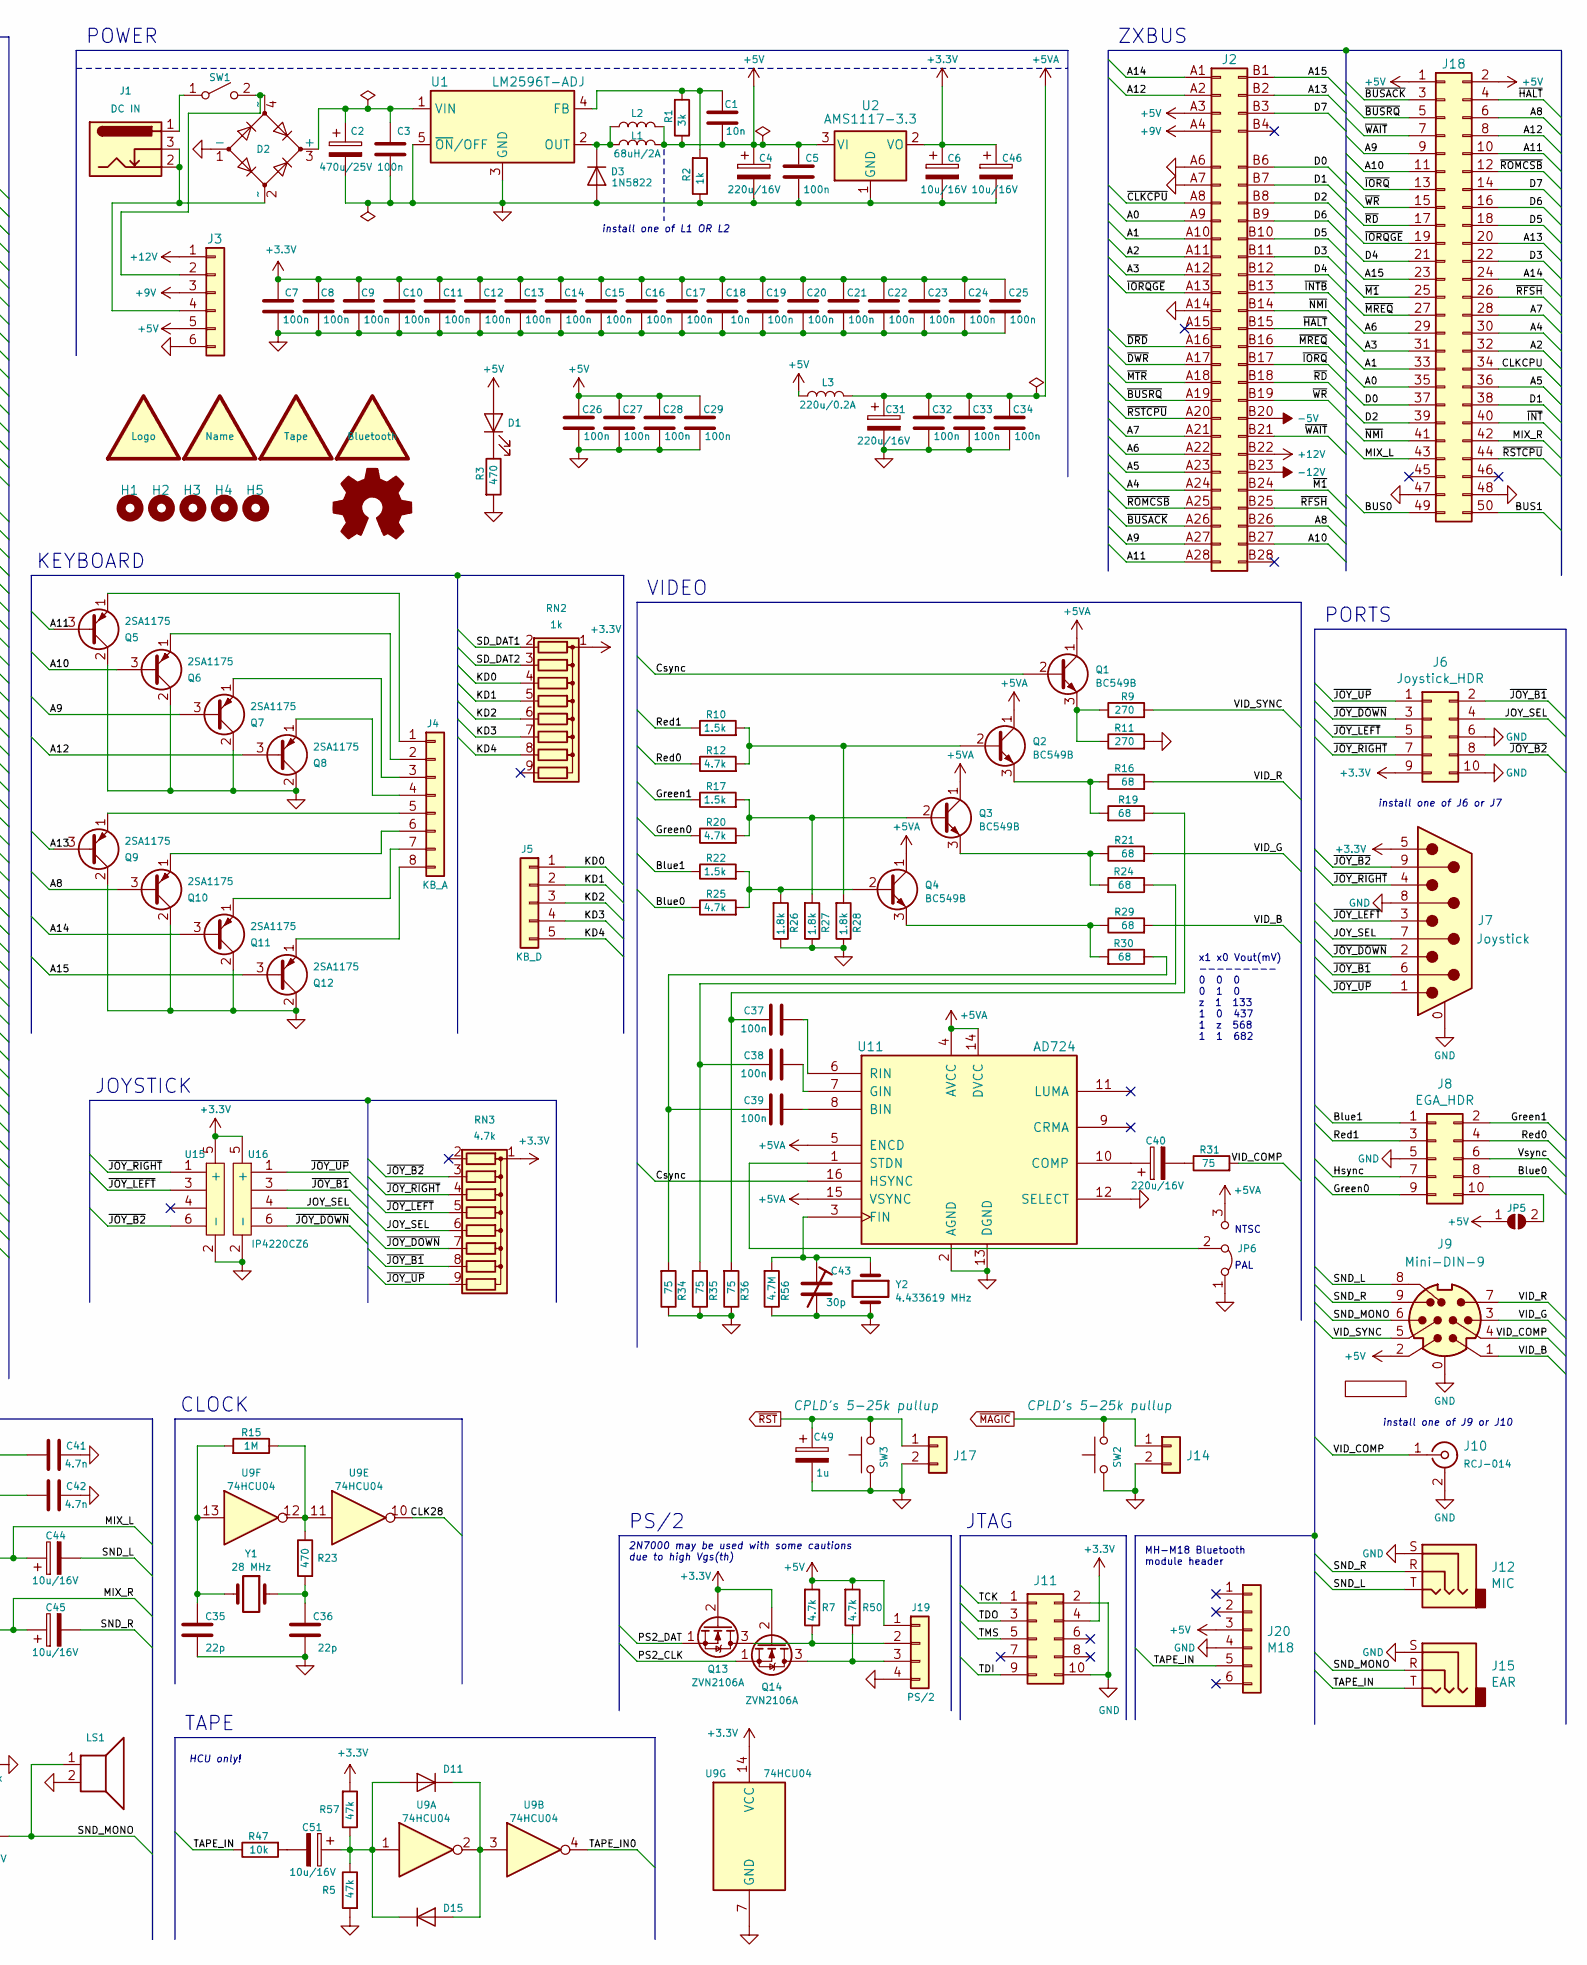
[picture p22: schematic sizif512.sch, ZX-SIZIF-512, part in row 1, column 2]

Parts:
C1: 10n; C_Disc_D5.0mm_W2.5mm_P2.50mm
C2: 470u/25V; CP_Radial_D10.0mm_P5.00mm
C3, C7, C26, C28, C32, C33, C34, C37, C38, C39: 100n; C_Disc_D5.0mm_W2.5mm_P2.50mm
C4, C31: 220u/16V; CP_Radial_D8.0mm_P3.50mm
C5, C8, C9, C10, C11, C12, C13, C14, C15, C16, C17, C19, C20, C21, C22, C23, C24, C25, C27, C29: 100n; C_0805_2012Metric_Pad1.15x1.40mm_HandSolder
C6, C44, C45, C46, C48, C51: 10u/16V; CP_Radial_D5.0mm_P2.00mm
C18: 10n; C_0805_2012Metric_Pad1.15x1.40mm_HandSolder
C35, C36: 22p; C_Disc_D3.8mm_W2.6mm_P2.50mm
C40: 220u/16V; CP_Radial_D6.3mm_P2.50mm
C41, C42: 4.7n; C_Disc_D5.0mm_W2.5mm_P2.50mm
C43: 30p; C_Trim_D6.3mm_P5.50mm
C47, C49: 1u; CP_Radial_D4.0mm_P2.00mm
D1: LED; LED_D4.0mm
D2: 2W10; Diode_Bridge_Round_D10.0mm
D3: 1N5822; D_DO-201AD_P5.08mm_Vertical_AnodeUp
D11, D15: 1N4148; D_DO-35_SOD27_P2.54mm_Vertical_AnodeUp
H1, H2: MountingHole; MountingHole_5mm_7mm_fence
H3, H4, H5: MountingHole; MountingHole_3mm
J1: DS-210; BarrelJack_Horizontal
J2: Conn_02x28_Row_Letter_First; ZX_EDGE
J3, J20: Pin header 1x6 Pitch=2.54mm; PinHeader_1x06_P2.54mm_Vertical
J4: DS1020-08; FFC_FPC_1x08
J5: DS1020-05; FFC_FPC_1x05
J6, J8, J11: Pin header 2x5 Pitch=2.54mm; PinHeader_2x05_P2.54mm_Vertical
J7: DB9-M; DSUB-9_Male_Horizontal_P2.77x2.84mm_EdgePinOffset4.94mm_Hou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
J9: Mini-DIN-9; minidin-9
J10: RCJ-014; CUI_RCJ-01X-WIDE
J12, J15: PJ-313
J13: Pin header 1x10 Pitch=2.54mm; PinHeader_1x10_P2.54mm_Vertical
J14, J17: Pin header 1x2 Pitch=2.54mm; PinHeader_2x01_P2.54mm_Vertical
J16: MEM2055-00-190-01-A; GCT-MEM2055-00-190-01-A
J18: Pin socket 3x25 or 2xPin socket 1x25 Pitch=1.27mm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; PinHeader_2x25_P1.27mm_Edge_SMD
J19: Pin header 1x4 Pitch=2.54mm; PinHeader_1x04_P2.54mm_Vertical
J21: DM3D-SF; microSD_HC_Hirose_DM3D-SF
JP2, JP3, JP4: Jumper / Pin header 1x2 Pitch=2.54mm; PinHeader_1x02_P2.54mm_Vertical
JP5: SolderJumper_2_Open; SolderJumper-2_P1.3mm_Open_RoundedPad1.0x1.5mm
JP6: Jumper_3_Bridged12; SolderJumper-3_P1.3mm_Bridged12_RoundedPad1.0x1.5mm_NumberL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
L1: 68uH/2A; L_Radial_D8.7mm_P5.00mm_Fastron_07HCP
L2: 68uH/2A; L_12x12mm_H8mm
L3: 220u/0.2A; L_Radial_D8.7mm_P5.00mm_Fastron_07HCP
LOGO1: graphic; black-mage2
LOGO2: Logo_Open_Hardware_Small; OSHW-Symbol_6.7x6mm_SilkScreen
LOGO3: graphic; jack35
LOGO4: graphic; bluetooth_small
LOGO5: graphic; sizif512
LS1: Pin header 1x2 Pitch=2.54mm; PinHeader_1x02_P2.54mm_Vertical
Q1, Q2, Q3, Q4: BC549B; TO-92
Q5, Q6, Q7, Q8, Q9, Q10, Q11, Q12: 2SA1175; TO-92S
Q13, Q14: ZVN2106A; TO-92
R1: 3k; R_Axial_DIN0207_L6.3mm_D2.5mm_P2.54mm_Vertical
R2: 1k; R_Axial_DIN0207_L6.3mm_D2.5mm_P2.54mm_Vertical
R3, R23: 470; R_Axial_DIN0207_L6.3mm_D2.5mm_P2.54mm_Vertical
R4, R6, R8, R48, R49: 470; R_Axial_DIN0207_L6.3mm_D2.5mm_P7.62mm_Horizontal
R5, R57: 47k; R_Axial_DIN0207_L6.3mm_D2.5mm_P2.54mm_Vertical
R7, R12, R20, R25, R50: 4.7k; R_Axial_DIN0207_L6.3mm_D2.5mm_P2.54mm_Vertical
R9, R11: 270; R_Axial_DIN0207_L6.3mm_D2.5mm_P2.54mm_Vertical
R10, R17, R22: 1.5k; R_Axial_DIN0207_L6.3mm_D2.5mm_P2.54mm_Vertical
R13, R18, R32, R33: 10k; R_Axial_DIN0207_L6.3mm_D2.5mm_P7.62mm_Horizontal
R14, R45, R46: 4.7k; R_Axial_DIN0207_L6.3mm_D2.5mm_P7.62mm_Horizontal
R15: 1M; R_Axial_DIN0207_L6.3mm_D2.5mm_P2.54mm_Vertical
R16, R19, R21, R24, R29, R30: 68; R_Axial_DIN0207_L6.3mm_D2.5mm_P2.54mm_Vertical
R26, R27, R28: 1.8k; R_Axial_DIN0207_L6.3mm_D2.5mm_P2.54mm_Vertical
R31, R34, R35, R36: 75; R_Axial_DIN0207_L6.3mm_D2.5mm_P2.54mm_Vertical
R37, R38, R39, R40, R43, R44: 1k; R_Axial_DIN0207_L6.3mm_D2.5mm_P7.62mm_Horizontal
R41, R42: 2k; R_Axial_DIN0207_L6.3mm_D2.5mm_P7.62mm_Horizontal
R47, R51: 10k; R_Axial_DIN0207_L6.3mm_D2.5mm_P2.54mm_Vertical
R56: 4.7M; R_0805_2012Metric_Pad1.15x1.40mm_HandSolder
RN2: 1k; R_Array_SIP9
RN3: 4.7k; R_Array_SIP9
RV1: RM063 47k; Potentiometer_Runtron_RM-063_Horizontal
SW1: Jumper / Pin header 1x2 Pitch=2.54mm; Molex_KK-254_AE-6410-02A_1x02_P2.54mm_Vertical
SW2, SW3: Button THT; SW_Tactile_SPST_Angled_PTS645Vx83-2LFS
TP1, TP4, TP7: TestPoint; TestPoint_Pad_D1.0mm
U1: LM2596T-ADJ; TO-220-263-5_Horizontal_TabDown
U2: AMS1117-3.3; SOT-223-3_TabPin2
U3, U5, U7, U10: SN74CB3T3245PW; TSSOP-20_4.4x6.5mm_P0.65mm
U4: Z84C0020PEC; DIP-40_W15.24mm_Socket
U6: EPM1270T144; LQFP-144_20x20mm_P0.5mm
U8: SST39SF040; DIP-32_W15.24mm_Socket
U9: 74HCU04; DIP-14_W7.62mm_Socket
U11: AD724; SOIC-16W_7.5x10.3mm_P1.27mm
U12: AS6C4008-55PCN; DIP-32_W15.24mm_Socket
U13: 74HCT4053D; SOIC-16_3.9x9.9mm_P1.27mm
U14: AY-3-8910; DIP-40_W15.24mm_Socket
U15, U16: IP4220CZ6; TSOP-6_1.65x3.05mm_P0.95mm
Y1: 28 MHz; Crystal_HC49-U_Vertical
Y2: 4.433619 MHz; Crystal_HC49-U_Vertical

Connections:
+3V3: C6.1, C7.2, C8.1, C9.1, C10.1, C11.1, C12.1, C13.1, C14.1, C15.1, C16.1, C17.1, C18.1, C19.1, C20.1, C21.1, C22.1, C23.1, C24.2, C25.2, C46.1, J6.9, J7.5, J11.4, J16.4 (VDD), J21.4 (VDD), Q13.2 (G), Q14.2 (G), R57.2, RN2.1 (common), RN3.1 (common), U2.2 (VO), U3.20 (VCC), U5.20 (VCC), U6.9 (VCCIO1), U6.19 (VCCINT), U6.25 (VCCIO1), U6.46 (VCCIO4), U6.56 (VCCINT), U6.64 (VCCIO4), U6.82 (VCCIO3), U6.90 (VCCINT), U6.100 (VCCIO3), U6.116 (VCCIO2), U6.126 (VCCINT), U6.136 (VCCIO2), U7.20 (VCC), U9.14 (VCC), U10.20 (VCC), U12.32 (VCC), U15.5 (+), U16.5 (+)
+5V: C1.1, C4.1, C5.2, C26.2, C27.2, C28.2, C29.2, D1.2 (A), J2.A3 (Pin_a3), J3.5, J9.2, J13.10, J18.1, J18.2, J19.1, J20.3, JP2.2, JP3.2, JP5.1 (A), L1.2, L2.2, L3.1, R1.1, R6.2, R7.2, R18.1, R32.2, R33.2, R48.2, R50.2, U2.3 (VI), U4.11 (VCC), U8.32 (VCC), U13.16 (VDD), U14.25 (A8), U14.28 (BC2), U14.40 (VCC)
+5VA: C31.1, C32.2, C33.2, C34.2, JP6.3 (B), L3.2, Q1.1 (C), Q2.1 (C), Q3.1 (C), Q4.1 (C), U11.4 (AVCC), U11.5 (ENCD), U11.14 (DVCC), U11.15 (VSYNC)
+9V: J2.A4 (Pin_a4), J3.3
+12V: J2.B22 (Pin_b22), J3.1
/A0: J2.A9 (Pin_a9), J18.35, U4.30 (A0), U7.18 (B0), U8.12 (A0)
/A1: J2.A10 (Pin_a10), J18.33, U4.31 (A1), U7.17 (B1), U8.11 (A1)
/A2: J2.A11 (Pin_a11), J18.32, U4.32 (A2), U7.16 (B2), U8.10 (A2)
/A3: J2.A12 (Pin_a12), J18.31, U4.33 (A3), U7.15 (B3), U8.9 (A3)
/A4: J2.A24 (Pin_a24), J18.30, U4.34 (A4), U7.14 (B4), U8.8 (A4)
/A5: J2.A23 (Pin_a23), J18.36, U4.35 (A5), U8.7 (A5), U10.12 (B6)
/A6: J2.A22 (Pin_a22), J18.29, U4.36 (A6), U7.13 (B5), U8.6 (A6)
/A7: J2.A21 (Pin_a21), J18.28, U4.37 (A7), U7.12 (B6), U8.5 (A7)
/A8: J2.B26 (Pin_b26), J18.6, Q10.3 (B), U4.38 (A8), U5.13 (B5), U8.27 (A8)
/A9: J2.A27 (Pin_a27), J18.9, Q7.3 (B), U4.39 (A9), U5.12 (B6), U8.26 (A9)
/A10: J2.B27 (Pin_b27), J18.11, Q6.3 (B), U3.18 (B0), U4.40 (A10), U8.23 (A10)
/A11: J2.A28 (Pin_a28), J18.10, Q5.3 (B), U4.1 (A11), U5.11 (B7), U8.25 (A11)
/A12: J2.A2 (Pin_a2), J18.8, Q8.3 (B), U4.2 (A12), U7.11 (B7), U8.4 (A12)
/A13: J2.B2 (Pin_b2), J18.20, Q9.3 (B), U4.3 (A13), U8.28 (A13), U10.17 (B1)
/A14: J2.A1 (Pin_a1), J18.24, Q11.3 (B), U3.12 (B6), U4.4 (A14)
/A15: J2.B1 (Pin_b1), J18.23, Q12.3 (B), U3.13 (B5), U4.5 (A15)
/AY_ABC: U6.80 (IO3_80), U13.9 (C), U13.10 (B)
/AY_BC1: U6.87 (IO3_87), U14.29 (BC1)
/AY_BDIR: U6.88 (IO3_88), U14.27 (BDIR)
/AY_CLK: U6.93 (IO3_93), U14.22 (CLOCK)
/AY_MONO: U6.81 (IO3_81), U13.11 (A)
/BUS0: J18.49, U6.22 (IO1_22)
/BUS1: J18.50, U6.23 (IO1_23)
/Blue0: J8.8, R25.1, U6.140 (IO2_140)
/Blue1: J8.1, R22.1, U6.143 (IO2_143)
/CLK28: U6.91 (IO3_91/GCLK3), U9.10
/CLKCPU: J18.34, R6.1, U4.6 (~CLK~), U10.16 (B2)
/Csync: Q1.2 (B), U6.107 (IO3_107), U11.16 (HSYNC)
/D0: J2.B6 (Pin_b6), J18.37, U4.14 (D0), U8.13 (D0), U10.13 (B5), U14.37 (DA0)
/D1: J2.B7 (Pin_b7), J18.38, U4.15 (D1), U8.14 (D1), U10.14 (B4), U14.36 (DA1)
/D2: J2.B8 (Pin_b8), J18.39, U4.12 (D2), U8.15 (D2), U10.15 (B3), U14.35 (DA2)
/D3: J2.B11 (Pin_b11), J18.22, U3.14 (B4), U4.8 (D3), U8.17 (D3), U14.34 (DA3)
/D4: J2.B12 (Pin_b12), J18.21, U3.11 (B7), U4.7 (D4), U8.18 (D4), U14.33 (DA4)
/D5: J2.B10 (Pin_b10), J18.18, U3.15 (B3), U4.9 (D5), U8.19 (D5), U14.32 (DA5)
/D6: J2.B9 (Pin_b9), J18.16, U3.16 (B2), U4.10 (D6), U8.20 (D6), U14.31 (DA6)
/D7: J2.B3 (Pin_b3), J18.14, U3.17 (B1), U4.13 (D7), U8.21 (D7), U14.30 (DA7)
/Green0: J8.9, R20.1, U6.141 (IO2_141)
/Green1: J8.2, R17.1, U6.144 (IO2_144)
/Hsync: J8.7, U6.3 (IO1_3)
/JOY_SEL: J6.4, J7.7, RN3.6 (R5), U6.98 (IO3_98), U16.4
/KD0: J5.1, RN2.4 (R3), U6.18 (IO1_18/GCLK0)
/KD1: J5.2, RN2.5 (R4), U6.16 (IO1_16)
/KD2: J5.3, RN2.6 (R5), U6.15 (IO1_15)
/KD3: J5.4, RN2.7 (R6), U6.14 (IO1_14)
/KD4: J5.5, RN2.8 (R7), U6.13 (IO1_13)
/MIX_L: C42.2, C44.1, J18.43, R38.1, R39.1, R42.1, R44.1, R46.1, U13.14 (X)
/MIX_R: C41.2, C45.1, J18.42, R37.1, R40.1, R41.1, R43.1, R45.1, U13.13 (X1)
/PS2_CLK: Q14.1 (S), U6.4 (IO1_4)
/PS2_DAT: Q13.1 (S), U6.5 (IO1_5)
/RA14: U6.30 (IO1_30), U8.29 (A14)
/RA15: U6.29 (IO1_29), U8.3 (A15)
/RA16: U6.28 (IO1_28), U8.2 (A16)
/RA17: R14.1, U6.27 (IO1_27)
/Red0: J8.4, R12.1, U6.142 (IO2_142)
/Red1: J8.3, R10.1, U6.1 (IO1_1)
/SD_CD: J16.9 (DET_B), J21.9 (DET_B), U6.6 (IO1_6)
/SD_CS: J16.2 (DAT3/CD), J21.2 (DAT3/CD), U6.12 (IO1_12)
/SD_DAT1: J16.8 (DAT1), J21.8 (DAT1), RN2.2 (R1)
/SD_DAT2: J16.1 (DAT2), J21.1 (DAT2), RN2.3 (R2)
/SD_MISO: J16.7 (DAT0), J21.7 (DAT0), U6.7 (IO1_7)
/SD_MOSI: J16.3 (CMD), J21.3 (CMD), U6.11 (IO1_11)
/SD_SCK: J16.5 (CLK), J21.5 (CLK), U6.8 (IO1_8)
/SND_DAC_L: R38.2, U6.85 (IO3_85)
/SND_DAC_R: R37.2, U6.89 (IO3_89/GCLK2)
/SND_L: C44.2, J9.8, J12.T
/SND_MONO: C48.2, J9.6, J15.R, LS1.1
/SND_R: C45.2, J9.9, J12.R
/TAPE_IN: J15.T, J20.5, R47.1
/TAPE_IN0: U6.86 (IO3_86), U9.4
/TCK: J11.1, U6.35 (TCK)
/TDI: J11.9, U6.34 (TDI)
/TDO: J11.3, U6.36 (TDO)
/TMS: J11.5, U6.33 (TMS)
/VA0: U6.134 (IO2_134), U12.12 (A0)
/VA1: U6.133 (IO2_133), U12.11 (A1)
/VA2: U6.132 (IO2_132), U12.10 (A2)
/VA3: U6.131 (IO2_131), U12.9 (A3)
/VA4: U6.130 (IO2_130), U12.8 (A4)
/VA5: U6.129 (IO2_129), U12.7 (A5)
/VA6: U6.127 (IO2_127), U12.6 (A6)
/VA7: U6.125 (IO2_125), U12.5 (A7)
/VA8: U6.114 (IO2_114), U12.27 (A8)
/VA9: U6.113 (IO2_113), U12.26 (A9)
/VA10: U6.110 (IO2_110), U12.23 (A10)
/VA11: U6.112 (IO2_112), U12.25 (A11)
/VA12: U6.124 (IO2_124), U12.4 (A12)
/VA13: U6.117 (IO2_117), U12.28 (A13)
/VA14: U6.123 (IO2_123), U12.3 (A14)
/VA15: U6.120 (IO2_120), U12.31 (A15)
/VA16: U6.122 (IO2_122), U12.2 (A16)
/VA17: U6.121 (IO2_121), U12.1 (A18)
/VA18: U6.119 (IO2_119), U12.30 (A17)
/VD0: U6.137 (IO2_137), U12.13 (D0)
/VD1: U6.139 (IO2_139), U12.14 (D1)
/VD2: U6.138 (IO2_138), U12.15 (D2)
/VD3: U6.102 (IO3_102), U12.17 (D3)
/VD4: U6.104 (IO3_104), U12.18 (D4)
/VD5: U6.108 (IO3_108), U12.19 (D5)
/VD6: U6.106 (IO3_106), U12.20 (D6)
/VD7: U6.109 (IO2_109), U12.21 (D7)
/VID_B: J9.1, R29.2
/VID_COMP: J9.4, J10.1 (In), R31.2
/VID_G: J9.3, R21.2
/VID_R: J9.7, R16.2
/VID_SYNC: J9.5, R9.2
/Vsync: J8.6, U6.2 (IO1_2)
/xA0: U6.63 (IO4_63), U7.2 (A0)
/xA1: U6.62 (IO4_62), U7.3 (A1)
/xA2: U6.60 (IO4_60/DEV_OE), U7.4 (A2)
/xA3: U6.59 (IO4_59), U7.5 (A3)
/xA4: U6.58 (IO4_58), U7.6 (A4)
/xA5: U6.67 (IO4_67), U10.8 (A6)
/xA6: U6.57 (IO4_57), U7.7 (A5)
/xA7: U6.55 (IO4_55), U7.8 (A6)
/xA8: U5.7 (A5), U6.45 (IO4_45)
/xA9: U5.8 (A6), U6.44 (IO4_44)
/xA10: U3.2 (A0), U6.42 (IO4_42)
/xA11: U5.9 (A7), U6.43 (IO4_43)
/xA12: U6.53 (IO4_53), U7.9 (A7)
/xA13: U6.72 (IO4_72), U10.3 (A1)
/xA14: U3.8 (A6), U6.32 (IO1_32)
/xA15: U3.7 (A5), U6.37 (IO4_37)
/xCLKCPU: U6.71 (IO4_71), U10.4 (A2)
/xD0: U6.68 (IO4_68), U10.7 (A5)
/xD1: U6.69 (IO4_69), U10.6 (A4)
/xD2: U6.70 (IO4_70), U10.5 (A3)
/xD3: U3.6 (A4), U6.38 (IO4_38)
/xD4: U3.9 (A7), U6.31 (IO1_31)
/xD5: U3.5 (A3), U6.39 (IO4_39)
/xD6: U3.4 (A2), U6.40 (IO4_40)
/xD7: U3.3 (A1), U6.41 (IO4_41)
/~BUSACK: J2.A26 (Pin_a26), J18.3, U4.23 (~BUSACK~)
/~BUSRQ: J2.A19 (Pin_a19), J18.5, R32.1, U4.25 (~BUSRQ~)
/~CLKCPU: J2.A8 (Pin_a8), R48.1, U10.18 (B0)
/~DRD: J2.A16 (Pin_a16), U6.79 (IO3_79)
/~DWR: J2.A17 (Pin_a17), U6.78 (IO3_78)
/~HALT: J2.B15 (Pin_b15), J18.4, U4.18 (~HALT~)
/~INT: J18.40, R49.2, U6.73 (IO3_73)
/~INTB: J2.B13 (Pin_b13), R49.1, U4.16 (~INT~)
/~IORQ: J2.B17 (Pin_b17), J18.13, R4.2, U4.20 (~IORQ~)
/~IORQGE: J2.A13 (Pin_a13), J18.19, R4.1, U10.11 (B7)
/~JOY_B1: J6.2, J7.6, RN3.8 (R7), U6.96 (IO3_96), U16.3
/~JOY_B2: J6.8, J7.9, RN3.3 (R2), U6.105 (IO3_105), U15.6
/~JOY_DOWN: J6.3, J7.2, RN3.7 (R6), U6.97 (IO3_97), U16.6
/~JOY_LEFT: J6.5, J7.3, RN3.5 (R4), U6.101 (IO3_101), U15.3
/~JOY_RIGHT: J6.7, J7.4, RN3.4 (R3), U6.103 (IO3_103), U15.1
/~JOY_UP: J6.1, J7.1, RN3.9 (R8), U6.95 (IO3_95), U16.1
/~M1: J2.B24 (Pin_b24), J18.25, U4.27 (~M1~), U5.14 (B4)
/~MREQ: J2.B16 (Pin_b16), J18.27, U4.19 (~MREQ~), U5.18 (B0)
/~MTR: J2.A18 (Pin_a18), U6.77 (IO3_77)
/~NMI: J2.B14 (Pin_b14), J18.41, U4.17 (~NMI~), U6.74 (IO3_74)
/~RD: J2.B18 (Pin_b18), J18.17, U4.21 (~RD~), U5.15 (B3), U8.24 (~OE)
/~RFSH: J2.B25 (Pin_b25), J18.26, U4.28 (~RFSH~), U5.17 (B1)
/~ROMCS: R8.1, U6.24 (IO1_24)
/~ROMCSB: J2.A25 (Pin_a25), J18.12, R8.2, U8.22 (~CE)
/~RSTCPU: J2.A20 (Pin_a20), J18.44, U4.26 (~RESET~), U6.76 (IO3_76), U14.23 (~RESET~)
/~VRD: U6.111 (IO2_111), U12.24 (~OE)
/~VWR: U6.118 (IO2_118), U12.29 (~WE)
/~WAIT: J2.B21 (Pin_b21), J18.7, R33.1, U4.24 (~WAIT~)
/~WR: J2.B19 (Pin_b19), J18.15, JP4.1, U4.22 (~WR~), U5.16 (B2)
/~xCLKCPU: U6.75 (IO3_75), U10.2 (A0)
/~xIORQGE: U6.66 (IO4_66), U10.9 (A7)
/~xM1: U5.6 (A4), U6.48 (IO4_48)
/~xMREQ: U5.2 (A0), U6.52 (IO4_52)
/~xRD: U5.5 (A3), U6.49 (IO4_49)
/~xRFSH: U5.3 (A1), U6.51 (IO4_51)
/~xWR: U5.4 (A2), U6.50 (IO4_50)
GND: C2.2, C3.2, C4.2, C5.1, C6.2, C7.1, C8.2, C9.2, C10.2, C11.2, C12.2, C13.2, C14.2, C15.2, C16.2, C17.2, C18.2, C19.2, C20.2, C21.2, C22.2, C23.2, C24.1, C25.1, C26.1, C27.1, C28.1, C29.1, C31.2, C32.1, C33.1, C34.1, C35.1, C36.1, C41.1, C42.1, C43.2, C46.2, C49.2, D2.1 (-), D3.2 (A), J2.A6 (Pin_a6), J2.A7 (Pin_a7), J2.A14 (Pin_a14), J3.6, J6.6, J6.10, J7.0 (PAD), J7.8, J8.5, J9.0, J10.2 (Ext), J11.2, J11.10, J12.S, J13.1, J14.2, J15.S, J16.6 (VSS), J16.10 (DET_A), J16.11 (SHIELD), J17.2, J18.47, J18.48, J19.4, J20.4, J21.6 (VSS), J21.10 (DET_A), J21.11 (SHIELD), JP6.1 (A), LS1.2, Q5.2 (C), Q6.2 (C), Q7.2 (C), Q8.2 (C), Q9.2 (C), Q10.2 (C), Q11.2 (C), Q12.2 (C), R2.1, R3.2, R5.2, R11.2, R13.1, R26.1, R27.1, R28.1, R34.1, R35.1, R36.1, R43.2, R44.2, R56.1, RV1.3, SW2.1, SW3.1, U1.3 (GND), U1.5 (~ON~/OFF), U2.1 (GND), U3.10 (GND), U3.19 (~OE), U4.29 (GND), U5.10 (GND), U5.19 (~OE), U6.10 (GNDIO), U6.17 (GNDINT), U6.26 (GNDIO), U6.47 (GNDIO), U6.54 (GNDINT), U6.65 (GNDIO), U6.83 (GNDIO), U6.92 (GNDINT), U6.99 (GNDIO), U6.115 (GNDIO), U6.128 (GNDINT), U6.135 (GNDIO), U7.10 (GND), U7.19 (~OE), U8.16 (GND), U9.7 (GND), U10.10 (GND), U10.19 (~OE), U11.2 (AGND), U11.12 (SELECT), U11.13 (DGND), U12.16 (GND), U12.22 (~CE), U13.6 (INH), U13.7 (VEE), U13.8 (VSS), U14.1 (VSS), U14.24 (~A9~), U15.2 (-), U16.2 (-), Y2.2
unnamed: C1.2, R1.2, R2.2, U1.4 (FB)
unnamed: C2.1, C3.1, D2.3 (+), U1.1 (VIN)
unnamed: C35.2, R15.2, U9.13, Y1.2
unnamed: C36.2, R23.2, Y1.1
unnamed: C37.1, R19.1, R36.2
unnamed: C37.2, U11.6 (RIN)
unnamed: C38.1, R24.1, R35.2
unnamed: C38.2, U11.7 (GIN)
unnamed: C39.1, R30.1, R34.2
unnamed: C39.2, U11.8 (BIN)
unnamed: C40.1, U11.10 (COMP)
unnamed: C40.2, R31.1
unnamed: C43.1, R56.2, U11.3 (FIN), Y2.1
unnamed: C47.1, RV1.1
unnamed: C47.2, R51.2, U9.5
unnamed: C48.1, U9.8
unnamed: C51.1, D11.2 (A), D15.1 (K), R5.1, R57.1, U9.1
unnamed: C51.2, R47.2
unnamed: D1.1 (K), R3.1
unnamed: D2.2 (~~), J1.2, J1.3, J3.4
unnamed: D2.4 (~~), J3.2, SW1.2 (B)
unnamed: D3.1 (K), L1.1, L2.1, U1.2 (OUT)
unnamed: D11.1 (K), D15.2 (A), U9.2, U9.3
unnamed: J1.1, SW1.1 (A)
unnamed: J4.1, Q5.1 (E)
unnamed: J4.2, Q6.1 (E)
unnamed: J4.3, Q7.1 (E)
unnamed: J4.4, Q8.1 (E)
unnamed: J4.5, Q9.1 (E)
unnamed: J4.6, Q10.1 (E)
unnamed: J4.7, Q11.1 (E)
unnamed: J4.8, Q12.1 (E)
unnamed: J8.10, JP5.2 (B)
unnamed: J13.2, U14.21 (IOA0)
unnamed: J13.3, U14.20 (IOA1)
unnamed: J13.4, U14.19 (IOA2)
unnamed: J13.5, U14.18 (IOA3)
unnamed: J13.6, U14.17 (IOA4)
unnamed: J13.7, U14.16 (IOA5)
unnamed: J13.8, U14.15 (IOA6)
unnamed: J13.9, U14.14 (IOA7)
unnamed: J19.2, Q13.3 (D), R7.1
unnamed: J19.3, Q14.3 (D), R50.1
unnamed: JP2.1, R13.2, U8.1 (A18)
unnamed: JP3.1, R14.2, U8.30 (A17)
unnamed: JP4.2, R18.2, U8.31 (~WE)
unnamed: JP6.2 (C), U11.1 (STDN)
unnamed: Q1.3 (E), R9.1, R11.1
unnamed: Q2.2 (B), R10.2, R12.2, R28.2
unnamed: Q2.3 (E), R16.1, R19.2
unnamed: Q3.2 (B), R17.2, R20.2, R27.2
unnamed: Q3.3 (E), R21.1, R24.2
unnamed: Q4.2 (B), R22.2, R25.2, R26.2
unnamed: Q4.3 (E), R29.1, R30.2
unnamed: R15.1, R23.1, U9.11, U9.12
unnamed: R39.2, U14.4 (A)
unnamed: R40.2, U13.1 (Y1), U13.5 (Z0)
unnamed: R41.2, R42.2, U13.2 (Y0), U13.3 (Z1)
unnamed: R45.2, R46.2, RV1.2
unnamed: R51.1, U9.6, U9.9
unnamed: TP1.1, U6.20 (IO1_20/GCLK1)
unnamed: TP4.1, U6.21 (IO1_21)
unnamed: TP7.1, U6.94 (IO3_94)
unnamed: U13.4 (Z), U14.3 (B)
unnamed: U13.15 (Y), U14.38 (C)
~MAGIC: J14.1, SW2.2, U6.84 (IO3_84)
~RST: C49.1, J17.1, SW3.2, U6.61 (IO4_61/DEV_CLRn)

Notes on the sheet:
CPU
SD CARD
SOUND
0 - ACB 1 - ABC
AY Serial: IO2 - RTS (out) IO3 - TX (out) IO6 - DTR (in) IO7 - RX (in)
For 256K RAM compatibility: VA18<->A17 VA17<->A18
POWER
ZXBUS
CLOCK
MEMORY
1-bit DAC
MH-M18 Bluetooth module header
TAPE
install one of L1 OR L2
install one of J16 or J21
DAT* pullups connected to keyboard's RN
IO75
JTAG
x1 x0 Vout(mV) --------- 0 0 0 0 1 0 z 1 133 1 0 437 1 z 568 1 1 682
NTSC
PAL
VIDEO
PORTS
install one of J9 or J10
install one of J6 or J7
PS/2
KEYBOARD
JOYSTICK
connect to VCC for DIP28
2N7000 may be used with some cautions due to high Vgs(th)
HCU only!

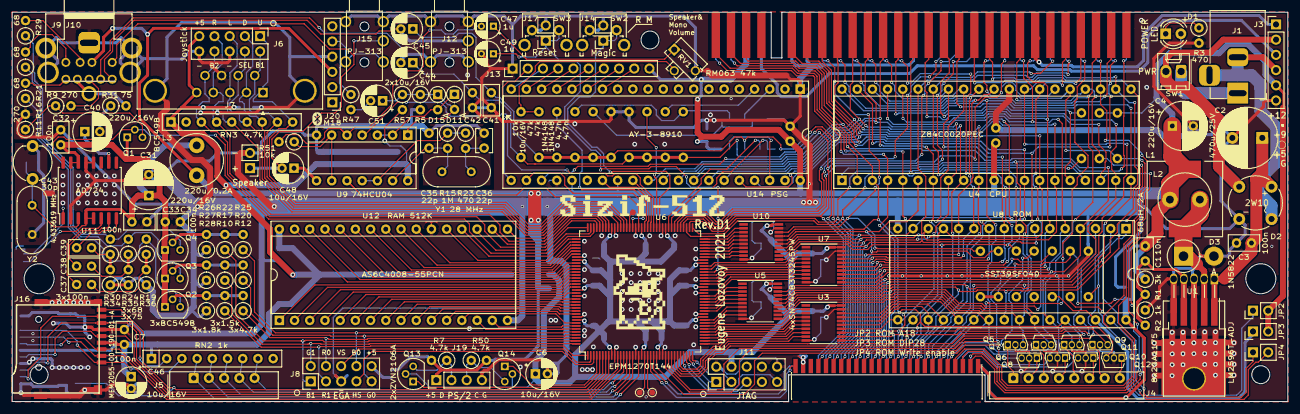
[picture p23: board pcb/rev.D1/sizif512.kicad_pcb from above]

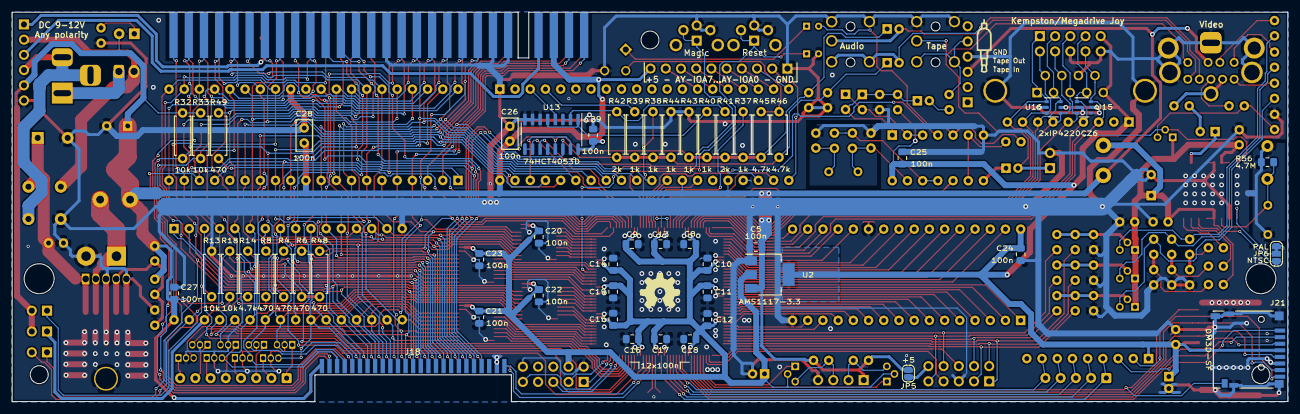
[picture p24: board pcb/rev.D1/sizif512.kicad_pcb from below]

Board: 2 copper layers, 213.0 x 65.0 mm, 188 parts (53 on the bottom side), 240 nets.

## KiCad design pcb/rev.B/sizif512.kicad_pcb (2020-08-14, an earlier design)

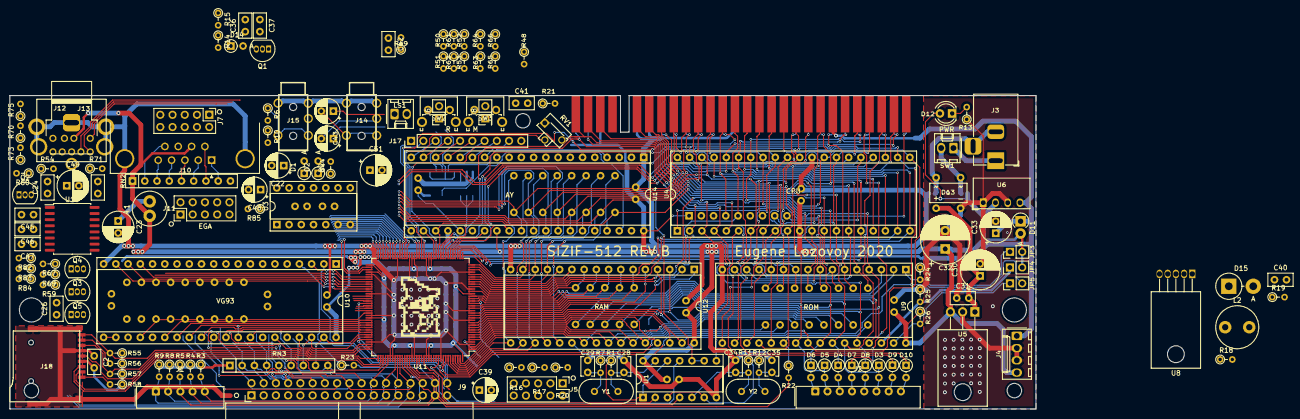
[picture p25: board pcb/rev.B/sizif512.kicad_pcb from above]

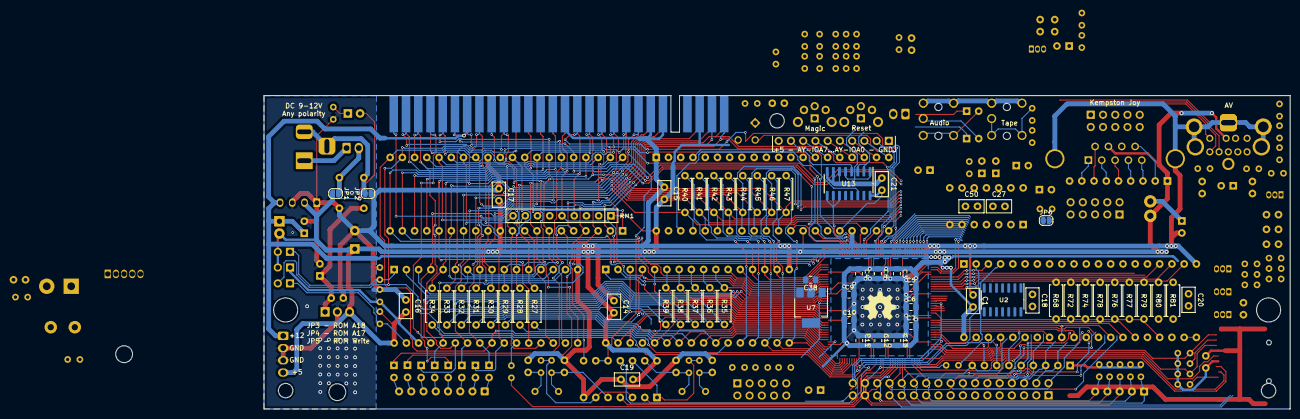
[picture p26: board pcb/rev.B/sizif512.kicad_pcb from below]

Board: 2 copper layers, 213.0 x 65.1 mm, 214 parts (61 on the bottom side), 231 nets.

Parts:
C1, C2, C14, C15, C16, C17, C18, C19, C20, C21, C24, C25, C26, C27, C31, C36, C40, C41, C45, C46, C47, C50: 100n; C_Disc_D5.0mm_W2.5mm_P2.50mm
C3, C4, C5, C6, C7, C8, C9, C10, C11, C12, C13, C38: 100n; C_0805_2012Metric_Pad1.15x1.40mm_HandSolder
C22, C43, C44, C48: 10u/16V; CP_Radial_D5.0mm_P2.50mm
C23, C49, C51: 220u/16V; CP_Radial_D6.3mm_P2.50mm
C28, C34: 33p; C_Disc_D3.8mm_W2.6mm_P2.50mm
C29, C35: 47p; C_Disc_D3.8mm_W2.6mm_P2.50mm
C30: 100u/50V; CP_Radial_D8.0mm_P2.50mm
C32: 470u/25V; CP_Radial_D10.0mm_P3.80mm
C33: 100u/25V; CP_Radial_D6.3mm_P2.50mm
C37: 10n; C_Disc_D5.0mm_W2.5mm_P2.50mm
C39: 100u/16V; CP_Radial_D5.0mm_P2.50mm
C42: 47n; C_Disc_D5.0mm_W2.5mm_P2.50mm
D1, D2: 1N4148; D_DO-35_SOD27_P2.54mm_Vertical_AnodeUp
D3, D4, D5, D6, D7, D8, D9, D10, D14: BAT85; D_DO-35_SOD27_P2.54mm_Vertical_AnodeUp
D11: 1N5817; D_DO-41_SOD81_P2.54mm_Vertical_AnodeUp
D12: LED; LED_D4.0mm
D13: DB207; DB-1
D15: D; D_DO-201AD_P5.08mm_Vertical_AnodeUp
H1, H2: MountingHole; MountingHole_5mm
H3, H4, H5: MountingHole; MountingHole_3mm
J1: Conn_01x05; FFC_FPC_1x05
J2: Conn_01x08; FFC_FPC_1x08
J3: DS-210; BarrelJack_Horizontal
J4: WF-4; Molex_KK-254_AE-6410-04A_1x04_P2.54mm_Vertical
J5: JTAG; PinHeader_2x05_P2.54mm_Vertical
J6, J8: Conn_01x02; PinHeader_2x01_P2.54mm_Vertical
J7: Conn_02x05_Top_Bottom; PinHeader_2x05_P2.54mm_Vertical
J9: Conn_02x17_Odd_Even; IDC-Header_2x17_P2.54mm_Horizontal_Mirrored
J10: DB9-M; DSUB-9_Male_Horizontal_P2.77x2.84mm_EdgePinOffset4.94mm_Hou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
J11: Conn_02x05_Odd_Even; PinHeader_2x05_P2.54mm_Vertical
J12: Mini-DIN-9; minidin-9
J13: RCJ-014; CUI_RCJ-01X-WIDE
J14, J15: PJ-313
J16: Conn_02x28_Row_Letter_First; ZX_EDGE
J17: Conn_01x10; PinHeader_1x10_P2.54mm_Vertical
J18: MEM2055-00-190-01-A; GCT-MEM2055-00-190-01-A
JP1, JP2, JP6: SolderJumper_2_Open; SolderJumper-2_P1.3mm_Open_RoundedPad1.0x1.5mm
JP3, JP4, JP5: Jumper; PinHeader_1x02_P2.54mm_Vertical
L1: 220u/0.2A; L_Radial_D7.0mm_P3.00mm
L2: L; L_Radial_D8.7mm_P5.00mm_Fastron_07HCP
LOGO1: Logo_Open_Hardware_Small; OSHW-Symbol_6.7x6mm_SilkScreen
LOGO2: graphic; black-mage2
LS1: WF-2; Molex_KK-254_AE-6410-02A_1x02_P2.54mm_Vertical
Q1: BC547B; TO-92_Inline
Q2, Q3, Q4, Q5: BC547C; TO-92_Inline
R1, R11: 1M; R_Axial_DIN0204_L3.6mm_D1.6mm_P2.54mm_Vertical
R2, R10: 47k; R_Axial_DIN0204_L3.6mm_D1.6mm_P2.54mm_Vertical
R3, R4, R5, R8, R9, R16, R17, R20, R23, R24, R25, R26, R55, R56, R57, R58, R65, R66: 10k; R_Axial_DIN0204_L3.6mm_D1.6mm_P2.54mm_Vertical
R6, R7, R12, R15, R52, R53, R63, R64: 1k; R_Axial_DIN0204_L3.6mm_D1.6mm_P2.54mm_Vertical
R13, R18, R19, R22, R48: 470; R_Axial_DIN0204_L3.6mm_D1.6mm_P2.54mm_Vertical
R14: 220k; R_Axial_DIN0204_L3.6mm_D1.6mm_P2.54mm_Vertical
R21, R85: 100k; R_Axial_DIN0204_L3.6mm_D1.6mm_P2.54mm_Vertical
R27, R28, R29, R30, R31, R32, R33, R34, R35, R36, R37, R38, R39, R40, R41, R42, R43, R44, R45, R46, R47: 1k; R_Axial_DIN0207_L6.3mm_D2.5mm_P7.62mm_Horizontal
R49, R54, R60: 270; R_Axial_DIN0204_L3.6mm_D1.6mm_P2.54mm_Vertical
R50, R51, R61, R62: 2k; R_Axial_DIN0204_L3.6mm_D1.6mm_P2.54mm_Vertical
R59, R67, R69, R70, R73, R75: 68; R_Axial_DIN0204_L3.6mm_D1.6mm_P2.54mm_Vertical
R68, R72, R74, R76, R77, R78, R79, R80, R81: 3.6k; R_Axial_DIN0207_L6.3mm_D2.5mm_P7.62mm_Horizontal
R71, R82, R83, R84: 75; R_Axial_DIN0204_L3.6mm_D1.6mm_P2.54mm_Vertical
RN1, RN2: 10k; R_Array_SIP9
RN3: 4.7k; R_Array_SIP9
RV1: 47k; Potentiometer_Runtron_RM-063_Horizontal
SW1: Conn_01x02; Molex_KK-254_AE-6410-02A_1x02_P2.54mm_Vertical
SW2, SW3: WF-2; SW_Tactile_SPST_Angled_PTS645Vx83-2LFS
U1, U3: 74HCU04; DIP-14_W7.62mm_Socket
U2: 74HCT05; SOIC-14_3.9x8.7mm_P1.27mm
U4: Z84C0008PEC; DIP-40_W15.24mm_Socket
U5: L4940V5 / K7805-2000R3L; TO-220-3_Horizontal_TabDown
U6: AM1S-0512SZ; Converter_DCDC_muRata_CRE1xxxxxx3C_THT
U7: AMS1117-3.3; SOT-223-3_TabPin2
U8: LM2596T-ADJ; TO-220-5_Horizontal_TabDown
U9: 29C040; DIP-32_W15.24mm_Socket
U10: 1818VG93; DIP-40_W15.24mm_Socket
U11: EPM3256ATC144; TQFP-144_20x20mm_P0.5mm
U12: AS6C4008-55PCN; DIP-32_W15.24mm_Socket
U13: 74HCT4053D; SOIC-16_3.9x9.9mm_P1.27mm
U14: AY-3-8310; DIP-40_W15.24mm_Socket
U15: AD724; SOIC-16W_7.5x10.3mm_P1.27mm
Y1: 17.734475 MHz; Crystal_HC49-U_Vertical
Y2: 8 MHz; Crystal_HC49-U_Vertical

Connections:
+3V3: C2.2, C3.2, C4.2, C5.2, C6.2, C7.2, C8.2, C9.2, C10.2, C11.2, C12.2, C13.2, C39.1, J5.4, J18.4, R16.2, R17.2, R55.1, R56.1, R57.1, R58.1, U7.2, U11.24, U11.50, U11.51, U11.58, U11.73, U11.76, U11.95, U11.115, U11.123, U11.130, U11.144
+5V: C14.2, C15.2, C16.2, C17.2, C18.2, C19.2, C20.2, C21.2, C32.1, C38.2, D11.2, D12.2, J4.4, J7.4, J10.7, J12.2, J16.A3, J17.10, JP1.2, JP3.2, JP4.2, JP6.1, L1.1, R3.1, R4.1, R5.1, R8.1, R9.1, R14.1, R21.2, R23.1, R26.1, RN1.1, RN2.1, RN3.1, U1.14, U2.14, U4.11, U5.3, U6.2, U7.3, U9.32, U10.21, U10.22, U12.32, U13.16, U14.25, U14.28, U14.40
+5VA: C23.1, C24.2, C25.2, C26.2, C27.2, L1.2, Q2.1, Q3.1, Q4.1, Q5.1, U3.14, U15.4, U15.5, U15.14, U15.15
+12V: C1.2, C33.1, D11.1, J4.1, J16.B22, U6.4, U10.40
/<: J16.A13, R48.1, U11.54
/>: R48.2, U11.53
/A0: J16.A9, R27.1, U4.30, U9.12
/A1: J16.A10, R28.1, U4.31, U9.11
/A2: J16.A11, R29.1, U4.32, U9.10
/A3: J16.A12, R30.1, U4.33, U9.9
/A4: J16.A24, R31.1, U4.34, U9.8
/A5: J16.A23, R32.1, U4.35, U9.7, U10.5
/A6: J16.A22, R33.1, U4.36, U9.6, U10.6
/A7: J16.A21, R34.1, U4.37, U9.5
/A8: D3.1, J16.B26, R35.1, U4.38, U9.27
/A9: D4.1, J16.A27, R36.1, U4.39, U9.26
/A10: D5.1, J16.B27, R37.1, U4.40, U9.23
/A11: D6.1, J16.A28, R38.1, U4.1, U9.25
/A12: D7.1, J16.A2, R39.1, U4.2, U9.4
/A13: D8.1, J16.B2, U4.3, U9.28, U11.132
/A14: D9.1, J16.A1, U4.4, U11.46
/A15: D10.1, J16.B1, U4.5, U11.48
/AY_ABC: U11.43, U13.9, U13.10, U13.11
/AY_BC1: U11.41, U14.29
/AY_BDIR: U11.42, U14.27
/AY_CLK: U11.49, U14.22
/Blue: J11.1, R74.1, U11.74
/Bright: J11.4, J11.8, J11.9, R76.2, R77.2, R78.2, U11.70
/CLK8: U1.4, U11.125
/CLK17: U1.2, U11.128, U15.3
/CLKCPU: U1.8, U4.6
/CLKCPU0: U1.11, U11.134
/Csync: Q2.2, U11.75, U15.16
/D0: J16.B6, R40.1, U4.14, U9.13, U10.7, U14.37
/D1: J16.B7, R41.1, U4.15, U9.14, U10.8, U14.36
/D2: J16.B8, R42.1, U4.12, U9.15, U10.9, U14.35
/D3: J16.B11, R43.1, U4.8, U9.17, U10.10, U14.34
/D4: J16.B12, R44.1, U4.7, U9.18, U10.11, U14.33
/D5: J16.B10, R45.1, U4.9, U9.19, U10.12, U14.32
/D6: J16.B9, R46.1, U4.10, U9.20, U10.13, U14.31
/D7: J16.B3, R47.1, U4.13, U9.21, U10.14, U14.30
/FD_CLK: U10.24, U11.93
/FD_CS: U10.3, U11.78
/FD_DDEN: U10.37, U11.106
/FD_DIR: U2.3, U10.16
/FD_DISK0: J9.14, U11.92
/FD_DISK1: J9.12, RN3.5, U11.86
/FD_DRQ: RN3.7, U10.38, U11.103
/FD_HLT: U10.23, U11.90
/FD_INDEX: J9.8, RN3.2, U11.91
/FD_INDEX1: U10.35, U11.107
/FD_INTRQ: RN3.8, U10.39, U11.102
/FD_MOTOR: U2.13, U10.28, U10.32, U11.98
/FD_RAWR: U10.27, U11.97
/FD_RDAT: J9.30, RN3.9, U11.84
/FD_RST: U10.19, U11.83
/FD_S: U10.26, U11.96
/FD_SIDE: U2.9, U11.88
/FD_SL: U10.17, U11.81
/FD_SR: U10.18, U11.82
/FD_STEP: U2.1, U10.15
/FD_TR00: J9.26, RN3.3, U10.34
/FD_TR43: U10.29, U11.99
/FD_WD: U10.31, U11.100
/FD_WDAT: U2.5, U11.87
/FD_WF_DE: RN3.6, U10.33, U11.101
/FD_WPT: J9.28, RN3.4, U10.36
/FD_WSTB: U2.11, U10.30
/Green: J11.2, R72.1, U11.71
/Hsync: J11.7, U11.80
/KA8: D3.2, J2.6
/KA9: D4.2, J2.3
/KA10: D5.2, J2.2
/KA11: D6.2, J2.1
/KA12: D7.2, J2.4
/KA13: D8.2, J2.5
/KA14: D9.2, J2.7
/KA15: D10.2, J2.8
/KD0: J1.1, R9.2, U11.116
/KD1: J1.2, R8.2, U11.113
/KD2: J1.3, R5.2, U11.121
/KD3: J1.4, R4.2, U11.120
/KD4: J1.5, R3.2, U11.119
/RA14: U9.29, U11.25
/RA15: U9.3, U11.22
/RA16: U9.2, U11.23
/Red: J11.3, R68.1, U11.72
/SD_CD: J18.9, R55.2, U11.108
/SD_CS: J18.2, U11.111
/SD_MISO: J18.7, R57.2, U11.109
/SD_MOSI: J18.3, U11.112
/SD_SCK: J18.5, U11.110
/SND_DAC: R49.1, U11.61
/SND_L: C43.2, J12.8, J14.T
/SND_MONO: C48.2, J12.6
/SND_R: C44.2, J12.9, J14.R
/TAPE_IN: J15.R, J15.T, R6.1
/TAPE_IN0: RN2.9, U3.12, U11.55
/TCK: J5.1, R20.2, U11.89
/TDI: J5.9, R16.1, U11.4
/TDO: J5.3, U11.104
/TMS: J5.5, R17.1, U11.20
/VA0: R27.2, U11.6, U12.27
/VA1: R28.2, U11.7, U12.28
/VA2: R29.2, U11.5, U12.26
/VA3: R30.2, U11.2, U12.25
/VA4: R31.2, U11.143, U12.23
/VA5: R32.2, U11.12, U12.4
/VA6: R33.2, U11.11, U12.3
/VA7: R34.2, U11.10, U12.31
/VA8: R35.2, U11.27, U12.10
/VA9: R36.2, U11.21, U12.9
/VA10: R37.2, U11.19, U12.8
/VA11: R38.2, U11.18, U12.7
/VA12: R39.2, U11.16, U12.6
/VA13: U11.15, U12.5
/VA14: U11.34, U12.12
/VA15: U11.32, U12.11
/VA16: U11.28, U12.2
/VA17: U11.9, U12.30
/VA18: U11.14, U12.1
/VD0: R40.2, U11.142, U12.21
/VD1: R41.2, U11.35, U12.13
/VD2: R42.2, U11.141, U12.20
/VD3: R43.2, U11.36, U12.14
/VD4: R44.2, U11.138, U12.19
/VD5: R45.2, U11.37, U12.15
/VD6: R46.2, U11.139, U12.18
/VD7: R47.2, U11.140, U12.17
/VID_B: J12.1, R75.2
/VID_COMP: J12.4, J13.1, R71.2
/VID_G: J12.3, R73.2
/VID_R: J12.7, R70.2
/VID_SYNC: J12.5, R54.2
/Vsync: J11.6, U11.79
/~BUSACK: J16.A26, U4.23
/~BUSRQ: J16.A19, RN1.9, U4.25
/~CLKCPU: J16.A8, U1.9, U1.10
/~HALT: J16.B15, U4.18
/~INT: J16.B13, RN1.4, U4.16, U11.38
/~IORQ: J16.B17, U4.20, U11.31
/~JOY_B1: J7.2, J10.6, RN2.7, U11.63
/~JOY_B2: J7.8, J10.9, RN2.2, U11.69
/~JOY_B3: J7.9, J10.5, RN2.3, U11.68
/~JOY_DOWN: J7.3, J10.2, RN2.6, U11.65
/~JOY_LEFT: J7.5, J10.3, RN2.5, U11.66
/~JOY_RIGHT: J7.7, J10.4, RN2.4, U11.67
/~JOY_UP: J7.1, J10.1, RN2.8, U11.62
/~M1: J16.B24, U4.27, U11.40
/~MREQ: J16.B16, U4.19, U11.30
/~NMI: J16.B14, RN1.5, U4.17, U11.39
/~RD: J16.B18, RN1.6, U4.21, U9.24, U10.4, U11.137
/~RFSH: J16.B25, U4.28, U11.29
/~ROMCS: J16.A25, R22.1, U9.22
/~ROMCS0: R22.2, U11.122
/~RSTCPU: J16.A20, RN1.7, U4.26, U11.47, U14.23
/~VRD: U11.1, U12.24
/~VWR: U11.8, U12.29
/~WAIT: J16.B21, RN1.8, U4.24
/~WR: J16.B19, JP5.2, U4.22, U10.2, U11.136
GND: C1.1, C2.1, C3.1, C4.1, C5.1, C6.1, C7.1, C8.1, C9.1, C10.1, C11.1, C12.1, C13.1, C14.1, C15.1, C16.1, C17.1, C18.1, C19.1, C20.1, C21.1, C23.2, C24.1, C25.1, C26.1, C27.1, C28.1, C29.1, C30.2, C31.1, C32.2, C33.2, C34.1, C35.1, C37.1, C38.1, C39.2, C41.1, C42.1, D13.1, D14.2, D15.2, J4.2, J4.3, J5.2, J5.10, J6.2, J7.6, J7.10, J8.2, J9.1, J9.3, J9.5, J9.7, J9.9, J9.11, J9.13, J9.15, J9.17, J9.19, J9.21, J9.23, J9.25, J9.27, J9.29, J9.31, J9.33, J10.0, J10.8, J11.5, J12.0, J13.2, J14.S, J15.S, J16.A6, J16.A7, J16.A14, J17.1, J18.6, J18.10, JP2.2, LS1.2, Q1.3, R10.1, R13.1, R20.1, R24.1, R25.1, R60.2, R63.2, R64.2, R79.2, R80.2, R81.2, R82.2, R83.2, R84.2, RV1.3, SW2.1, SW3.1, U1.7, U2.7, U3.7, U4.29, U5.2, U6.1, U6.3, U7.1, U8.3, U8.5, U9.16, U10.20, U11.3, U11.13, U11.17, U11.26, U11.33, U11.52, U11.57, U11.59, U11.64, U11.77, U11.85, U11.94, U11.105, U11.114, U11.124, U11.129, U11.135, U12.16, U12.22, U13.6, U13.7, U13.8, U14.1, U14.24, U15.1, U15.2, U15.12, U15.13
unnamed: C22.1, D1.2, D2.1, R10.2, U3.9
unnamed: C22.2, R6.2
unnamed: C28.2, R1.2, U1.13, Y1.1
unnamed: C29.2, R7.2, Y1.2
unnamed: C30.1, C31.2, D13.4, U5.1
unnamed: C34.2, R11.2, U1.5, Y2.1
unnamed: C35.2, R12.2, Y2.2
unnamed: C36.1, C37.2, D14.1, Q1.2, R14.2
unnamed: C36.2, R15.2
unnamed: C42.2, R49.2, R50.2, R51.1
unnamed: C43.1, R51.2, R52.1, R62.1, R64.1, R66.1
unnamed: C44.1, R50.1, R53.2, R61.2, R63.1, R65.2
unnamed: C45.1, R59.2
unnamed: C45.2, U15.6
unnamed: C46.1, R67.2
unnamed: C46.2, U15.7
unnamed: C47.1, R69.2
unnamed: C47.2, U15.8
unnamed: C48.1, R65.1, R66.2, RV1.2
unnamed: C49.1, U15.10
unnamed: C49.2, R71.1
unnamed: C50.1, R85.1, U3.1
unnamed: C50.2, RV1.1
unnamed: C51.1, R85.2, U3.6
unnamed: C51.2, LS1.1
unnamed: D1.1, D2.2, R2.1, U3.8, U3.11
unnamed: D12.1, R13.2
unnamed: D13.2, JP1.1, SW1.2
unnamed: D13.3, J3.2, J3.3, JP2.1
unnamed: J3.1, SW1.1
unnamed: J9.10, J9.16, U2.12
unnamed: J9.18, U2.4
unnamed: J9.20, U2.2
unnamed: J9.22, U2.6
unnamed: J9.24, U2.10
unnamed: J9.32, U2.8
unnamed: J11.10, JP6.2
unnamed: J17.2, U14.21
unnamed: J17.3, U14.20
unnamed: J17.4, U14.19
unnamed: J17.5, U14.18
unnamed: J17.6, U14.17
unnamed: J17.7, U14.16
unnamed: J17.8, U14.15
unnamed: J17.9, U14.14
unnamed: J18.1, R58.2
unnamed: J18.8, R56.2
unnamed: JP3.1, R24.2, U9.1
unnamed: JP4.1, R25.2, U9.30
unnamed: JP5.1, R26.2, U9.31
unnamed: Q2.3, R54.1, R60.1
unnamed: Q3.2, R68.2, R78.1, R81.1
unnamed: Q3.3, R59.1, R70.1, R82.1
unnamed: Q4.2, R72.2, R77.1, R80.1
unnamed: Q4.3, R67.1, R73.1, R83.1
unnamed: Q5.2, R74.2, R76.1, R79.1
unnamed: Q5.3, R69.1, R75.1, R84.1
unnamed: R1.1, R7.1, U1.1, U1.12
unnamed: R2.2, U3.10, U3.13
unnamed: R11.1, R12.1, U1.3, U1.6
unnamed: R52.2, U13.12, U13.13
unnamed: R53.1, U13.2, U13.3
unnamed: R61.1, R62.2, U13.1, U13.5
unnamed: U3.2, U3.3
unnamed: U3.4, U3.5
unnamed: U13.4, U14.3
unnamed: U13.14, U14.4
unnamed: U13.15, U14.38
~MAGIC: J8.1, R23.2, SW3.2, U11.126
~RST: C41.2, J6.1, R21.1, SW2.2, U11.127

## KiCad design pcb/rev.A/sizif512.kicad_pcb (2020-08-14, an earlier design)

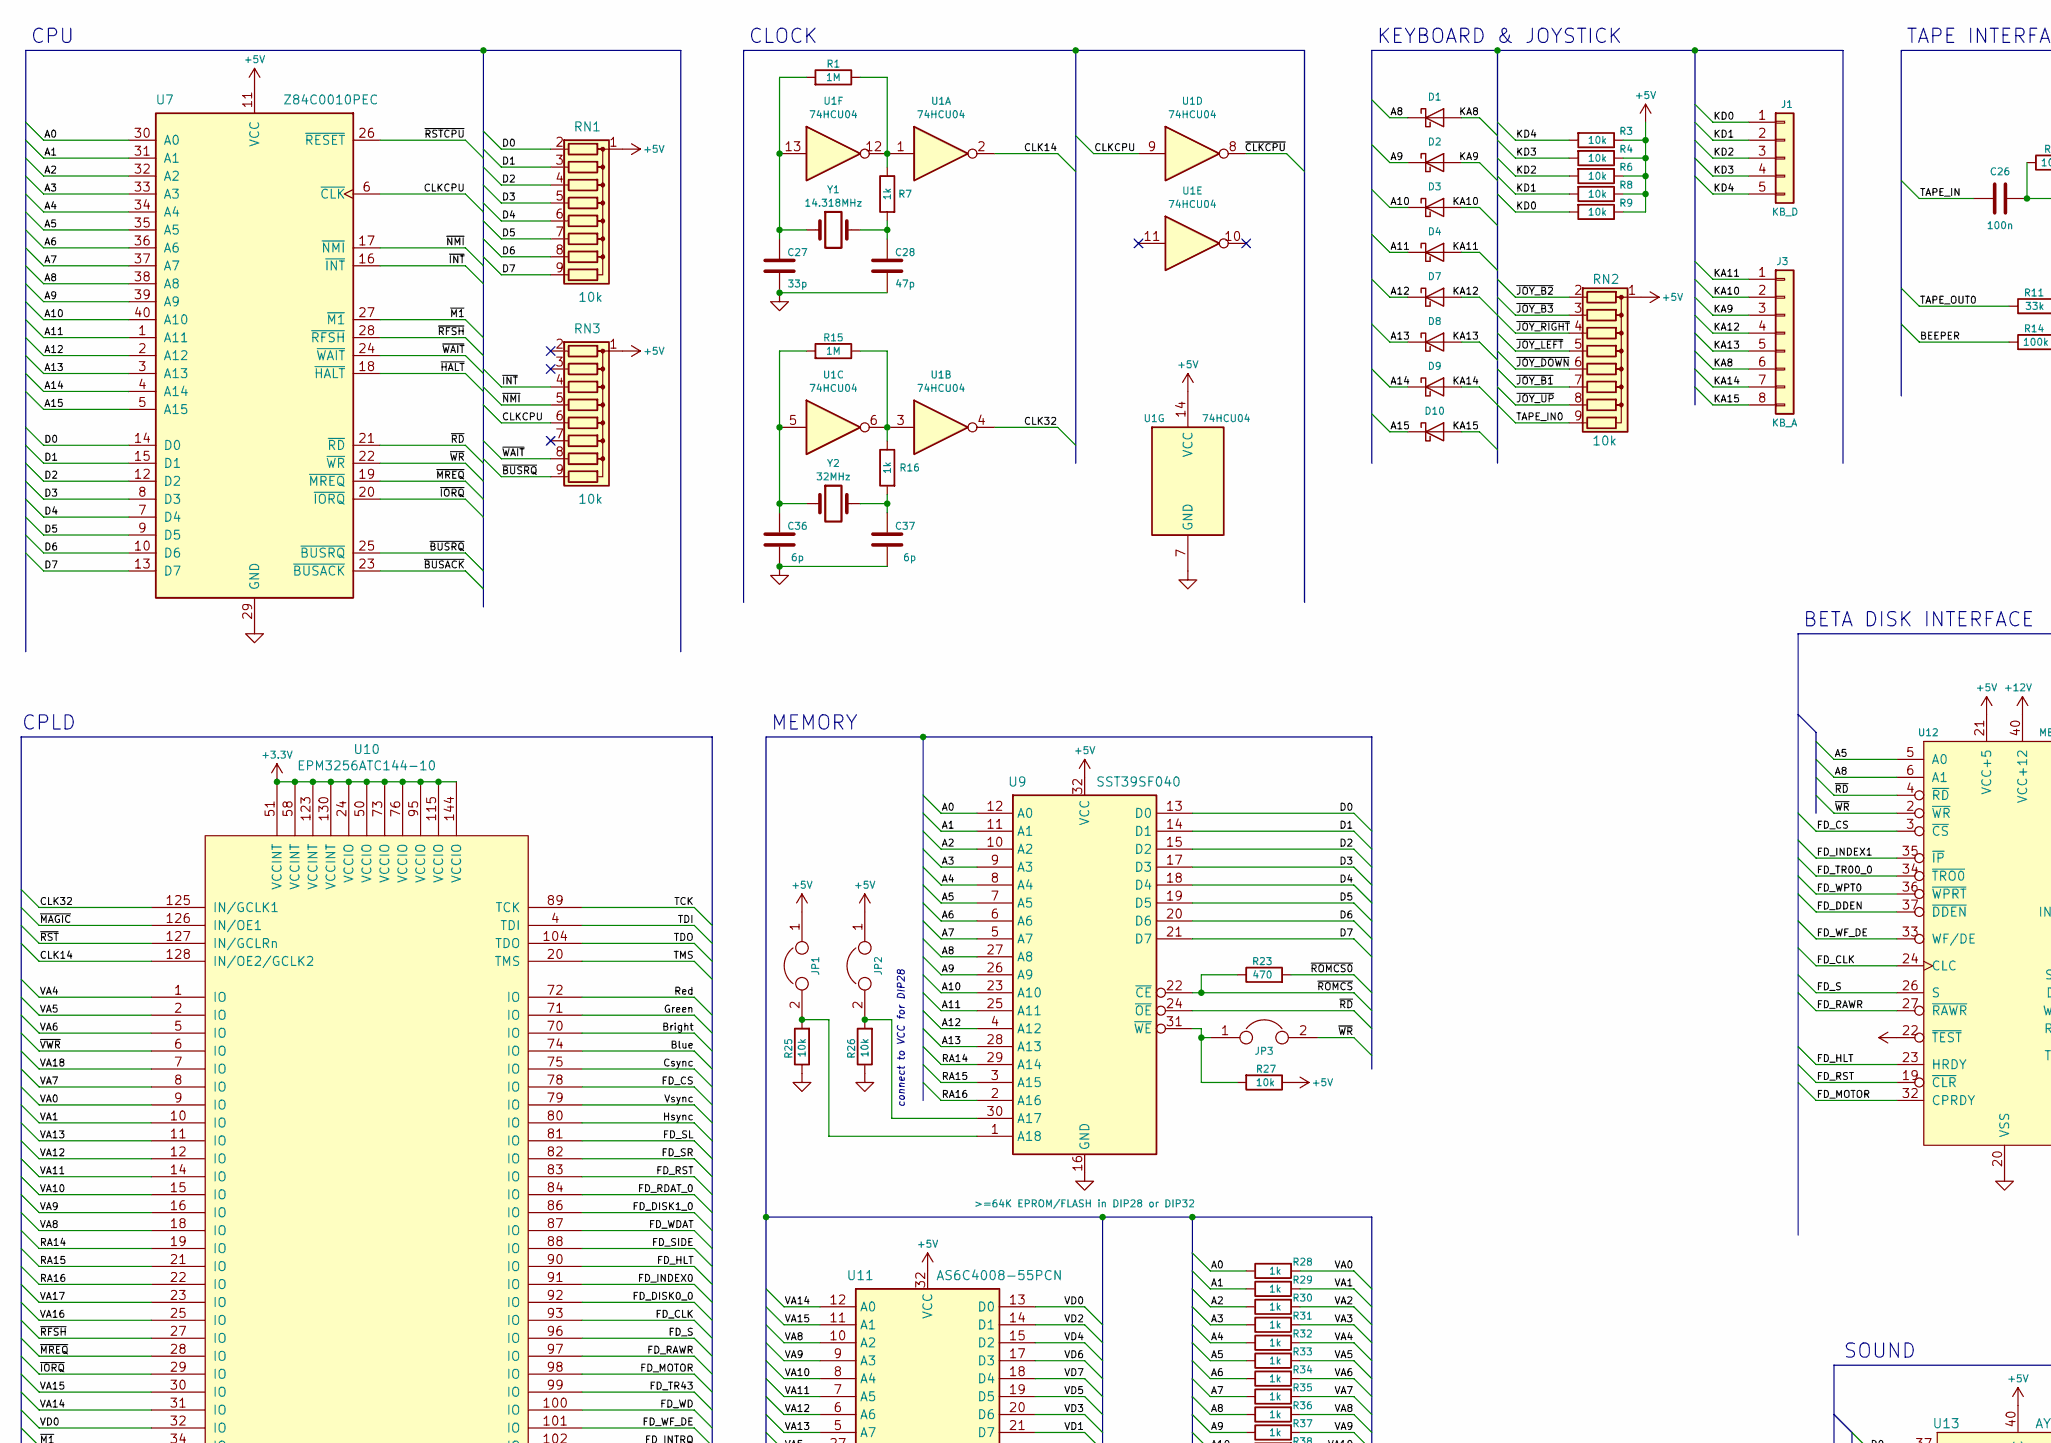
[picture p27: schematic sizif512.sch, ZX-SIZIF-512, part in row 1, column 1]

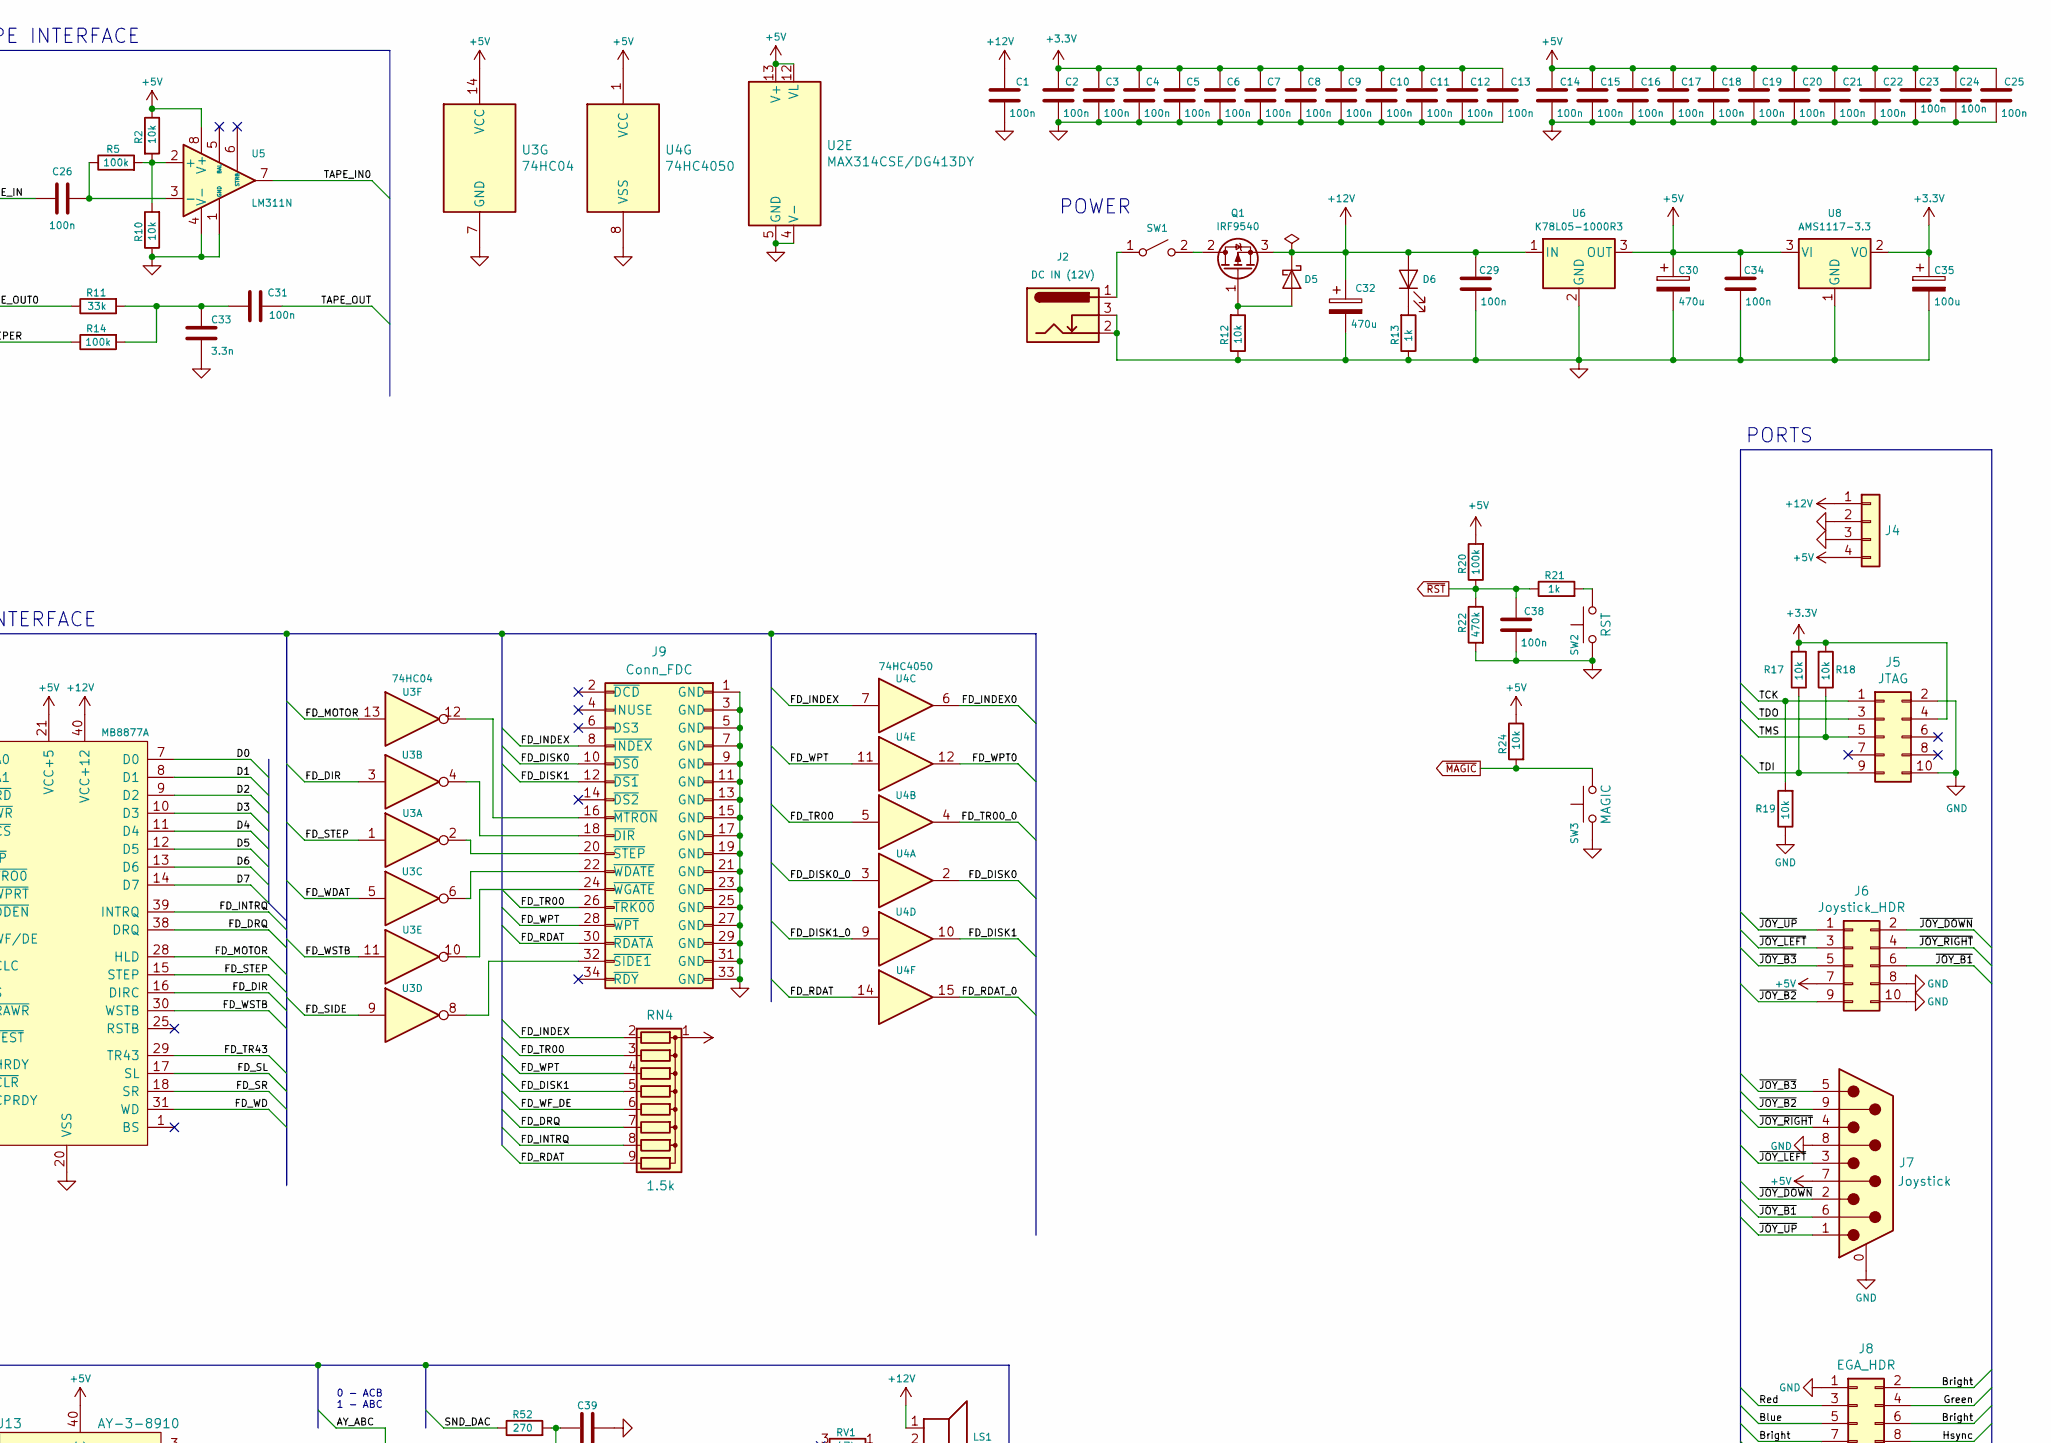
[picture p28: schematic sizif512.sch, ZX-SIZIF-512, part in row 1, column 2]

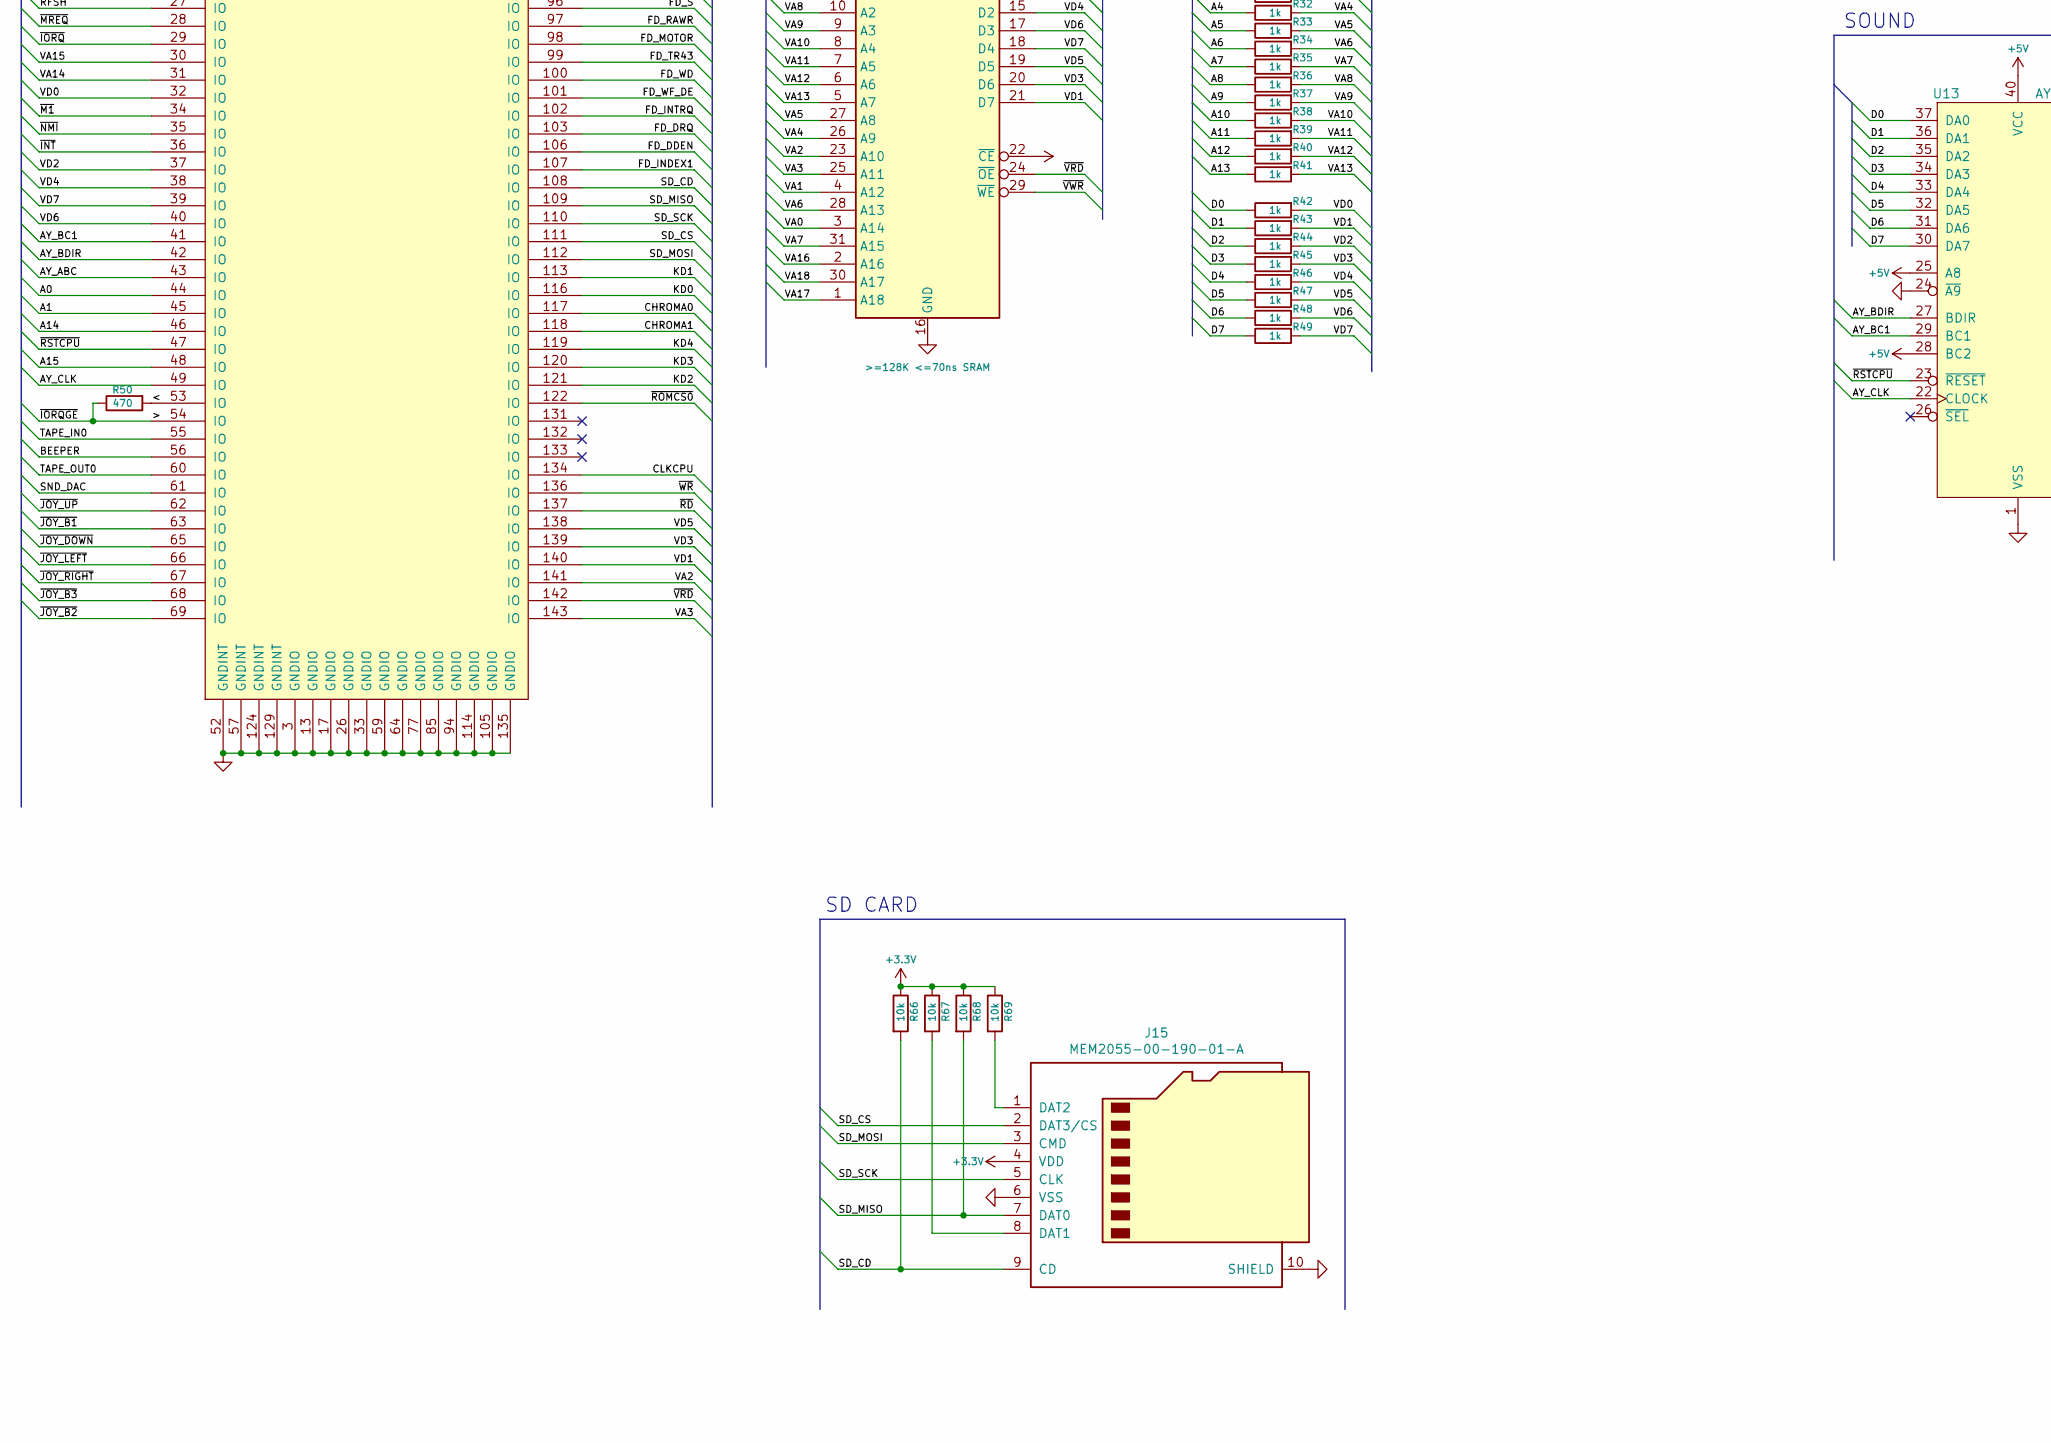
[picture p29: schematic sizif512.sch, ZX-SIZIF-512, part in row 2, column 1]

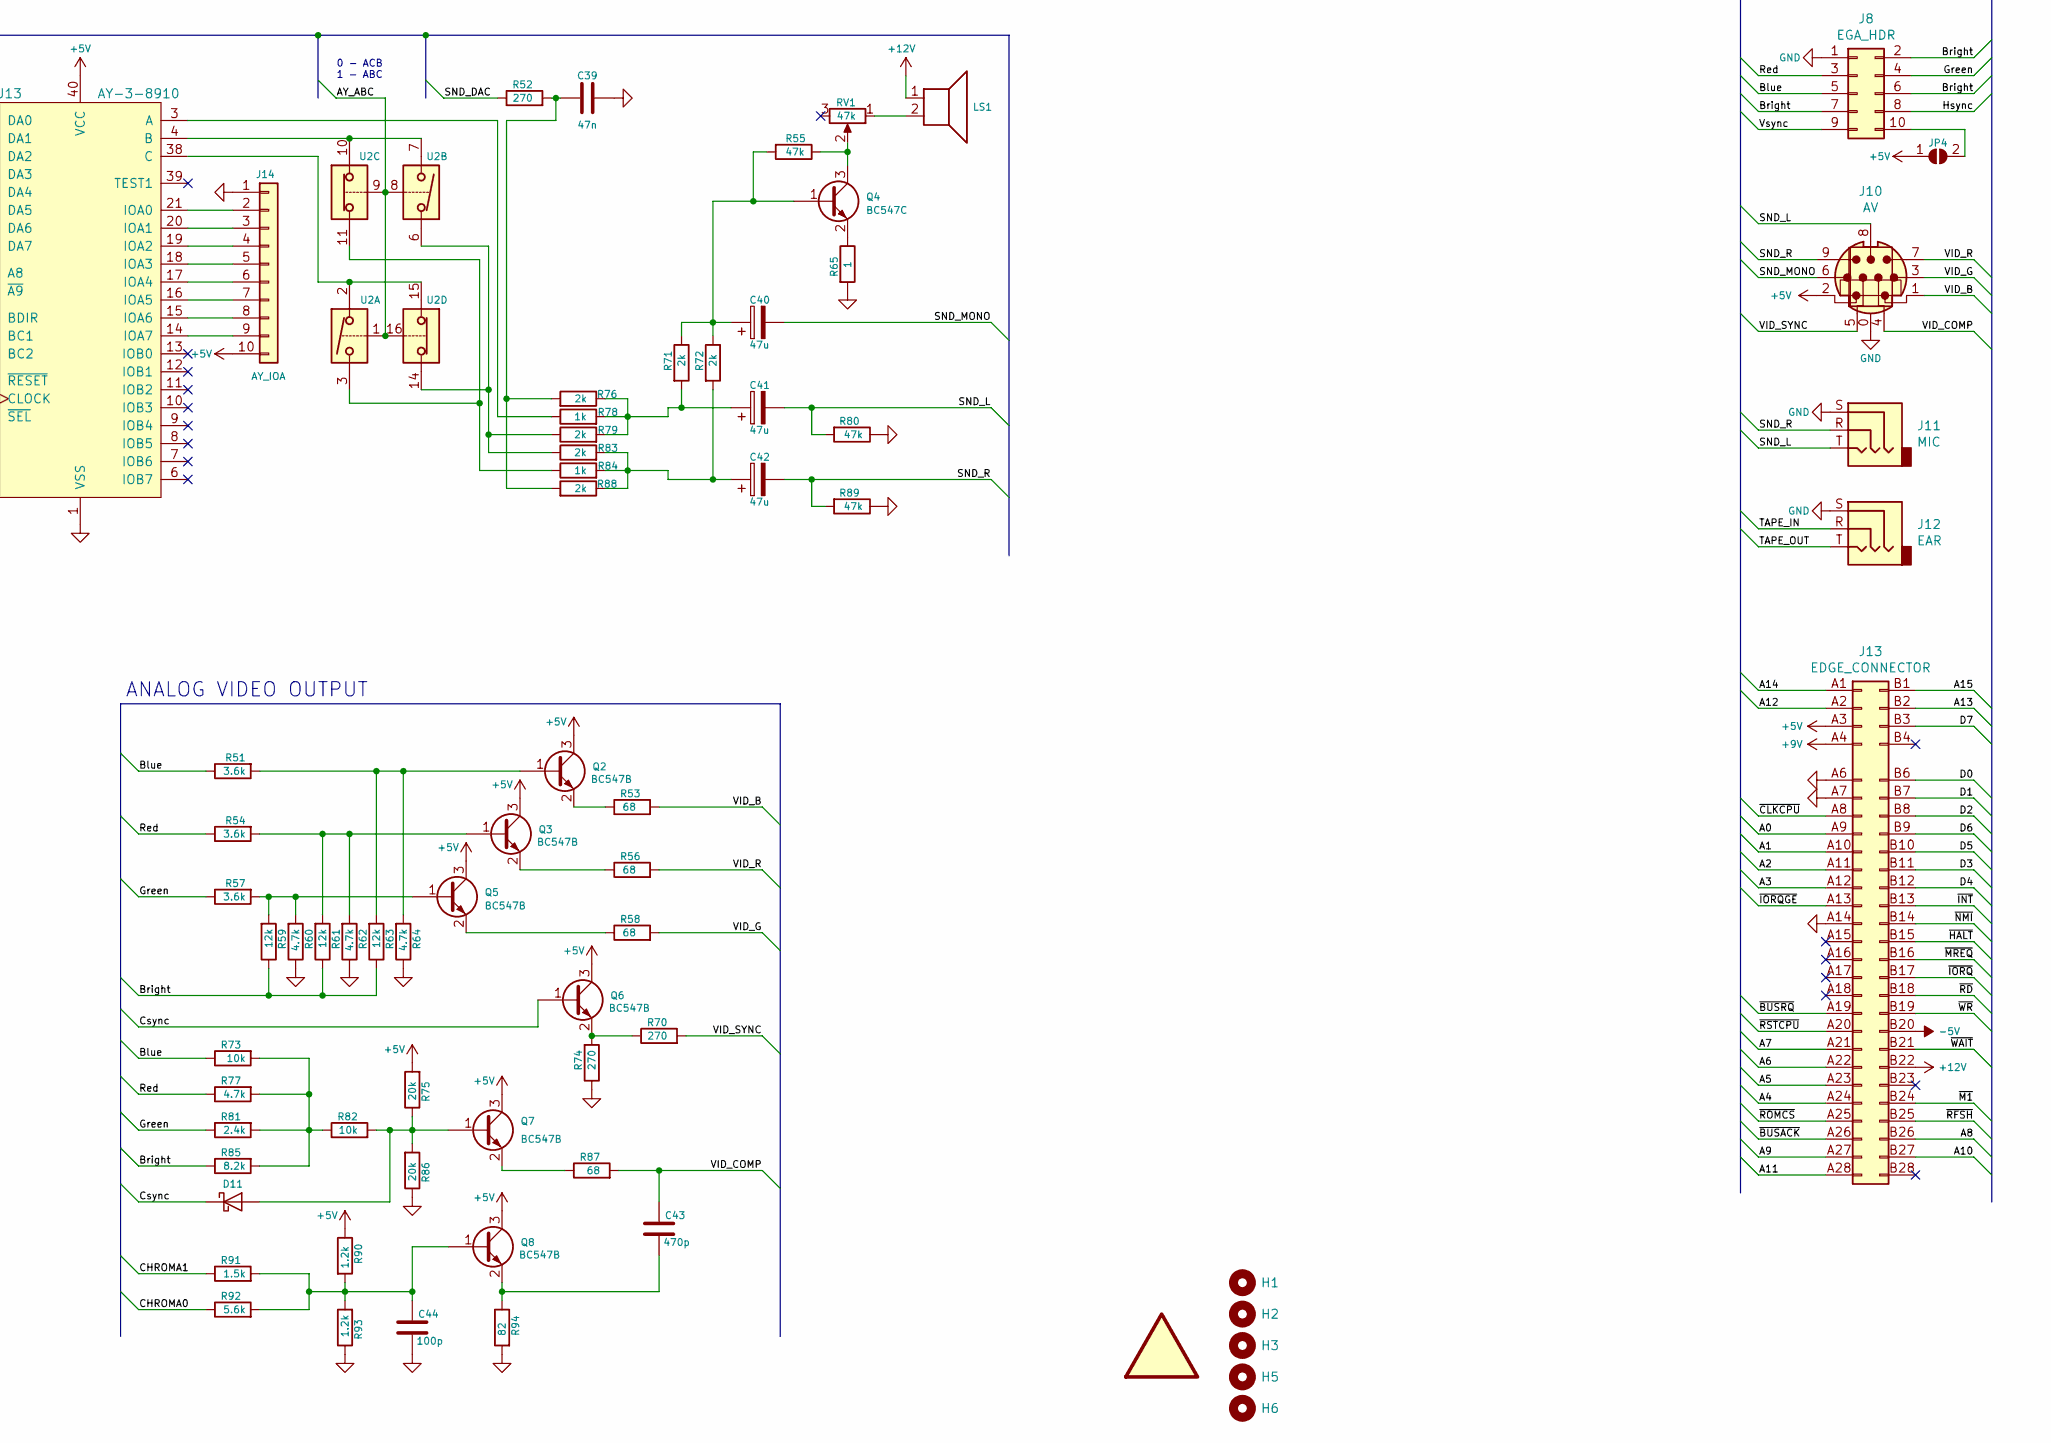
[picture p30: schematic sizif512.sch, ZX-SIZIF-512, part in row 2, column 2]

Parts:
C1, C2, C14, C15, C16, C17, C18, C19, C20, C21, C22, C23, C24, C25, C26, C29, C31, C34, C38: 100n; C_Disc_D7.0mm_W2.5mm_P5.00mm
C3, C4, C5, C6, C7, C8, C9, C10, C11, C12, C13: 100n; C_0805_2012Metric_Pad1.15x1.40mm_HandSolder
C27: 33p; C_Disc_D3.8mm_W2.6mm_P2.50mm
C28: 47p; C_Disc_D3.8mm_W2.6mm_P2.50mm
C30, C32: 470u; CP_Radial_D10.0mm_P3.80mm
C33: 3.3n; C_Disc_D5.0mm_W2.5mm_P2.50mm
C35: 100u; CP_Radial_D5.0mm_P2.50mm
C36, C37: 6p; C_Disc_D3.8mm_W2.6mm_P2.50mm
C39: 47n; C_Disc_D7.0mm_W2.5mm_P5.00mm
C40, C41, C42: 47u; CP_Radial_D5.0mm_P2.50mm
C43: 470p; C_Disc_D3.8mm_W2.6mm_P2.50mm
C44: 100p; C_Disc_D3.8mm_W2.6mm_P2.50mm
D1, D2, D3, D4, D5, D7, D8, D9, D10, D11: BAT85; D_DO-35_SOD27_P2.54mm_Vertical_AnodeUp
D6: LED; LED_D4.0mm
H1, H2: MountingHole; MountingHole_5mm
H3, H5, H6: MountingHole; MountingHole_3mm
J1: DS1020-05; PinSocket_1x05_P2.54mm_Vertical
J2: DS-210; BarrelJack_Horizontal
J3: DS1020-08; PinSocket_1x08_P2.54mm_Vertical
J4: WF-4; Molex_KK-254_AE-6410-04A_1x04_P2.54mm_Vertical
J5: Conn_02x05; PinHeader_2x05_P2.54mm_Vertical
J6, J8: Conn_02x05_Odd_Even; PinHeader_2x05_P2.54mm_Vertical
J7: DB9-M; DSUB-9_Male_Horizontal_P2.77x2.84mm_EdgePinOffset4.94mm_Hou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
J9: Conn_02x17_Odd_Even; PinHeader_2x17_P2.54mm_Vertical
J10: Mini-DIN-9; minidin-9
J11, J12: PJ-313
J13: Conn_02x28_Row_Letter_First; ZX_EDGE
J14: Conn_01x10; PinHeader_1x10_P2.54mm_Vertical
J15: MEM2055-00-190-01-A; GCT-MEM2055-00-190-01-A
JP1, JP2, JP3: Jumper; PinHeader_1x02_P2.54mm_Vertical
JP4: SolderJumper_2_Open; SolderJumper-2_P1.3mm_Open_RoundedPad1.0x1.5mm
LOGO1: graphic; black-mage2
LS1: WF-2; Molex_KK-254_AE-6410-02A_1x02_P2.54mm_Vertical
Q1: IRF9540; TO-220-3_Horizontal_TabDown
Q2, Q3, Q5, Q6, Q7, Q8: BC547B; TO-92_Inline
Q4: BC547C; TO-92_Inline
R1, R15: 1M; R_Axial_DIN0204_L3.6mm_D1.6mm_P2.54mm_Vertical
R2, R3, R4, R6, R8, R9, R10, R12, R17, R18, R19, R24, R25, R26, R27, R66, R67, R68, R69, R73, R82: 10k; R_Axial_DIN0204_L3.6mm_D1.6mm_P2.54mm_Vertical
R5, R14, R20: 100k; R_Axial_DIN0204_L3.6mm_D1.6mm_P2.54mm_Vertical
R7, R13, R16, R21, R78, R84: 1k; R_Axial_DIN0204_L3.6mm_D1.6mm_P2.54mm_Vertical
R11: 33k; R_Axial_DIN0204_L3.6mm_D1.6mm_P2.54mm_Vertical
R22: 470k; R_Axial_DIN0204_L3.6mm_D1.6mm_P2.54mm_Vertical
R23, R50: 470; R_Axial_DIN0204_L3.6mm_D1.6mm_P2.54mm_Vertical
R28, R29, R30, R31, R32, R33, R34, R35, R36, R37, R38, R39, R40, R41, R42, R43, R44, R45, R46, R47, R48, R49: 1k; R_Axial_DIN0204_L3.6mm_D1.6mm_P5.08mm_Horizontal
R51, R54, R57: 3.6k; R_Axial_DIN0204_L3.6mm_D1.6mm_P2.54mm_Vertical
R52, R70, R74: 270; R_Axial_DIN0204_L3.6mm_D1.6mm_P2.54mm_Vertical
R53, R56, R58, R87: 68; R_Axial_DIN0204_L3.6mm_D1.6mm_P2.54mm_Vertical
R55, R80, R89: 47k; R_Axial_DIN0204_L3.6mm_D1.6mm_P2.54mm_Vertical
R59, R61, R63: 12k; R_Axial_DIN0204_L3.6mm_D1.6mm_P2.54mm_Vertical
R60, R62, R64, R77: 4.7k; R_Axial_DIN0204_L3.6mm_D1.6mm_P2.54mm_Vertical
R65: 1; R_Axial_DIN0204_L3.6mm_D1.6mm_P2.54mm_Vertical
R71, R72, R76, R79, R83, R88: 2k; R_Axial_DIN0204_L3.6mm_D1.6mm_P2.54mm_Vertical
R75, R86: 20k; R_Axial_DIN0204_L3.6mm_D1.6mm_P2.54mm_Vertical
R81: 2.4k; R_Axial_DIN0204_L3.6mm_D1.6mm_P2.54mm_Vertical
R85: 8.2k; R_Axial_DIN0204_L3.6mm_D1.6mm_P2.54mm_Vertical
R90, R93: 1.2k; R_Axial_DIN0204_L3.6mm_D1.6mm_P2.54mm_Vertical
R91: 1.5k; R_Axial_DIN0204_L3.6mm_D1.6mm_P2.54mm_Vertical
R92: 5.6k; R_Axial_DIN0204_L3.6mm_D1.6mm_P2.54mm_Vertical
R94: 82; R_Axial_DIN0204_L3.6mm_D1.6mm_P2.54mm_Vertical
RN1, RN2, RN3: 10k; R_Array_SIP9
RN4: 1.5k; R_Array_SIP9
RV1: 47k; Potentiometer_Runtron_RM-063_Horizontal
SW1: SW_SPST; Molex_KK-254_AE-6410-02A_1x02_P2.54mm_Vertical
SW2, SW3: WF-2; Molex_KK-254_AE-6410-02A_1x02_P2.54mm_Vertical
U1: 74HCU04; DIP-14_W7.62mm_Socket
U2: MAX314CSE/DG413DY; SOIC-16_3.9x9.9mm_P1.27mm
U3: 74HC04; SOIC-14_3.9x8.7mm_P1.27mm
U4: 74HC4050; SOIC-16_3.9x9.9mm_P1.27mm
U5: LM311N; DIP-8_W7.62mm_Socket
U6: K78L05-1000R3; TO-220-3_Horizontal_TabDown
U7: Z84C0010PEC; DIP-40_W15.24mm_Socket
U8: AMS1117-3.3; SOT-223-3_TabPin2
U9: SST39SF040; DIP-32_W15.24mm_Socket
U10: EPM3256ATC144-10; TQFP-144_20x20mm_P0.5mm
U11: AS6C4008-55PCN; DIP-32_W15.24mm_Socket
U12: MB8877A; DIP-40_W15.24mm_Socket
U13: AY-3-8910; DIP-40_W15.24mm_Socket
Y1: 14.318MHz; Crystal_HC49-U_Vertical
Y2: 32MHz; Crystal_HC49-U_Vertical

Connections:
+3V3: C2.2, C3.2, C4.2, C5.2, C6.2, C7.2, C8.2, C9.2, C10.2, C11.2, C12.2, C13.2, C35.1, J5.4, J15.4 (VDD), R17.2, R18.2, R66.1, R67.1, R68.1, R69.1, U8.2 (VO), U10.24 (VCCIO), U10.50 (VCCIO), U10.51 (VCCINT), U10.58 (VCCINT), U10.73 (VCCIO), U10.76 (VCCIO), U10.95 (VCCIO), U10.115 (VCCIO), U10.123 (VCCINT), U10.130 (VCCINT), U10.144 (VCCIO)
+5V: C14.2, C15.2, C16.2, C17.2, C18.2, C19.2, C20.2, C21.2, C22.2, C23.1, C24.1, C25.2, C30.1, C34.2, J4.4, J6.7, J7.7, J10.2, J13.A3 (Pin_a3), J14.10, JP1.1, JP2.1, JP4.1 (A), Q2.3 (C), Q3.3 (C), Q5.3 (C), Q6.3 (C), Q7.3 (C), Q8.3 (C), R2.1, R3.1, R4.1, R6.1, R8.1, R9.1, R20.2, R24.1, R27.1, R75.2, R90.1, RN1.1 (common), RN2.1 (common), RN3.1 (common), RN4.1 (common), U1.14 (VCC), U2.12 (VL), U2.13 (V+), U3.14 (VCC), U4.1 (VCC), U5.8 (V+), U6.3 (OUT), U7.11 (VCC), U8.3 (VI), U9.32 (VCC), U11.22 (~CE), U11.32 (VCC), U12.21 (VCC+5), U12.22 (~TEST), U13.25 (A8), U13.28 (BC2), U13.40 (VCC)
+12V: C1.2, C29.2, C32.1, D5.1 (K), D6.2 (A), J4.1, J13.B22 (Pin_b22), LS1.1, Q1.3 (S), U6.1 (IN), U12.40 (VCC+12)
/<: R50.2, U10.53 (IO)
/>: J13.A13 (Pin_a13), R50.1, U10.54 (IO)
/A0: J13.A9 (Pin_a9), R28.1, U7.30 (A0), U9.12 (A0), U10.44 (IO)
/A1: J13.A10 (Pin_a10), R29.1, U7.31 (A1), U9.11 (A1), U10.45 (IO)
/A2: J13.A11 (Pin_a11), R30.1, U7.32 (A2), U9.10 (A2)
/A3: J13.A12 (Pin_a12), R31.1, U7.33 (A3), U9.9 (A3)
/A4: J13.A24 (Pin_a24), R32.1, U7.34 (A4), U9.8 (A4)
/A5: J13.A23 (Pin_a23), R33.1, U7.35 (A5), U9.7 (A5), U12.5 (A0)
/A6: J13.A22 (Pin_a22), R34.1, U7.36 (A6), U9.6 (A6)
/A7: J13.A21 (Pin_a21), R35.1, U7.37 (A7), U9.5 (A7)
/A8: D1.1 (K), J13.B26 (Pin_b26), R36.1, U7.38 (A8), U9.27 (A8), U12.6 (A1)
/A9: D2.1 (K), J13.A27 (Pin_a27), R37.1, U7.39 (A9), U9.26 (A9)
/A10: D3.1 (K), J13.B27 (Pin_b27), R38.1, U7.40 (A10), U9.23 (A10)
/A11: D4.1 (K), J13.A28 (Pin_a28), R39.1, U7.1 (A11), U9.25 (A11)
/A12: D7.1 (K), J13.A2 (Pin_a2), R40.1, U7.2 (A12), U9.4 (A12)
/A13: D8.1 (K), J13.B2 (Pin_b2), R41.1, U7.3 (A13), U9.28 (A13)
/A14: D9.1 (K), J13.A1 (Pin_a1), U7.4 (A14), U10.46 (IO)
/A15: D10.1 (K), J13.B1 (Pin_b1), U7.5 (A15), U10.48 (IO)
/AY_ABC: U2.1, U2.8, U2.9, U2.16, U10.43 (IO)
/AY_BC1: U10.41 (IO), U13.29 (BC1)
/AY_BDIR: U10.42 (IO), U13.27 (BDIR)
/AY_CLK: U10.49 (IO), U13.22 (CLOCK)
/BEEPER: R14.1, U10.56 (IO)
/Blue: J8.5, R51.1, R73.1, U10.74 (IO)
/Bright: J8.2, J8.6, J8.7, R59.1, R61.1, R63.1, R85.1, U10.70 (IO)
/CHROMA0: R92.1, U10.117 (IO)
/CHROMA1: R91.1, U10.118 (IO)
/CLK14: U1.2, U10.128 (IN/OE2/GCLK2)
/CLK32: U1.4, U10.125 (IN/GCLK1)
/CLKCPU: RN3.6 (R5), U1.9, U7.6 (~CLK~), U10.134 (IO)
/Csync: D11.1 (K), Q6.1 (B), U10.75 (IO)
/D0: J13.B6 (Pin_b6), R42.1, RN1.2 (R1), U7.14 (D0), U9.13 (D0), U12.7 (D0), U13.37 (DA0)
/D1: J13.B7 (Pin_b7), R43.1, RN1.3 (R2), U7.15 (D1), U9.14 (D1), U12.8 (D1), U13.36 (DA1)
/D2: J13.B8 (Pin_b8), R44.1, RN1.4 (R3), U7.12 (D2), U9.15 (D2), U12.9 (D2), U13.35 (DA2)
/D3: J13.B11 (Pin_b11), R45.1, RN1.5 (R4), U7.8 (D3), U9.17 (D3), U12.10 (D3), U13.34 (DA3)
/D4: J13.B12 (Pin_b12), R46.1, RN1.6 (R5), U7.7 (D4), U9.18 (D4), U12.11 (D4), U13.33 (DA4)
/D5: J13.B10 (Pin_b10), R47.1, RN1.7 (R6), U7.9 (D5), U9.19 (D5), U12.12 (D5), U13.32 (DA5)
/D6: J13.B9 (Pin_b9), R48.1, RN1.8 (R7), U7.10 (D6), U9.20 (D6), U12.13 (D6), U13.31 (DA6)
/D7: J13.B3 (Pin_b3), R49.1, RN1.9 (R8), U7.13 (D7), U9.21 (D7), U12.14 (D7), U13.30 (DA7)
/FD_CLK: U10.93 (IO), U12.24 (CLC)
/FD_CS: U10.78 (IO), U12.3 (~CS)
/FD_DDEN: U10.106 (IO), U12.37 (~DDEN)
/FD_DIR: U3.3, U12.16 (DIRC)
/FD_DISK0: J9.10 (~DS0), U4.2
/FD_DISK0_0: U4.3, U10.92 (IO)
/FD_DISK1: J9.12 (~DS1), RN4.5 (R4), U4.10
/FD_DISK1_0: U4.9, U10.86 (IO)
/FD_DRQ: RN4.7 (R6), U10.103 (IO), U12.38 (DRQ)
/FD_HLT: U10.90 (IO), U12.23 (HRDY)
/FD_INDEX: J9.8 (~INDEX), RN4.2 (R1), U4.7
/FD_INDEX0: U4.6, U10.91 (IO)
/FD_INDEX1: U10.107 (IO), U12.35 (~IP)
/FD_INTRQ: RN4.8 (R7), U10.102 (IO), U12.39 (INTRQ)
/FD_MOTOR: U3.13, U10.98 (IO), U12.28 (HLD), U12.32 (CPRDY)
/FD_RAWR: U10.97 (IO), U12.27 (~RAWR)
/FD_RDAT: J9.30 (~RDATA), RN4.9 (R8), U4.14
/FD_RDAT_0: U4.15, U10.84 (IO)
/FD_RST: U10.83 (IO), U12.19 (~CLR)
/FD_S: U10.96 (IO), U12.26 (S)
/FD_SIDE: U3.9, U10.88 (IO)
/FD_SL: U10.81 (IO), U12.17 (SL)
/FD_SR: U10.82 (IO), U12.18 (SR)
/FD_STEP: U3.1, U12.15 (STEP)
/FD_TR00: J9.26 (~TRK00), RN4.3 (R2), U4.5
/FD_TR00_0: U4.4, U12.34 (~TRO0)
/FD_TR43: U10.99 (IO), U12.29 (TR43)
/FD_WD: U10.100 (IO), U12.31 (WD)
/FD_WDAT: U3.5, U10.87 (IO)
/FD_WF_DE: RN4.6 (R5), U10.101 (IO), U12.33 (WF/DE)
/FD_WPT: J9.28 (~WPT), RN4.4 (R3), U4.11
/FD_WPT0: U4.12, U12.36 (~WPRT)
/FD_WSTB: U3.11, U12.30 (WSTB)
/Green: J8.4, R57.1, R81.1, U10.71 (IO)
/Hsync: J8.8, U10.80 (IO)
/KA8: D1.2 (A), J3.6
/KA9: D2.2 (A), J3.3
/KA10: D3.2 (A), J3.2
/KA11: D4.2 (A), J3.1
/KA12: D7.2 (A), J3.4
/KA13: D8.2 (A), J3.5
/KA14: D9.2 (A), J3.7
/KA15: D10.2 (A), J3.8
/KD0: J1.1, R9.2, U10.116 (IO)
/KD1: J1.2, R8.2, U10.113 (IO)
/KD2: J1.3, R6.2, U10.121 (IO)
/KD3: J1.4, R4.2, U10.120 (IO)
/KD4: J1.5, R3.2, U10.119 (IO)
/RA14: U9.29 (A14), U10.19 (IO)
/RA15: U9.3 (A15), U10.21 (IO)
/RA16: U9.2 (A16), U10.22 (IO)
/Red: J8.3, R54.1, R77.1, U10.72 (IO)
/SD_CD: J15.9 (CD), R66.2, U10.108 (IO)
/SD_CS: J15.2 (DAT3/CS), U10.111 (IO)
/SD_MISO: J15.7 (DAT0), R68.2, U10.109 (IO)
/SD_MOSI: J15.3 (CMD), U10.112 (IO)
/SD_SCK: J15.5 (CLK), U10.110 (IO)
/SND_DAC: R52.1, U10.61 (IO)
/SND_L: C41.2, J10.8, J11.T, R80.2
/SND_MONO: C40.2, J10.6
/SND_R: C42.2, J10.9, J11.R, R89.2
/TAPE_IN: C26.2, J12.R
/TAPE_IN0: RN2.9 (R8), U5.7, U10.55 (IO)
/TAPE_OUT: C31.1, J12.T
/TAPE_OUT0: R11.1, U10.60 (IO)
/TCK: J5.1, R19.2, U10.89 (TCK)
/TDI: J5.9, R17.1, U10.4 (TDI)
/TDO: J5.3, U10.104 (TDO)
/TMS: J5.5, R18.1, U10.20 (TMS)
/VA0: R28.2, U10.9 (IO), U11.3 (A14)
/VA1: R29.2, U10.10 (IO), U11.4 (A12)
/VA2: R30.2, U10.141 (IO), U11.23 (A10)
/VA3: R31.2, U10.143 (IO), U11.25 (A11)
/VA4: R32.2, U10.1 (IO), U11.26 (A9)
/VA5: R33.2, U10.2 (IO), U11.27 (A8)
/VA6: R34.2, U10.5 (IO), U11.28 (A13)
/VA7: R35.2, U10.8 (IO), U11.31 (A15)
/VA8: R36.2, U10.18 (IO), U11.10 (A2)
/VA9: R37.2, U10.16 (IO), U11.9 (A3)
/VA10: R38.2, U10.15 (IO), U11.8 (A4)
/VA11: R39.2, U10.14 (IO), U11.7 (A5)
/VA12: R40.2, U10.12 (IO), U11.6 (A6)
/VA13: R41.2, U10.11 (IO), U11.5 (A7)
/VA14: U10.31 (IO), U11.12 (A0)
/VA15: U10.30 (IO), U11.11 (A1)
/VA16: U10.25 (IO), U11.2 (A16)
/VA17: U10.23 (IO), U11.1 (A18)
/VA18: U10.7 (IO), U11.30 (A17)
/VD0: R42.2, U10.32 (IO), U11.13 (D0)
/VD1: R43.2, U10.140 (IO), U11.21 (D7)
/VD2: R44.2, U10.37 (IO), U11.14 (D1)
/VD3: R45.2, U10.139 (IO), U11.20 (D6)
/VD4: R46.2, U10.38 (IO), U11.15 (D2)
/VD5: R47.2, U10.138 (IO), U11.19 (D5)
/VD6: R48.2, U10.40 (IO), U11.17 (D3)
/VD7: R49.2, U10.39 (IO), U11.18 (D4)
/VID_B: J10.1, R53.2
/VID_COMP: C43.1, J10.4, R87.2
/VID_G: J10.3, R58.2
/VID_R: J10.7, R56.2
/VID_SYNC: J10.5, R70.2
/Vsync: J8.9, U10.79 (IO)
/~BUSACK: J13.A26 (Pin_a26), U7.23 (~BUSACK~)
/~BUSRQ: J13.A19 (Pin_a19), RN3.9 (R8), U7.25 (~BUSRQ~)
/~CLKCPU: J13.A8 (Pin_a8), U1.8
/~HALT: J13.B15 (Pin_b15), U7.18 (~HALT~)
/~INT: J13.B13 (Pin_b13), RN3.4 (R3), U7.16 (~INT~), U10.36 (IO)
/~IORQ: J13.B17 (Pin_b17), U7.20 (~IORQ~), U10.29 (IO)
/~JOY_B1: J6.6, J7.6, RN2.7 (R6), U10.63 (IO)
/~JOY_B2: J6.9, J7.9, RN2.2 (R1), U10.69 (IO)
/~JOY_B3: J6.5, J7.5, RN2.3 (R2), U10.68 (IO)
/~JOY_DOWN: J6.2, J7.2, RN2.6 (R5), U10.65 (IO)
/~JOY_LEFT: J6.3, J7.3, RN2.5 (R4), U10.66 (IO)
/~JOY_RIGHT: J6.4, J7.4, RN2.4 (R3), U10.67 (IO)
/~JOY_UP: J6.1, J7.1, RN2.8 (R7), U10.62 (IO)
/~M1: J13.B24 (Pin_b24), U7.27 (~M1~), U10.34 (IO)
/~MREQ: J13.B16 (Pin_b16), U7.19 (~MREQ~), U10.28 (IO)
/~NMI: J13.B14 (Pin_b14), RN3.5 (R4), U7.17 (~NMI~), U10.35 (IO)
/~RD: J13.B18 (Pin_b18), U7.21 (~RD~), U9.24 (~OE), U10.137 (IO), U12.4 (~RD)
/~RFSH: J13.B25 (Pin_b25), U7.28 (~RFSH~), U10.27 (IO)
/~ROMCS: J13.A25 (Pin_a25), R23.1, U9.22 (~CE)
/~ROMCS0: R23.2, U10.122 (IO)
/~RSTCPU: J13.A20 (Pin_a20), U7.26 (~RESET~), U10.47 (IO), U13.23 (~RESET~)
/~VRD: U10.142 (IO), U11.24 (~OE)
/~VWR: U10.6 (IO), U11.29 (~WE)
/~WAIT: J13.B21 (Pin_b21), RN3.8 (R7), U7.24 (~WAIT~)
/~WR: J13.B19 (Pin_b19), JP3.2, U7.22 (~WR~), U10.136 (IO), U12.2 (~WR)
GND: C1.1, C2.1, C3.1, C4.1, C5.1, C6.1, C7.1, C8.1, C9.1, C10.1, C11.1, C12.1, C13.1, C14.1, C15.1, C16.1, C17.1, C18.1, C19.1, C20.1, C21.1, C22.1, C23.2, C24.2, C25.1, C27.1, C28.1, C29.1, C30.2, C32.2, C33.1, C34.1, C35.2, C36.1, C37.1, C38.1, C39.1, C44.2, J2.2, J2.3, J4.2, J4.3, J5.2, J5.10, J6.8, J6.10, J7.0 (PAD), J7.8, J8.1, J9.1 (GND), J9.3 (GND), J9.5 (GND), J9.7 (GND), J9.9 (GND), J9.11 (GND), J9.13 (GND), J9.15 (GND), J9.17 (GND), J9.19 (GND), J9.21 (GND), J9.23 (GND), J9.25 (GND), J9.27 (GND), J9.29 (GND), J9.31 (GND), J9.33 (GND), J10.0, J11.S, J12.S, J13.A6 (Pin_a6), J13.A7 (Pin_a7), J13.A14 (Pin_a14), J14.1, J15.6 (VSS), J15.10 (SHIELD), R10.1, R12.1, R13.1, R19.1, R22.2, R25.1, R26.1, R60.1, R62.1, R64.1, R65.2, R74.1, R80.1, R86.1, R89.1, R93.1, R94.2, SW2.1, SW3.1, U1.7 (GND), U2.4 (V-), U2.5 (GND), U3.7 (GND), U4.8 (VSS), U5.1 (GND), U5.4 (V-), U6.2 (GND), U7.29 (GND), U8.1 (GND), U9.16 (GND), U10.3 (GNDIO), U10.13 (GNDIO), U10.17 (GNDIO), U10.26 (GNDIO), U10.33 (GNDIO), U10.52 (GNDINT), U10.57 (GNDINT), U10.59 (GNDIO), U10.64 (GNDIO), U10.77 (GNDIO), U10.85 (GNDIO), U10.94 (GNDIO), U10.105 (GNDIO), U10.114 (GNDIO), U10.124 (GNDINT), U10.129 (GNDINT), U10.135 (GNDIO), U11.16 (GND), U12.20 (VSS), U13.1 (VSS), U13.24 (~A9~)
unnamed: C26.1, R5.1, U5.3 (-)
unnamed: C27.2, R1.2, U1.13, Y1.1
unnamed: C28.2, R7.2, Y1.2
unnamed: C31.2, C33.2, R11.2, R14.2
unnamed: C36.2, R15.2, U1.5, Y2.1
unnamed: C37.2, R16.2, Y2.2
unnamed: C39.2, R52.2, R76.2, R88.2
unnamed: C40.1, Q4.1 (B), R55.2, R71.1, R72.1
unnamed: C41.1, R71.2, R76.1, R78.2, R79.2
unnamed: C42.1, R72.2, R83.2, R84.2, R88.1
unnamed: C43.2, Q8.2 (E), R94.1
unnamed: C44.1, Q8.1 (B), R90.2, R91.2, R92.2, R93.2
unnamed: D5.2 (A), Q1.1 (G), R12.2
unnamed: D6.1 (K), R13.2
unnamed: D11.2 (A), Q7.1 (B), R75.1, R82.2, R86.2
unnamed: J2.1, SW1.1 (A)
unnamed: J8.10, JP4.2 (B)
unnamed: J9.16 (~MTRON), U3.12
unnamed: J9.18 (~DIR), U3.4
unnamed: J9.20 (~STEP), U3.2
unnamed: J9.22 (~WDATE), U3.6
unnamed: J9.24 (~WGATE), U3.10
unnamed: J9.32 (~SIDE1), U3.8
unnamed: J14.2, U13.21 (IOA0)
unnamed: J14.3, U13.20 (IOA1)
unnamed: J14.4, U13.19 (IOA2)
unnamed: J14.5, U13.18 (IOA3)
unnamed: J14.6, U13.17 (IOA4)
unnamed: J14.7, U13.16 (IOA5)
unnamed: J14.8, U13.15 (IOA6)
unnamed: J14.9, U13.14 (IOA7)
unnamed: J15.1 (DAT2), R69.2
unnamed: J15.8 (DAT1), R67.2
unnamed: JP1.2, R25.2, U9.1 (A18)
unnamed: JP2.2, R26.2, U9.30 (A17)
unnamed: JP3.1, R27.2, U9.31 (~WE)
unnamed: LS1.2, RV1.1
unnamed: Q1.2 (D), SW1.2 (B)
unnamed: Q2.1 (B), R51.2, R63.2, R64.2
unnamed: Q2.2 (E), R53.1
unnamed: Q3.1 (B), R54.2, R61.2, R62.2
unnamed: Q3.2 (E), R56.1
unnamed: Q4.2 (E), R65.1
unnamed: Q4.3 (C), R55.1, RV1.2
unnamed: Q5.1 (B), R57.2, R59.2, R60.2
unnamed: Q5.2 (E), R58.1
unnamed: Q6.2 (E), R70.1, R74.2
unnamed: Q7.2 (E), R87.1
unnamed: R1.1, R7.1, U1.1, U1.12
unnamed: R2.2, R5.2, R10.2, U5.2 (+)
unnamed: R15.1, R16.1, U1.3, U1.6
unnamed: R21.2, SW2.2
unnamed: R73.2, R77.2, R81.2, R82.1, R85.2
unnamed: R78.1, U13.3 (A)
unnamed: R79.1, R83.1, U2.6, U2.14
unnamed: R84.1, U2.3, U2.11
unnamed: U2.7, U2.10, U13.4 (B)
unnamed: U2.2, U2.15, U13.38 (C)
~MAGIC: R24.2, SW3.2, U10.126 (IN/OE1)
~RST: C38.2, R20.1, R21.1, R22.1, U10.127 (IN/GCLRn)

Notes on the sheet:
SOUND
CLOCK
CPU
POWER
connect to VCC for DIP28
MEMORY
CPLD
BETA DISK INTERFACE
ANALOG VIDEO OUTPUT
KEYBOARD & JOYSTICK
TAPE INTERFACE
SD CARD
0 - ACB 1 - ABC
PORTS

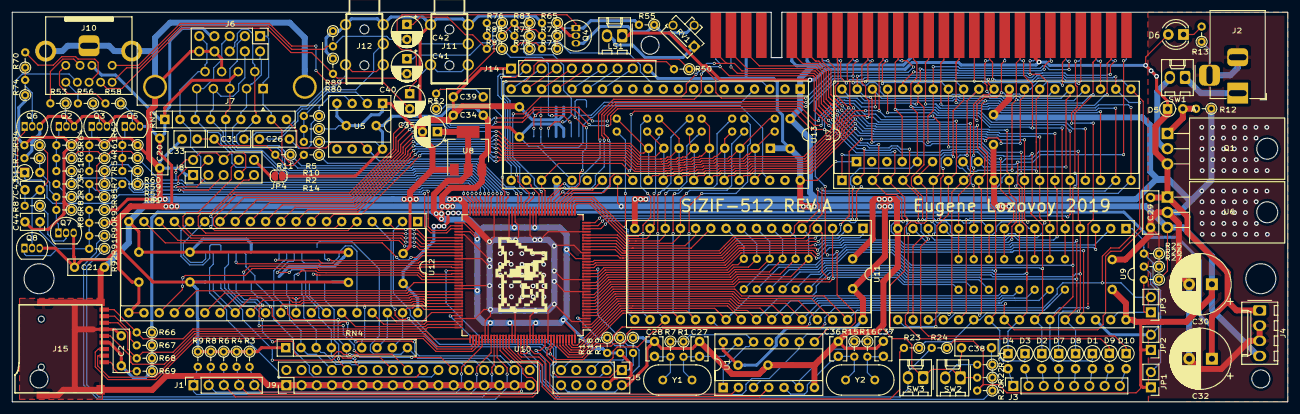
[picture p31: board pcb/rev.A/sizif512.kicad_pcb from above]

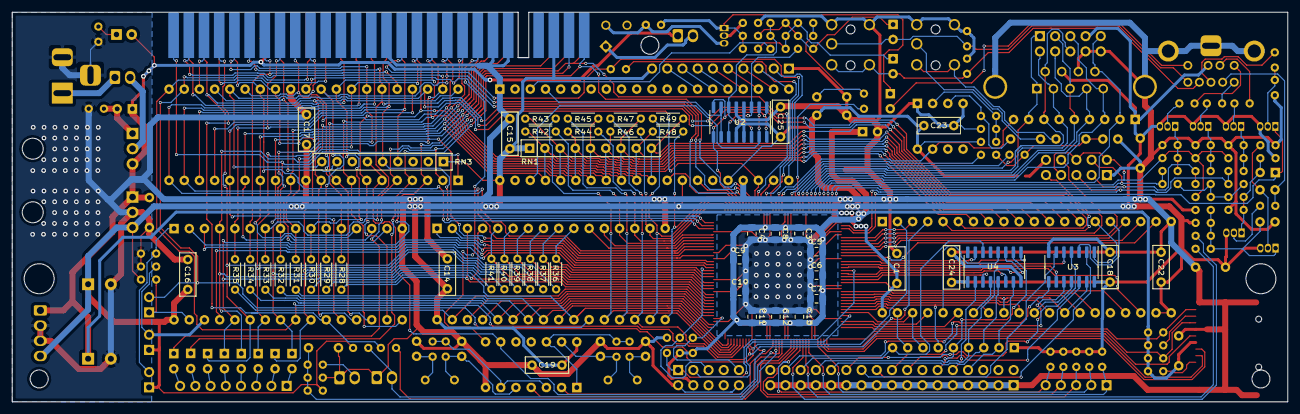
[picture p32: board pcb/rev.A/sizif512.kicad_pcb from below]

Board: 2 copper layers, 213.0 x 65.1 mm, 206 parts (49 on the bottom side), 230 nets.

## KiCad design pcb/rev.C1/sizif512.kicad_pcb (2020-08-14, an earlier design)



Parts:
C1: 15n; C_Disc_D5.0mm_W2.5mm_P2.50mm
C2: 470u/25V; CP_Radial_D10.0mm_P5.00mm
C3, C7, C24, C25, C26, C27, C28, C29, C30, C32, C33, C34, C37, C38, C39, C49, C50: 100n; C_Disc_D5.0mm_W2.5mm_P2.50mm
C4, C6, C31: 220u/16V; CP_Radial_D8.0mm_P3.50mm
C5, C8, C9, C10, C11, C12, C13, C14, C15, C16, C17, C19, C20, C21, C22, C23: 100n; C_0805_2012Metric_Pad1.15x1.40mm_HandSolder
C18: 10n; C_0805_2012Metric_Pad1.15x1.40mm_HandSolder
C35, C36: 22p; C_Disc_D3.8mm_W2.6mm_P2.50mm
C40: 220u/16V; CP_Radial_D6.3mm_P2.50mm
C41, C42: 4.7n; C_Disc_D5.0mm_W2.5mm_P2.50mm
C43: 30p; C_Trim_D6.3mm_P5.50mm
C44, C45, C46, C48: 10u/16V; CP_Radial_D5.0mm_P2.00mm
C47: 1u; CP_Radial_D5.0mm_P2.00mm
D1: LED; LED_D4.0mm
D2: 2W10; Diode_Bridge_Round_D10.0mm
D3: 1N5820; D_DO-201AD_P5.08mm_Vertical_AnodeUp
D4, D5, D6, D7, D8, D9, D10, D11, D12, D13, D14: BAT85; D_DO-35_SOD27_P2.54mm_Vertical_AnodeUp
H1, H2: MountingHole; MountingHole_5mm
H3, H4, H5: MountingHole; MountingHole_3mm
J1: DS-210; BarrelJack_Horizontal
J2: Conn_02x28_Row_Letter_First; ZX_EDGE
J3: PinHeader; PinHeader_1x05_P2.54mm_Vertical
J4: DS1020-08; FFC_FPC_1x08
J5: DS1020-05; FFC_FPC_1x05
J6, J8, J11: PinHeader; PinHeader_2x05_P2.54mm_Vertical
J7: DB9-M; DSUB-9_Male_Horizontal_P2.77x2.84mm_EdgePinOffset4.94mm_Hou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
J9: Mini-DIN-9; minidin-9
J10: RCJ-014; CUI_RCJ-01X-WIDE
J12, J15: PJ-313
J13: PinHeader; PinHeader_1x10_P2.54mm_Vertical
J14, J17: PinHeader; PinHeader_2x01_P2.54mm_Vertical
J16: MEM2055-00-190-01-A; GCT-MEM2055-00-190-01-A
JP2, JP3, JP4: Jumper; PinHeader_1x02_P2.54mm_Vertical
JP5: SolderJumper_2_Open; SolderJumper-2_P1.3mm_Open_RoundedPad1.0x1.5mm
JP6: Jumper_3_Bridged12; SolderJumper-3_P1.3mm_Bridged12_RoundedPad1.0x1.5mm_NumberL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
L1: 68uH/2A; L_Radial_D8.7mm_P5.00mm_Fastron_07HCP
L2: 68uH/2A; L_12x12mm_H8mm
L3: 220u/0.2A; L_Radial_D8.7mm_P5.00mm_Fastron_07HCP
LOGO1: graphic; black-mage2
LOGO2: Logo_Open_Hardware_Small; OSHW-Symbol_6.7x6mm_SilkScreen
LS1: PinHeader; PinHeader_1x02_P2.54mm_Vertical
Q1, Q2, Q3, Q4: BC549B; TO-92_Inline
R1, R12, R20, R25: 3k; R_Axial_DIN0207_L6.3mm_D2.5mm_P2.54mm_Vertical
R2, R48, R53: 1k; R_Axial_DIN0207_L6.3mm_D2.5mm_P2.54mm_Vertical
R3: 470; R_Axial_DIN0207_L6.3mm_D2.5mm_P2.54mm_Vertical
R4, R8: 470; R_Axial_DIN0207_L6.3mm_D2.5mm_P7.62mm_Horizontal
R5, R13, R14, R18: 10k; R_Axial_DIN0207_L6.3mm_D2.5mm_P7.62mm_Horizontal
R6, R7, R41, R42: 2k; R_Axial_DIN0207_L6.3mm_D2.5mm_P7.62mm_Horizontal
R9, R11, R23: 270; R_Axial_DIN0207_L6.3mm_D2.5mm_P2.54mm_Vertical
R10, R17, R22, R26, R27, R28: 1.5k; R_Axial_DIN0207_L6.3mm_D2.5mm_P2.54mm_Vertical
R15, R52: 1M; R_Axial_DIN0207_L6.3mm_D2.5mm_P2.54mm_Vertical
R16, R19, R21, R24, R29, R30: 68; R_Axial_DIN0207_L6.3mm_D2.5mm_P2.54mm_Vertical
R31, R34, R35, R36: 75; R_Axial_DIN0207_L6.3mm_D2.5mm_P2.54mm_Vertical
R37, R38, R39, R40, R43, R44: 1k; R_Axial_DIN0207_L6.3mm_D2.5mm_P7.62mm_Horizontal
R45, R46: 4.7k; R_Axial_DIN0207_L6.3mm_D2.5mm_P7.62mm_Horizontal
R47, R50, R51, R54, R55: 10k; R_Axial_DIN0207_L6.3mm_D2.5mm_P2.54mm_Vertical
R49: 100k; R_Axial_DIN0207_L6.3mm_D2.5mm_P2.54mm_Vertical
RN1, RN2, RN3: 10k; R_Array_SIP9
RV1: RM063 47k; Potentiometer_Runtron_RM-063_Horizontal
SW1: Jumper; Molex_KK-254_AE-6410-02A_1x02_P2.54mm_Vertical
SW2, SW3: Button THT; SW_Tactile_SPST_Angled_PTS645Vx83-2LFS
TP1, TP2, TP3, TP4, TP5, TP6, TP7, TP8: TestPoint; TestPoint_Pad_D1.0mm
U1: LM2596T-ADJ; TO-220-263-5_Horizontal_TabDown
U2: AMS1117-3.3; SOT-223-3_TabPin2
U3, U5, U7, U10: SN74CB3T3245PW; TSSOP-20_4.4x6.5mm_P0.65mm
U4: Z84C0010PEC; DIP-40_W15.24mm_Socket
U6: EPM1270T144; LQFP-144_20x20mm_P0.5mm
U8: SST39SF040; DIP-32_W15.24mm_Socket
U9: 74HCU04; DIP-14_W7.62mm_Socket
U11: AD724; SOIC-16W_7.5x10.3mm_P1.27mm
U12: AS6C4008-55PCN; DIP-32_W15.24mm_Socket
U13: 74HCT4053D; SOIC-16_3.9x9.9mm_P1.27mm
U14: AY-3-8910; DIP-40_W15.24mm_Socket
U15: LM311N; DIP-8_W7.62mm_Socket
Y1: 28 MHz; Crystal_HC49-U_Vertical
Y2: 4.433 MHz; Crystal_HC49-U_Vertical

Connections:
+3V3: C6.1, C7.2, C8.1, C9.1, C10.1, C11.1, C12.1, C13.1, C14.1, C15.1, C16.1, C17.1, C18.1, C19.1, C20.1, C21.1, C22.1, C23.1, C24.2, C25.2, D11.1 (K), J6.4, J7.7, J11.4, J16.4 (VDD), R47.2, R49.1, RN2.1 (common), RN3.1 (common), U2.2 (VO), U3.20 (VCC), U5.20 (VCC), U6.9 (VCCIO1), U6.19 (VCCINT), U6.25 (VCCIO1), U6.46 (VCCIO4), U6.56 (VCCINT), U6.64 (VCCIO4), U6.82 (VCCIO3), U6.90 (VCCINT), U6.100 (VCCIO3), U6.116 (VCCIO2), U6.126 (VCCINT), U6.136 (VCCIO2), U7.20 (VCC), U9.14 (VCC), U10.20 (VCC), U12.32 (VCC)
+5V: C1.1, C4.1, C5.2, C26.2, C27.2, C28.2, C29.2, C30.2, D1.2 (A), J2.A3 (Pin_a3), J3.5, J9.2, J13.10, JP2.2, JP3.2, JP5.1 (A), L1.2, L2.2, L3.1, R1.1, R6.1, R7.2, R18.1, R48.1, RN1.1 (common), U2.3 (VI), U4.11 (VCC), U8.32 (VCC), U13.16 (VDD), U14.25 (A8), U14.28 (BC2), U14.40 (VCC), U15.8 (V+)
+5VA: C31.1, C32.2, C33.2, C34.2, JP6.3 (B), L3.2, Q1.1 (C), Q2.1 (C), Q3.1 (C), Q4.1 (C), U11.4 (AVCC), U11.5 (CE), U11.14 (DVCC), U11.15 (VSYNC)
+9V: J2.A4 (Pin_a4), J3.3
+12V: J2.B22 (Pin_b22), J3.1
/A0: J2.A9 (Pin_a9), U4.30 (A0), U7.18 (B0), U8.12 (A0)
/A1: J2.A10 (Pin_a10), U4.31 (A1), U7.17 (B1), U8.11 (A1)
/A2: J2.A11 (Pin_a11), U4.32 (A2), U7.16 (B2), U8.10 (A2)
/A3: J2.A12 (Pin_a12), U4.33 (A3), U7.15 (B3), U8.9 (A3)
/A4: J2.A24 (Pin_a24), U4.34 (A4), U7.14 (B4), U8.8 (A4)
/A5: J2.A23 (Pin_a23), U4.35 (A5), U8.7 (A5), U10.12 (B6)
/A6: J2.A22 (Pin_a22), U4.36 (A6), U7.13 (B5), U8.6 (A6)
/A7: J2.A21 (Pin_a21), U4.37 (A7), U7.12 (B6), U8.5 (A7)
/A8: D4.1 (K), J2.B26 (Pin_b26), U4.38 (A8), U5.13 (B5), U8.27 (A8)
/A9: D5.1 (K), J2.A27 (Pin_a27), U4.39 (A9), U5.12 (B6), U8.26 (A9)
/A10: D6.1 (K), J2.B27 (Pin_b27), U3.18 (B0), U4.40 (A10), U8.23 (A10)
/A11: D7.1 (K), J2.A28 (Pin_a28), U4.1 (A11), U5.11 (B7), U8.25 (A11)
/A12: D8.1 (K), J2.A2 (Pin_a2), U4.2 (A12), U7.11 (B7), U8.4 (A12)
/A13: D9.1 (K), J2.B2 (Pin_b2), U4.3 (A13), U8.28 (A13), U10.17 (B1)
/A14: D10.1 (K), J2.A1 (Pin_a1), U3.11 (B7), U4.4 (A14)
/A15: D12.1 (K), J2.B1 (Pin_b1), U3.13 (B5), U4.5 (A15)
/AY_ABC: U6.78 (IO3_78), U13.9 (C), U13.10 (B)
/AY_BC1: U6.86 (IO3_86), U14.29 (BC1)
/AY_BDIR: U6.89 (IO3_89/GCLK2), U14.27 (BDIR)
/AY_CLK: U6.88 (IO3_88), U14.22 (CLOCK)
/AY_MONO: U6.79 (IO3_79), U13.11 (A)
/Blue0: J8.8, R25.1, U6.102 (IO3_102)
/Blue1: J8.1, R22.1, U6.108 (IO3_108)
/CLK28: U6.18 (IO1_18/GCLK0), U9.10
/CLKCPU: R6.2, U4.6 (~CLK~), U10.16 (B2)
/Csync: Q1.2 (B), U6.98 (IO3_98), U11.16 (HSYNC)
/D0: J2.B6 (Pin_b6), U4.14 (D0), U8.13 (D0), U10.13 (B5), U14.37 (DA0)
/D1: J2.B7 (Pin_b7), U4.15 (D1), U8.14 (D1), U10.14 (B4), U14.36 (DA1)
/D2: J2.B8 (Pin_b8), U4.12 (D2), U8.15 (D2), U10.15 (B3), U14.35 (DA2)
/D3: J2.B11 (Pin_b11), U3.12 (B6), U4.8 (D3), U8.17 (D3), U14.34 (DA3)
/D4: J2.B12 (Pin_b12), U3.14 (B4), U4.7 (D4), U8.18 (D4), U14.33 (DA4)
/D5: J2.B10 (Pin_b10), U3.15 (B3), U4.9 (D5), U8.19 (D5), U14.32 (DA5)
/D6: J2.B9 (Pin_b9), U3.16 (B2), U4.10 (D6), U8.20 (D6), U14.31 (DA6)
/D7: J2.B3 (Pin_b3), U3.17 (B1), U4.13 (D7), U8.21 (D7), U14.30 (DA7)
/Green0: J8.9, R20.1, U6.101 (IO3_101)
/Green1: J8.2, R17.1, U6.107 (IO3_107)
/Hsync: J8.7, U6.103 (IO3_103)
/KA8: D4.2 (A), J4.6
/KA9: D5.2 (A), J4.3
/KA10: D6.2 (A), J4.2
/KA11: D7.2 (A), J4.1
/KA12: D8.2 (A), J4.4
/KA13: D9.2 (A), J4.5
/KA14: D10.2 (A), J4.7
/KA15: D12.2 (A), J4.8
/KD0: J5.1, RN2.6 (R5), U6.4 (IO1_4)
/KD1: J5.2, RN2.5 (R4), U6.5 (IO1_5)
/KD2: J5.3, RN2.4 (R3), U6.11 (IO1_11)
/KD3: J5.4, RN2.3 (R2), U6.8 (IO1_8)
/KD4: J5.5, RN2.2 (R1), U6.7 (IO1_7)
/RA14: U6.30 (IO1_30), U8.29 (A14)
/RA15: U6.29 (IO1_29), U8.3 (A15)
/RA16: U6.28 (IO1_28), U8.2 (A16)
/RX: C49.2, J15.T, R54.1
/Red0: J8.4, R12.1, U6.105 (IO3_105)
/Red1: J8.3, R10.1, U6.106 (IO3_106)
/SD_CD: J16.9 (CD), R47.1, U6.12 (IO1_12)
/SD_CS: J16.2 (DAT3/CS), U6.3 (IO1_3)
/SD_DAT1: J16.8 (DAT1), RN2.9 (R8)
/SD_DAT2: J16.1 (DAT2), RN2.7 (R6)
/SD_MISO: J16.7 (DAT0), RN2.8 (R7), U6.125 (IO2_125)
/SD_MOSI: J16.3 (CMD), U6.129 (IO2_129)
/SD_SCK: J16.5 (CLK), U6.127 (IO2_127)
/SND_DAC_L: R38.2, U6.84 (IO3_84)
/SND_DAC_R: R37.2, U6.85 (IO3_85)
/SND_L: C44.2, J9.8, J12.T
/SND_MONO: C46.2, J9.6
/SND_R: C45.2, J9.9, J12.R
/TAPE_IN0: RN3.9 (R8), U6.80 (IO3_80), U15.7
/TCK: J11.1, U6.35 (TCK)
/TDI: J11.9, U6.34 (TDI)
/TDO: J11.3, U6.36 (TDO)
/TMS: J11.5, U6.33 (TMS)
/TX: J15.R, R55.1
/VA0: U6.143 (IO2_143), U12.12 (A0)
/VA1: U6.142 (IO2_142), U12.11 (A1)
/VA2: U6.141 (IO2_141), U12.10 (A2)
/VA3: U6.140 (IO2_140), U12.9 (A3)
/VA4: U6.139 (IO2_139), U12.8 (A4)
/VA5: U6.138 (IO2_138), U12.7 (A5)
/VA6: U6.137 (IO2_137), U12.6 (A6)
/VA7: U6.134 (IO2_134), U12.5 (A7)
/VA8: U6.120 (IO2_120), U12.27 (A8)
/VA9: U6.119 (IO2_119), U12.26 (A9)
/VA10: U6.114 (IO2_114), U12.23 (A10)
/VA11: U6.118 (IO2_118), U12.25 (A11)
/VA12: U6.133 (IO2_133), U12.4 (A12)
/VA13: U6.121 (IO2_121), U12.28 (A13)
/VA14: U6.132 (IO2_132), U12.3 (A14)
/VA15: U6.124 (IO2_124), U12.31 (A15)
/VA16: U6.131 (IO2_131), U12.2 (A16)
/VA17: U6.130 (IO2_130), U12.1 (A18)
/VA18: U6.123 (IO2_123), U12.30 (A17)
/VD0: U6.144 (IO2_144), U12.13 (D0)
/VD1: U6.1 (IO1_1), U12.14 (D1)
/VD2: U6.2 (IO1_2), U12.15 (D2)
/VD3: U6.109 (IO2_109), U12.17 (D3)
/VD4: U6.110 (IO2_110), U12.18 (D4)
/VD5: U6.111 (IO2_111), U12.19 (D5)
/VD6: U6.112 (IO2_112), U12.20 (D6)
/VD7: U6.113 (IO2_113), U12.21 (D7)
/VID_B: J9.1, R29.2
/VID_COMP: J9.4, J10.1 (In), R31.2
/VID_G: J9.3, R21.2
/VID_R: J9.7, R16.2
/VID_SYNC: J9.5, R9.2
/Vsync: J8.6, U6.104 (IO3_104)
/xA0: U6.63 (IO4_63), U7.2 (A0)
/xA1: U6.62 (IO4_62), U7.3 (A1)
/xA2: U6.60 (IO4_60/DEV_OE), U7.4 (A2)
/xA3: U6.59 (IO4_59), U7.5 (A3)
/xA4: U6.58 (IO4_58), U7.6 (A4)
/xA5: U6.67 (IO4_67), U10.8 (A6)
/xA6: U6.57 (IO4_57), U7.7 (A5)
/xA7: U6.55 (IO4_55), U7.8 (A6)
/xA8: U5.7 (A5), U6.45 (IO4_45)
/xA9: U5.8 (A6), U6.44 (IO4_44)
/xA10: U3.2 (A0), U6.42 (IO4_42)
/xA11: U5.9 (A7), U6.43 (IO4_43)
/xA12: U6.53 (IO4_53), U7.9 (A7)
/xA13: U6.72 (IO4_72), U10.3 (A1)
/xA14: U3.9 (A7), U6.31 (IO1_31)
/xA15: U3.7 (A5), U6.37 (IO4_37)
/xCLKCPU: U6.71 (IO4_71), U10.4 (A2)
/xD0: U6.68 (IO4_68), U10.7 (A5)
/xD1: U6.69 (IO4_69), U10.6 (A4)
/xD2: U6.70 (IO4_70), U10.5 (A3)
/xD3: U3.8 (A6), U6.32 (IO1_32)
/xD4: U3.6 (A4), U6.38 (IO4_38)
/xD5: U3.5 (A3), U6.39 (IO4_39)
/xD6: U3.4 (A2), U6.40 (IO4_40)
/xD7: U3.3 (A1), U6.41 (IO4_41)
/~BUSACK: J2.A26 (Pin_a26), U4.23 (~BUSACK~)
/~BUSRQ: J2.A19 (Pin_a19), RN1.9 (R8), U4.25 (~BUSRQ~)
/~CLKCPU: J2.A8 (Pin_a8), R7.1, U10.18 (B0)
/~HALT: J2.B15 (Pin_b15), U4.18 (~HALT~)
/~INT: J2.B13 (Pin_b13), U4.16 (~INT~), U6.77 (IO3_77)
/~IORQ: J2.B17 (Pin_b17), R4.2, U4.20 (~IORQ~)
/~IORQGE: J2.A13 (Pin_a13), R4.1, U10.11 (B7)
/~JOY_B1: J6.2, J7.6, RN3.7 (R6), U6.91 (IO3_91/GCLK3)
/~JOY_B2: J6.8, J7.9, RN3.3 (R2), U6.96 (IO3_96)
/~JOY_B3: J6.9, J7.5, RN3.2 (R1), U6.97 (IO3_97)
/~JOY_DOWN: J6.3, J7.2, RN3.6 (R5), U6.93 (IO3_93)
/~JOY_LEFT: J6.5, J7.3, RN3.5 (R4), U6.94 (IO3_94)
/~JOY_RIGHT: J6.7, J7.4, RN3.4 (R3), U6.95 (IO3_95)
/~JOY_UP: J6.1, J7.1, RN3.8 (R7), U6.87 (IO3_87)
/~M1: J2.B24 (Pin_b24), U4.27 (~M1~), U5.14 (B4)
/~MREQ: J2.B16 (Pin_b16), U4.19 (~MREQ~), U5.18 (B0)
/~NMI: J2.B14 (Pin_b14), U4.17 (~NMI~), U6.76 (IO3_76)
/~RD: J2.B18 (Pin_b18), RN1.7 (R6), U4.21 (~RD~), U5.15 (B3), U8.24 (~OE)
/~RFSH: J2.B25 (Pin_b25), U4.28 (~RFSH~), U5.17 (B1)
/~ROMCS: D11.2 (A), R8.2, U6.27 (IO1_27)
/~ROMCSB: J2.A25 (Pin_a25), R8.1, U8.22 (~CE)
/~RSTCPU: J2.A20 (Pin_a20), R5.1, U4.26 (~RESET~), U6.75 (IO3_75), U14.23 (~RESET~)
/~VRD: U6.117 (IO2_117), U12.24 (~OE)
/~VWR: U6.122 (IO2_122), U12.29 (~WE)
/~WAIT: J2.B21 (Pin_b21), RN1.8 (R7), U4.24 (~WAIT~)
/~WR: J2.B19 (Pin_b19), JP4.1, U4.22 (~WR~), U5.16 (B2)
/~xCLKCPU_IO73: U6.73 (IO3_73), U10.2 (A0)
/~xIORQGE: U6.66 (IO4_66), U10.9 (A7)
/~xM1: U5.6 (A4), U6.48 (IO4_48)
/~xMREQ: U5.2 (A0), U6.52 (IO4_52)
/~xRD: U5.5 (A3), U6.49 (IO4_49)
/~xRFSH: U5.3 (A1), U6.51 (IO4_51)
/~xWR: U5.4 (A2), U6.50 (IO4_50)
GND: C2.2, C3.2, C4.2, C5.1, C6.2, C7.1, C8.2, C9.2, C10.2, C11.2, C12.2, C13.2, C14.2, C15.2, C16.2, C17.2, C18.2, C19.2, C20.2, C21.2, C22.2, C23.2, C24.1, C25.1, C26.1, C27.1, C28.1, C29.1, C30.1, C31.2, C32.1, C33.1, C34.1, C35.1, C36.1, C41.2, C42.2, C43.2, C50.1, D2.1 (-), D3.2 (A), D13.2 (A), D14.2 (A), J2.A6 (Pin_a6), J2.A7 (Pin_a7), J2.A14 (Pin_a14), J3.4, J6.6, J6.10, J7.0 (PAD), J7.8, J8.5, J9.0, J10.2 (Ext), J11.2, J11.10, J12.S, J13.1, J14.2, J15.S, J16.6 (VSS), J16.10 (SHIELD), J17.2, JP6.1 (A), LS1.2, R2.1, R3.2, R5.2, R11.2, R13.1, R14.1, R26.1, R27.1, R28.1, R34.1, R35.1, R36.1, R43.2, R44.2, R52.1, R53.1, RV1.3, SW2.1, SW3.1, U1.3 (GND), U1.5 (~ON~/OFF), U2.1 (GND), U3.10 (GND), U3.19 (~OE), U4.29 (GND), U5.10 (GND), U5.19 (~OE), U6.10 (GNDIO), U6.17 (GNDINT), U6.26 (GNDIO), U6.47 (GNDIO), U6.54 (GNDINT), U6.65 (GNDIO), U6.83 (GNDIO), U6.92 (GNDINT), U6.99 (GNDIO), U6.115 (GNDIO), U6.128 (GNDINT), U6.135 (GNDIO), U7.10 (GND), U7.19 (~OE), U8.16 (GND), U9.5, U9.7 (GND), U9.9, U10.10 (GND), U10.19 (~OE), U11.2 (AGND), U11.12 (TRAP), U11.13 (DGND), U12.16 (GND), U12.22 (~CE), U13.6 (INH), U13.7 (VEE), U13.8 (VSS), U14.1 (VSS), U14.24 (~A9~), U15.1 (GND), U15.4 (V-), Y2.2
unnamed: C1.2, R1.2, R2.2, U1.4 (FB)
unnamed: C2.1, C3.1, D2.3 (+), U1.1 (VIN)
unnamed: C35.2, R15.2, U9.13, Y1.2
unnamed: C36.2, R23.2, Y1.1
unnamed: C37.1, R19.1, R36.2
unnamed: C37.2, U11.6 (RED)
unnamed: C38.1, R24.1, R35.2
unnamed: C38.2, U11.7 (GREEN)
unnamed: C39.1, R30.1, R34.2
unnamed: C39.2, U11.8 (BLUE)
unnamed: C40.1, U11.10 (COMP_OUT)
unnamed: C40.2, R31.1
unnamed: C41.1, C44.1, R38.1, R39.1, R42.1, R44.1, R46.1, U13.14 (X)
unnamed: C42.1, C45.1, R37.1, R40.1, R41.1, R43.1, R45.1, U13.13 (X1)
unnamed: C43.1, U11.3 (XTAL), Y2.1
unnamed: C46.1, R45.2, R46.2, RV1.2
unnamed: C47.1, RV1.1
unnamed: C47.2, R51.1, U9.1
unnamed: C48.1, U9.4
unnamed: C48.2, LS1.1
unnamed: C49.1, R50.1, R52.2, U15.3 (-)
unnamed: D1.1 (K), R3.1
unnamed: D2.2 (~~), J1.2, J1.3
unnamed: D3.1 (K), L1.1, L2.1, U1.2 (OUT)
unnamed: D13.1 (K), J13.7, R54.2, U14.16 (IOA5)
unnamed: D14.1 (K), J13.3, R55.2, U14.20 (IOA1)
unnamed: J1.1, SW1.1 (A)
unnamed: J8.10, JP5.2 (B)
unnamed: J13.2, U14.21 (IOA0)
unnamed: J13.4, U14.19 (IOA2)
unnamed: J13.5, U14.18 (IOA3)
unnamed: J13.6, U14.17 (IOA4)
unnamed: J13.8, U14.15 (IOA6)
unnamed: J13.9, U14.14 (IOA7)
unnamed: JP2.1, R13.2, U8.1 (A18)
unnamed: JP3.1, R14.2, U8.30 (A17)
unnamed: JP4.2, R18.2, U8.31 (~WE)
unnamed: JP6.2 (C), U11.1 (NTSC/PAL)
unnamed: Q1.3 (E), R9.1, R11.1
unnamed: Q2.2 (B), R10.2, R12.2, R28.2
unnamed: Q2.3 (E), R16.1, R19.2
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

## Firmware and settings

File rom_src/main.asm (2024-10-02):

    ASSERT __SJASMPLUS__ >= 0x011402 ; SjASMPlus 1.20.2
    OPT --syntax=abf
    OPT -Wno-out0
    DEVICE ZXSPECTRUM48

; Startup handler
    ORG #0000
    ex de, hl ; EB opcode used by CPLD to determine magic ROM presence
    ex de, hl ; ...
    jp startup_handler
    DB 0,"Sizif Magic ROM",0

; NMI handler
    ORG #0066
    ex de, hl ; EB opcode used by CPLD to determine magic ROM presence
    ex de, hl ; ...
    jp nmi_handler

; INT IM1 handler
    ORG #0038
    push bc
    ld bc, #0038
    ld (var_int_vector), bc
    pop bc
    ret

; INT IM2 handler
    ORG #0101
    ret

; INT IM2 vector table
    ORG #0200
    .257 db #01 ; by Z80 user manual int vector is I * 256 + (D & 0xFE)
                ; but by other references and by T80/A-Z80 implementation int vector is I * 256 + D
                ; so we just play safe and use symmetric int handler address and vector table with one extra byte


    ORG #0570   ; this address chosen to do not overlap with divmmc entrypoints
startup_handler:
    ld sp, Stack_top
    ld ix, #5800    ; draw 4 rygb boxes on left top corner to indicate boot
    ld (ix+0), #D2  ; r
    ld (ix+1), #F6  ; y
    call check_initialized
    jr z, .warm_boot
    im 1            ; wait for ps/2 keyboard ready
    ld b, POWERON_DELAY ; ...
.loop               ; ...
    ei              ; ...
    halt            ; ...
    djnz .loop      ; ...
    call init_default_config
    call load_user_config
    call detect_cpu
    call detect_sd_card
    call detect_ext_board
    call detect_external_ay
    call detect_external_bdi
    call detect_external_kempston
    call check_custom_rom
.warm_boot:
    xor a
    ld (cfg_saved.fastforward), a
    call load_config
    call init_cpld
    call save_initialized
    call mute_saa1099  ; saa1099 does not have reset pin
    ld ix, #5800    ; draw 4 rygb boxes on left top corner to indicate boot
    ld (ix+2), #E4  ; g
    ld (ix+3), #C9  ; b
    ld hl, 0
    jp exit_with_jp


nmi_handler:
    ld (var_sp_reg), sp
    ld sp, Stack_top
    push af
    push hl
    push bc
    ld a, 1                   ; show magic border
    ld bc, #01ff              ; ...
    out (c), a                ; ...
    xor a
    ld (var_magic_enter_cnt), a
    ld (var_magic_leave_cnt), a
.key_wait_loop:
    xor a                     ;
    in a, (#ff)               ;
    bit 2, a                  ; A[2] == 1 if fastforward button is pressed
    jr nz, .enter_fastforward ; ...
    bit 1, a                  ; A[1] == 1 if pause button is pressed
    jr nz, .enter_pause       ; ...
    call delay_10ms           ;
    call check_entering_menu  ; A == 1 if we are entering menu, A == 2 if we are leaving to...
    cp 1                      ; ...default nmi handler, A == 0 otherwise
    jr z, .enter_menu         ; ...
    cp 2                      ; ...
    jr nz, .key_wait_loop     ; ...
.leave_no_key:
    xor a                     ; disable border
    ld bc, #01ff              ; ...
    out (c), a                ; ...
    ld bc, #00ff              ; ...
    in a, (c)                 ; if divmmc paged - just do retn
    bit 3, a                  ; ...
    jp nz, exit_with_ret      ; ...
    ld hl, #0066              ; otherwise jump to default nmi handler
    jp exit_with_jp           ; ...

.enter_fastforward:
    ld hl, nmi_fastforward
    ld (var_main_fun), hl
    jr .enter
.enter_pause:
    ld hl, nmi_pause
    ld (var_main_fun), hl
    jr .enter
.enter_menu:
    ld hl, nmi_menu
    ld (var_main_fun), hl
    ;jr .enter
.enter:
    push de
    push ix
    push iy
    ld a, i                   ; save I reg and IFF2
    push af                   ; ...
    ld a, #02                 ; set our IM2 interrupt table address (#02xx)
    ld i, a                   ; ...
    xor a
    ld (var_exit_flag), a
    ld (var_exit_reboot), a
    call input_init
    call save
.run_fun:
    ld hl, .leave             ; place ret address to stack
    push hl                   ; ...
    ld hl, (var_main_fun)     ; jump to our loop function
    jp (hl)                   ; ...
.leave:
    call save_config
    call restore
    ld a, (var_exit_reboot)   ; should we reboot?
    or a                      ; ...
    jr z, .leave_without_reboot ; ...
    ld a, 2                   ; reboot
    ld bc, #01ff              ; ...
    out (c), a                ; ...
.leave_without_reboot:
    pop af                    ; A = I
    push af                   ;
    call get_im2_handler      ; HL = default im2 handler address
    ld (var_int_vector), hl
    xor a                     ; disable border
    ld bc, #01ff              ; ...
    out (c), a                ; ...
    pop af
    pop iy
    pop ix
    pop de
    ei                        ; wait for int just for safety
    halt                      ; ...
    ld i, a                   ; restore default interrupt table address
    jp po, exit_with_ret      ; check int was enabled by default. no? just do retn
    ld hl, (var_int_vector)   ; ...
    jp exit_with_jp           ; yes? goto default int handler


; IN  - HL - jump address
exit_with_jp:
    ld (Exit_vector-1), hl
    ld a, #c3                ; c3 - jp
    ld (Exit_vector-2), a
    pop bc
    pop hl
    pop af
    ld sp, (var_sp_reg)
    jp Exit_vector-2

exit_with_ret:
    ld hl, #45ed             ; ed45 - retn; reverse bytes order
    ld (Exit_vector-1), hl
    pop bc
    pop hl
    pop af
    ld sp, (var_sp_reg)
    jp Exit_vector-1


check_initialized:
    ld hl, cfg_initialized     ; if (cfg_initialized == "magic word") Z = 0, else Z = 1
.check:
    ld a, #B1                  ; ...
    cpi                        ; ... hl++
    ret nz                     ; ...
    ld a, #5B                  ; ...
    cpi                        ; ... hl++
    ret nz                     ; ...
    ld a, #00                  ; ...
    cpi                        ; ... hl++
    ret nz                     ; ...
    ld a, #B5                  ; ...
    cpi                        ; ... hl++
    ret

save_initialized:
    ld hl, #5BB1               ; cfg_initialized = "magic word"
    ld (cfg_initialized+0), hl ; ...
    ld hl, #B500               ; ...
    ld (cfg_initialized+2), hl ; ...
    ret

init_default_config:
    ld bc, CFG_T+CFGEXT_T ; cfg_saved = cfg_default
    ld de, cfg_saved      ; ...
    ld hl, CFG_DEFAULT    ; ...
    ldir                  ; ...

load_config:
    ld bc, CFG_T+CFGEXT_T ; cfg = cfg_saved
    ld de, cfg            ; ...
    ld hl, cfg_saved      ; ...
    ldir                  ; ...
    ret                   ; ...

save_config:
    ld bc, CFG_T+CFGEXT_T ; cfg_saved = cfg
    ld de, cfg_saved      ; ...
    ld hl, cfg            ; ...
    ldir                  ; ...
    ret


load_user_config:
    ld hl, user_config_initialized ; check if magic world is written to flash
    call check_initialized.check   ; if no - do not do anything
    ret nz                         ; ...
    ld bc, CFG_T+CFGEXT_T          ; else - cfg_saved = user_config
    ld de, cfg_saved               ; ...
    ld hl, user_config             ; ...
    ldir                           ; ...
.quirks:                           ; some options shouldn't be saved by user, so we just overwrite them from default config
    ld a, (CFG_DEFAULT.ay)         ; AY should be disabled only by detect_external_ay
    ld (cfg_saved.ay), a           ; ...
    ld a, (CFG_DEFAULT.fastforward)
    ld (cfg_saved.fastforward), a
    ret

; OUT -  A = 1 if error, 0 if ok
save_user_config:
    call flash_is_supported        ; if flash isnt supported - set error flag and exit
    jr z, .support_check_passed    ; ...
    ld a, 1                        ; ...
    ld (var_flash_error), a        ; ...
    ret                            ; ...
.support_check_passed:
    ld iy, user_config_sector      ; erase
    call flash_erase_sector        ; ...
    ld ix, cfg                     ; program config to flash
    ld iy, user_config             ; ...
    ld b, CFG_T+CFGEXT_T           ; ...
    call flash_program             ; ...
    ld ix, cfg_initialized         ; program magic word to flash
    ld iy, user_config_initialized ; ...
    ld b, 4                        ; ...
    call flash_program             ; ...
    xor a                          ; clear error flag
    ld (var_flash_error), a        ; ...
    ret


init_cpld:
.check_alt48rom:
    ld a, (cfg.rom48)           ; if alternative 48k rom enabled - disable 128 menu
    or a                        ; ... this is required because 128 menu isn't compatible
    jr z, .check_7ffd_disabled  ; ... with currently used Looking Glass 48K rom
    ld a, (cfg.machine)         ; ... however +3e works with looking glass flawlessly
    cp 2                        ; ...
    jr z, .check_7ffd_disabled  ; ...
    ld a, #10                   ; ...
    ld bc, #7ffd                ; ...
    out (c), a                  ; ...
.check_7ffd_disabled:
    ld a, (cfg.machine)         ; if machine == 48 - set 7ffd rom to basic48
    or a                        ; ... this is required for case when machine will be
    jr nz, .check_1ffd_disabled ; ... changed later by magic menu - this prevents
    ld a, #10                   ; ... hang if user changes machine while basic48 active
    ld bc, #7ffd                ; ...
    out (c), a                  ; ...
.check_1ffd_disabled:
    ld a, (cfg.machine)         ; if machine != +3 - set 1ffd rom to basic48
    cp 2                        ; ... this is required for case when +3 will be
    jr z, .do_load              ; ... activated later by magic menu - this prevents
    ld a, #4                    ; ... hang if user activate +3 while basic48 active
    ld bc, #1ffd                ; ...
    out (c), a                  ; ...
.do_load:
    ld b, CFG_T                 ; B = registers count
    ld c, #ff                   ;
    ld hl, cfg+CFG_T-1          ; HL = &cfg[registers count-1]
    otdr                        ; do { b--; out(bc, *hl); hl--; } while(b)
.do_load_ext:                   ; same for extension board
    ld d, CFGEXT_T              ; ...
    ld bc, #e1ff                ; ...
    ld hl, cfgext               ; ...
.do_load_ext_loop:              ; ...
    ld a, (hl)                  ; ...
    out (c), a                  ; ...
    inc hl                      ; ...
    inc b                       ; ...
    dec d                       ; ...
    jr nz, .do_load_ext_loop    ; ...
    ret                         ;


detect_cpu:
    ld bc, #12ff                ;
    out (c), 0                  ; on NMOS Z80 0x00 will be written, on CMOS Z80 - 0xFF
    ld b, 0                     ;
    in a, (c)                   ; port #00FF bit 4 contains value we wrote
    and #10                     ;
    jr z, .nmos                 ;
.cmos:
    ld a, 1                     ;
    ld (cfg_saved.cmoscpu), a   ;
    ret                         ;
.nmos:
    ld (cfg_saved.cmoscpu), a   ;
    ld a, (cfg_saved.clock)     ; if clock >= 14MHz then clock = 7MHz
    cp 4                        ; ...
    ret c                       ; ...
    ld a, 3                     ; ...
    ld (cfg_saved.clock), a     ; ...
    ret                         ;


detect_sd_card:
    in a, (#77)                 ; read sd_cd state from ZC status port
    bit 0, a                    ; check sd_cd == 0 (card is insert)
    ret z                       ; yes?
.no_card:
    ld a, (cfg_saved.sd)        ; if (sd == divmmc) sd = OFF
    cp 1                        ; ...
    ret nz                      ; ...
    xor a                       ; sd = OFF
    ld (cfg_saved.sd), a        ; ...
    ret


; OUT -  A = 1 if ext board present, 0 otherwise
; OUT -  F - garbage
; OUT - BC - garbage
detect_ext_board:
    ld bc, #e0ff    ; read port #e0ff
    in a, (c)       ; ...
    ld b, a         ; if (result & 0xF0 != 0) - return
    and #f0         ; ...
    jr z, .detected ; ...
.not_detected:
    xor a
    ld (var_ext_presence), a
    ret
.detected:
    ld a, 1
    ld (var_ext_presence), a
    xor a
.cfg_tsfm:
    bit 0, b     ; check TSFM jumper
    jr nz, .cfg_saa
    ld (cfgext_saved.tsfm), a
.cfg_saa:
    bit 1, b     ; check SAA jumper
    jr nz, .cfg_gs
    ld (cfgext_saved.saa), a
.cfg_gs:
    bit 2, b     ; check GS jumper
    ret nz
    ld (cfgext_saved.gs), a
    ret


; Check if external AY addon is connected to zx bus
; If yes - disable internal AY and TSFM on extension board
detect_external_ay:
    ld bc, #08ff    ; disable main AY
    xor a           ; ...
    out (c), a      ; ...
    ld b, #e1       ; disable extension board's AY
    out (c), a      ; ...
    ld bc, #fffd    ; set AY register = R6
    ld a, 6         ; ...
    out (c), a      ; ...
    ld b, #bf       ; write some value to register
    out (c), a      ; ...
    ld b, #ff       ; read back this value
    in a, (c)       ; ...
    cp 6                      ; if read and written values are same - disable internal AY
    ret nz                    ; ...
    xor a                     ; ...
    ld (cfg_saved.ay), a      ; ...
    ld (cfgext_saved.tsfm), a ; ...
    ret


; Check if external BDI (TR-DOS) addon is connected to zx-bus
; If yes - set SD to ZC mode
detect_external_bdi:
    ld a, #10                ; BDI entry points is inactive if basic128 is selected
    ld bc, #7ffd             ; ... so we choose basic48
    out (c), a               ; ...
    ld a, #c9                ; write RET opcode to 5cc2
    ld hl, #5cc2             ; ...
    ld (hl), a               ; ...
    call .sub                ; do tr-dos call
    cp #42                   ; if there is no tr-dos then our #3d2f handler will be called, which sets a = #42
    ld a, #0                 ; revert to default #7ffd state
    out (c), a               ; ...
    ret z                    ; if a == #42 (no tr-dos) - just exit
.reconfig:                   ; ... otherwise disable esxdos
    ld a, (cfg_saved.sd)     ; if (sd != off) sd = zc
    or a                     ; ...
    ret z                    ; ...
    ld a, 2                  ; ...
    ld (cfg_saved.sd), a     ; ...
    ret
.sub:
    push hl                  ; call tr-dos rom procedure, which just does ret to HL
    jp trdos_3d2f_entrypoint ; ...


; Check if Kempston joystick addon is connected to zx-bus
; If yes - set internal joystick to Sinclair mode
detect_external_kempston:
    ld a, 1                      ; disable internal Kempston
    ld bc, #07ff                 ; ...
    out (c), a                   ; ...
    xor a                        ;
    in a, (#1f)                  ; read kempston joystick port
    cp #ff                       ; if value == 0xff - assume no addon connected
    ret z                        ; ...
    ld a, 1                      ; otherwise - change internal joystick mode to Sinclair
    ld (cfg_saved.joystick), a   ; ...
    ret                          ;


; Check if user holds CS key on poweron. If true - boot with custom rom
check_custom_rom:
    ld a, #fe                    ; read cs,z,x,c,v
    in a, (#fe)                  ; ...
    bit 0, a                     ; check CS is pressed
    jr nz, .check_custom_rom     ; ... skip menu if no
.show_menu:
    ld a, 1                      ; show magic border
    ld bc, #01ff                 ; ...
    out (c), a                   ; ...
    call bootmenu                ; ... else show boot menu
.check_custom_rom:
    ld a, (cfg_saved.custom_rom) ; which rom was choosen?
    or a                         ; ... do nothing if default
    ret z                        ; ...
.custom_rom_boot:
    xor a                        ; else - disable ula+
    ld (cfg_saved.ulaplus), a    ; ...
    ld a, (cfg_saved.sd)         ; if (sd != off) sd = zc
    or a                         ; ...
    ret z                        ; ...
    ld a, 2                      ; ...
    ld (cfg_saved.sd), a         ; ...
    ret


; OUT -  A = 1 if we are entering menu, A = 2 if we are leaving menu, A = 0 otherwise
; OUT -  F - garbage
check_entering_menu:
    xor a                       ; read magic key state in bit 0 of #00FF port
    in a, (#ff)                 ; ...
    bit 0, a                    ; check key is hold
    jr nz, .is_hold             ; yes?
.not_hold:
    ld a, (var_magic_leave_cnt) ; leave_counter++
    inc a                       ; ...
    ld (var_magic_leave_cnt), a ; ...
    cp MENU_LEAVE_DELAY         ; if (counter == MENU_LEAVE_DELAY) - return 2
    jr nz, .return0             ; ...
    ld a, 2
    ret
.is_hold:
    ld a, (var_magic_enter_cnt) ; enter_counter++
    inc a                       ; ...
    ld (var_magic_enter_cnt), a ; ...
    cp MENU_ENTER_DELAY         ; if (counter == MENU_ENTER_DELAY) - return 1
    jr nz, .return0             ; ...
    ld a, 1
    ret
.return0:
    xor a
    ret


; OUT - AF - garbage
; OUT - BC - garbage
delay_10ms:
    ld c, 7*4
    ld a, (cfg.fastforward)
    or a
    jr nz, .loop
    ld c, 7
    ld a, (cfg.clock)
    or a
    jr z, .loop
    ld c, 9
    dec a
    jr z, .loop
    ld c, 11
    dec a
    jr z, .loop
    ld c, 7*2
    dec a
    jr z, .loop
    ld c, 7*4
.loop:
    ld a, c
.loop_outer:
    ld b, 255                 ; ~1ms cycle at 3.5MHz
.loop_inner:                  ; ...
    djnz .loop_inner          ; 13 T-states
    dec a
    jr nz, .loop_outer
    ret


; read non-magic im2 table and returns im2 handler address
; IN  -  A - im2 table address hight byte
; OUT - HL - handler address
; OUT - AF - garbage
get_im2_handler:
    ld h, a                   ; HL = im2 table address
    ld l, #ff                 ; HL = im2 table address
    ld a, #2a                 ; 2a - ld hl, (nn)
    ld (Readout_vector-2), a  ; ...
    ld (Readout_vector-1), hl ; HL was set earlier by im2 table address
    ld a, #c9                 ; c9 - ret
    ld (Readout_vector+1), a  ; ...
    call Readout_vector-2     ; HL = default im2 handler address
    ret


save:
.mute_gs:
    ld a, (var_ext_presence) ; if (no_ext_pcb || gs_is_disabled) - skip gs
    or a                     ; ...this is required to be compatible with DivIDE
    jr z, .mute_saa1099      ; ...which uses same port #bb
    ld a, (cfgext.gs)        ; ...
    or a                     ; ...
    jr z, .mute_saa1099      ; ...
    ld a, #fa                ; send command Out zero_to_zero
    out (#bb), a             ; ...
.mute_saa1099:
    call mute_saa1099
.save_ay:
    ld hl, var_save_ay ; select first AY chip in TurboSound
    ld a, #ff          ; ...
    call .save_ay_sub
    ld a, #fe          ; select second AY chip in TurboSound
    call .save_ay_sub
.save_screen:
    ld bc, 6912
    ld de, var_save_screen
    ld hl, #4000
    ldir
.save_ulaplus:
    ld bc, #bf3b       ; set ulaplus address = mode register
    ld a, #40          ; ...
    out (c), a         ; ...
    ld bc, #ff3b       ; save mode register value
    in a, (c)          ; ...
    bit 7, a             ; if bit 7 != 0 - assume no ulaplus there
    jr z, .save_ulaplus1 ; ... so save 0 (disabled) state
    xor a                ; ... for case when user will enable ulaplus in menu later
.save_ulaplus1:
    ld (var_save_ulaplus), a ; ...
    xor a              ; disable ulaplus
    out (c), a         ; ...
    ret

.save_ay_sub:
    ld bc, #fffd       ; ...
    out (c), a         ; ...
    ld d, 16           ; register_number=16
.save_ay_sub_loop:
    dec d              ; register_number--
    ld b, #ff          ; select register number
    out (c), d         ; ...
    in a, (c)          ; read register
    ld (hl), a         ; save to ram
    xor a              ; set register to 0
    ld b, #bf          ; ...
    out (c), a         ; ...
    inc hl             ; ram++
    or d               ; register_number == 0?
    jr nz, .save_ay_sub_loop
    ret

mute_saa1099:
    ld bc, #ffff       ; select saa register
    ld a, #1c          ; ...
    out (c), a         ; ...
    ld b, #fe          ; mute
    xor a              ; ...
    out (c), a         ; ...
    ret


restore:
.restore_ulaplus:
    ld bc, #bf3b       ; set ulaplus address = mode register
    ld a, #40          ; ...
    out (c), a         ; ...
    ld bc, #ff3b       ; restore mode register value
    ld a, (var_save_ulaplus) ; ...
    out (c), a         ; ...
.restore_screen:
    call restore_screen
.restore_ay:
    ld hl, var_save_ay+16 ; select second AY chip in TurboSound
    ld a, #fe             ; ...
    call .restore_ay_sub
    ld hl, var_save_ay    ; select first AY chip in TurboSound
    ld a, #ff             ; ...
    call .restore_ay_sub
.restore_gs:
    ld a, (var_ext_presence) ; if (no_ext_pcb || gs_is_disabled) - skip gs
    or a                     ; ...this is required to be compatible with DivIDE
    jr z, .restore_ret       ; ...which uses same port #bb
    ld a, (cfgext.gs)        ; ...
    or a                     ; ...
    jr z, .restore_ret       ; ...
    ld a, #60                ; send command Get Song Position
    out (#bb), a             ; ...
.restore_ret:
    ret

.restore_ay_sub:
    ld bc, #fffd       ; ...
    out (c), a         ; ...
    ld d, 16           ; register_number=16
.restore_ay_sub_loop:
    dec d              ; register_number--
    ld b, #ff          ; select register number
    out (c), d         ; ...
    ld b, #bf          ; restore register
    ld a, (hl)         ; ...
    out (c), a         ; ...
    inc hl             ; ram++
    xor a              ; register_number == 0?
    or d               ; ...
    jr nz, .restore_ay_sub_loop ;
    ret

restore_screen:
    ld bc, 6912
    ld de, #4000
    ld hl, var_save_screen
    ldir
    ret


bootmenu:
    call input_init
    ld hl, menuboot
    call menu_init
    call menu_input_loop
    jp wait_for_keys_release


nmi_fastforward:
    ld a, (cfg.fastforward)
    xor 1
    ld (cfg.fastforward), a
    ld bc, #11ff
    out (c), a
    ei
    halt
    jp wait_for_keys_release
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

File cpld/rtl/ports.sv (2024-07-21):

import common::*;
module ports(
    input rst_n,
    input clk28,
    input en_kempston,
    input en_sinclair,

    cpu_bus bus,
    output [7:0] d_out,
    output d_out_active,

    input machine_t machine,
    input trdos,
    input port_ff_active,
    input [7:0] port_ff_data,
    input [4:0] kd,
    input [7:0] kempston_data,
    input magic_map,
    input tape_in,

    output reg tape_out,
    output reg beeper,
    output reg [2:0] border,
    output reg video_page,
    output reg rom_page128,
    output reg [2:0] ram_page128,
    output reg [2:0] ram_pageext,
    output reg [2:0] port_1ffd,
    output reg [4:0] port_dffd,

    output reg plus3_drd,
    output reg plus3_dwr,
    output reg plus3_mtr
);


/* PORT #FF */
reg port_ff_rd;
always @(posedge clk28 or negedge rst_n) begin
    if (!rst_n)
        port_ff_rd <= 0;
    else
        port_ff_rd <= bus.rd && bus.ioreq && !magic_map && !trdos && port_ff_active && (machine != MACHINE_S3) && bus.a[7:0] == 8'hFF;
end


/* PORT #FE */
wire port_fe_cs = bus.ioreq && bus.a[0] == 0;
reg port_fe_rd;
always @(posedge clk28 or negedge rst_n) begin
    if (!rst_n)
        port_fe_rd <= 0;
    else
        port_fe_rd <= port_fe_cs && bus.rd;
end

reg [4:0] kd0;
wire [7:0] port_fe_data = {1'b1, tape_in, 1'b1, kd0};
always @(posedge clk28 or negedge rst_n) begin
    if (!rst_n) begin
        beeper <= 0;
        tape_out <= 0;
        border <= 0;
    end
    else if (port_fe_cs && bus.wr) begin
        beeper <= bus.d[4];
        tape_out <= bus.d[3];
        border <= bus.d[2:0];
    end
end

always @(posedge clk28 or negedge rst_n) begin
    if (!rst_n) begin
        kd0 <= 5'b11111;
    end
    else if (en_sinclair) begin
        kd0 <= kd
            & (bus.a[12] == 0? {~kempston_data[1], ~kempston_data[0], ~kempston_data[2], ~kempston_data[3], ~kempston_data[4]} : 5'b11111) // 6-0 keys
            & (bus.a[15] == 0? {1'b1, ~kempston_data[6], ~kempston_data[5], 2'b11} : 5'b11111 ) ; // b-space keys
    end
    else begin
        kd0 <= kd;
    end
end


/* PORT #7FFD */
reg lock_7ffd;
wire port_7ffd_cs = bus.ioreq && bus.a[1] == 0 && bus.a[15] == 0 &&
                    (bus.a[14] == 1'b1 || (!magic_map && machine != MACHINE_S3)) &&
                    (machine != MACHINE_S48 || magic_map) &&
                    (lock_7ffd == 0 || port_dffd[4] == 1'b1);
always @(posedge clk28 or negedge rst_n) begin
    if (!rst_n) begin
        ram_page128 <= 0;
        video_page <= 0;
        rom_page128 <= 0;
        lock_7ffd <= 0;
    end
    else if (port_7ffd_cs && bus.wr) begin
        ram_page128 <= bus.d[2:0];
        video_page <= bus.d[3];
        rom_page128 <= bus.d[4];
        lock_7ffd <= bus.d[5];
    end
end


/* PORT #DFFD */
wire port_dffd_cs = bus.ioreq && bus.a == 16'hDFFD && (machine == MACHINE_PENT || magic_map);
always @(posedge clk28 or negedge rst_n) begin
    if (!rst_n) begin
        ram_pageext <= 0;
        port_dffd <= 0;
    end
    else if (port_dffd_cs && bus.wr) begin
        ram_pageext <= bus.d[2:0];
        port_dffd <= bus.d[4:0];
    end
end


/* PORT #1FFD */
wire port_1ffd_cs = bus.ioreq && bus.a[15:12] == 4'b0001 && !bus.a[1] &&
                    (machine == MACHINE_S3 || magic_map);
always @(posedge clk28 or negedge rst_n) begin
    if (!rst_n) begin
        port_1ffd <= 0;
        plus3_mtr <= 1'b1;
    end
    else if (port_1ffd_cs && bus.wr) begin
        port_1ffd <= bus.d[2:0];
        plus3_mtr <= bus.d[3]? 1'b0 : 1'b1;
    end
end


/* PORTS #2FFD & #3FFD (+3DOS) */
wire port_2ffd_3ffd_cs = bus.ioreq && bus.a[15:13] == 3'b001 && !bus.a[1] &&
                         (machine == MACHINE_S3);
always @(posedge clk28 or negedge rst_n) begin
    if (!rst_n) begin
        plus3_dwr <= 1'b1;
        plus3_drd <= 1'b1;
    end
    else begin
        plus3_drd <= (bus.rd && port_2ffd_3ffd_cs)? 1'b0 : 1'b1;
        plus3_dwr <= (bus.wr && port_2ffd_3ffd_cs)? 1'b0 : 1'b1;
    end
end


/* KEMPSTON */
reg kempston_rd;
always @(posedge clk28 or negedge rst_n) begin
    if (!rst_n)
        kempston_rd <= 0;
    else
        kempston_rd <= en_kempston && !trdos && bus.ioreq && bus.rd && bus.a[5:0] == 6'h1F;
end


/* BUS CONTROLLER */
assign d_out_active = port_fe_rd | port_ff_rd | kempston_rd;

assign d_out =
    kempston_rd? kempston_data :
    port_fe_rd? port_fe_data :
    port_ff_data ;


endmodule

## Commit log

2020-04-30 handle magic button
2020-05-01 add pcbs
    [sizif512-wifi.kicad_pcb, sizif512-wifi.sch, sizif512.kicad_pcb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]
2020-05-09 fix crash if magic button was pressed while esxdos active
2020-05-17 update rev.A pcb
    [sizif512.kicad_pcb, sizif512.sch]
2020-05-17 add rev.B (abandoned) and rev.C (wip) pcbs
    [sizif512-wifi.kicad_pcb, sizif512-wifi.sch, sizif512.kicad_pcb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]
2020-05-22 pcb rev.C: minor layout changes
    [sizif512.kicad_pcb, sizif512.sch]
2020-07-06 git: move wifi module to external repo
    [sizif512-wifi.kicad_pcb, sizif512-wifi.sch]
2020-07-06 [minor] update kicad project file
2020-07-06 [minor]: fix kicad project files
    [sizif512.kicad_pcb, sizif512.sch]
2020-07-06 add pcb rev.C1
    [sizif512.kicad_pcb, sizif512.sch]
2020-07-18 pcb rev.C1: minor values change
    Video circuit tuning:
    R10, R17, R22, R26, R27, R27: 1.5k
    R12, R20, R25: 3k
    C43: 30p (wider range is better)
    Q1, Q2, Q3, Q4: BC549B (low noise, less amplification)
    Exclude 2.2k value from BOM:
    R6, R7: 2k
    Also add some assembly drawing.
    [sizif512.kicad_pcb, sizif512.sch]
2020-07-21 pcb rev.C1: update Y1 capacitors values for better reliability
    [sizif512.kicad_pcb, sizif512.sch]
2020-08-14 git: fix crlf line endings in repository
    [sizif512.kicad_pcb, sizif512.sch]
2020-08-14 add switching between 48 alternative roms and between 128 / +3e roms
2020-08-14 update magic button handler
    + improve compatibility (furher testing needed)
    + play tone and flash border on key press
    + add keys for turbo14 mode, 48K timings, ay mono, +3 rom, alternative
    48 rom
    + add key to do jump to #0000 (useful for rom switching)
2020-08-18 add support for sega 3/6-button gamaped
    To use Sega gamepad with rev.C (C1) PCB it's required to swap traces to
    pins 5 and 7 to DB-9 port on PCB.
    Rev.D PCB will get Sega gamepad support by default.
2020-09-06 fix broken magic if magic button was hold during reset
2020-09-06 use x,y,z sega gamepad buttons as turbo a,b,c
2020-09-06 implement pause on press of sega gamepad "start" button
2020-09-06 treat mode button on sega gamepad as magic button
    This is useful for entering into Dr.Slump's NMI Navigator which have
    kempston joystick support.
2020-10-19 pcb: add rev.D 3d render
2020-11-18 cpld: add video output code for pcb rev.D
2021-02-27 git: add pcb/rev*~*/ to gitignore
2021-02-27 add pcb rev.D
    [sizif512.kicad_pcb, sizif512.sch]
2021-02-27 add pcb rev.D1
    [sizif512.kicad_pcb, sizif512.sch]
2021-02-27 update cpld firmware to support rev.D board
2021-02-27 add rev.D1 gerbers, firmware, etc.
2021-02-27 update readme for rev.D pcb
2021-04-08 gitignore, gitattributes: add kicad 6 entries
2021-05-10 cpld: implement ps2 keyboard driver (#3)
2021-05-13 enable clamping diodes on some cpld pins just to be safe
2021-05-14 fix reserving RAM for DivMMC (broken in commit 93bcaca)
    [ports.sv]
2021-06-06 update readme - add link to extension board; update roadmap
2021-06-23 magic: fix border when entering menu
    [main.asm]
2021-06-24 magic rom: fix hot switching to +3 mode when basic48 active
    [main.asm]
2021-06-27 magic rom: fix possible crash on start
    [main.asm]
2021-07-05 magic rom: add extension board support
2021-08-15 magic: correctly handle case when there is no magic rom
    This may happens in following cases:
    1. External ROM on ZXBUS is present (ROMCSB signal is active);
    2. JP2/JP3 is installed.
    [main.asm]
2021-08-20 update readme - add dma tested addon
2021-09-05 rom: mute saa1099 on reset
    [main.asm]
2021-09-14 magic rom: fix main_test build
    [main.asm]
2021-09-14 enable divmmc (esxdos OS) by magic rom on poweron; add NO-OS option
2021-09-17 fix hanging of esxdos browser after magic key double press
    [divmmc.sv, main.asm]
2021-09-18 replace 'timings', 'ram', 'plus3' settings with one 'machine' setting
    [ports.sv]
2021-09-18 add more roms
    1. add per-machine romsets
    2. add two alternative 48 basics: Looking Glass ans OpenSE
    3. add ability to boot into ZX80/ZX81 roms by holding 1 or 2 key at
    poweron
2021-09-27 fix #1ffd +3 port
    [ports.sv]
2021-10-01 fix incorrect pallete after enabling ulaplus in menu
    [main.asm]
2021-12-01 replace divmmc no-os mode with zc
    [main.asm]
2022-01-27 update readme: add roadmap for pcb rev.E
2022-02-09 magic rom: fix exiting from pause
    [main.asm]
2022-02-16 fix kempston port decoding - add DF port for some rare games
    [ports.sv]
2022-05-27 fix start button on 8bitdo gamepad
    [main.asm]
2022-10-02 add pcb rev.E
    [sizif512.kicad_sch]
2022-10-02 add pcb rev.E1
    [sizif512.kicad_sch]
2022-10-02 cpld: add support for pcb rev.E
2022-10-02 add rev.E1 gerbers, pdfs, etc.
2023-02-16 add option to remap gamepad button A as UP
2023-04-27 attribute port is now accessible only via #FF address
    this is required to prevent a bus conflict when reading ports from addon connected to zxbus
    [ports.sv]
2023-05-01 correctly handle magic_map on magic button press when DivIDE addon is installed
2023-05-01 fix basic 128 crashes when divmmc is enabled
    [divmmc.sv]
2024-01-18 save extension board configuration
2024-01-28 fix compatibility with some BDI addons
    [ports.sv]
2024-07-21 fix compatibility with some BDI addons (2f83604f)
    [ports.sv]
